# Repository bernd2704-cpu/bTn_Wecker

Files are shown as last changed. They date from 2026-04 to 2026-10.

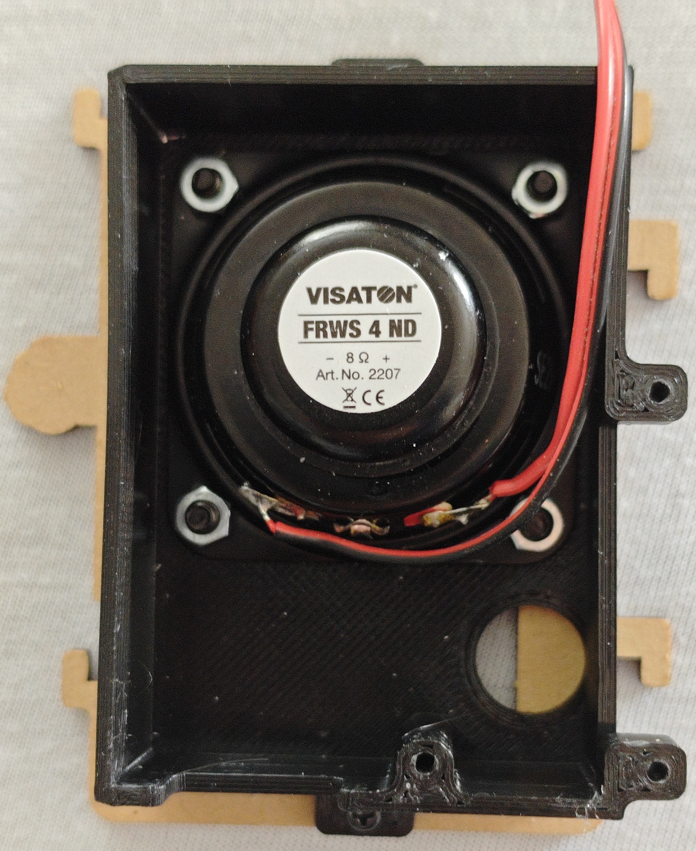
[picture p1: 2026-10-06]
Hardware/Fotos/Lautsprecher-Modul Gehäuse.jpg

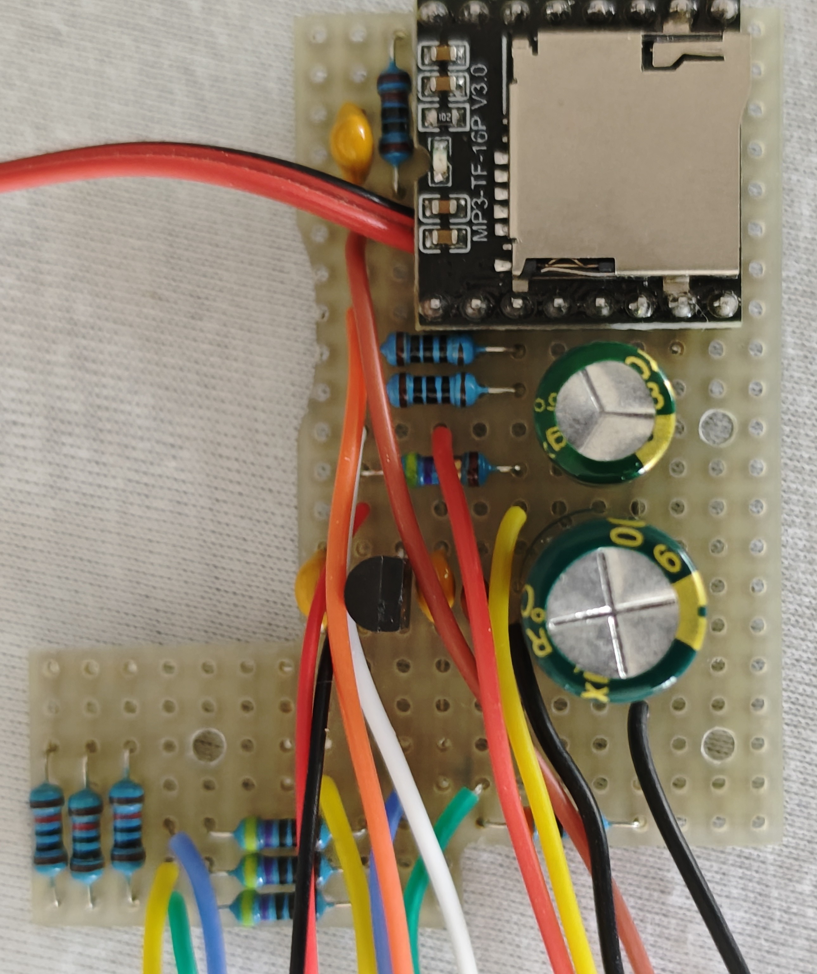
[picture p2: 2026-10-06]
Hardware/Fotos/Lautsprecher-Modul Bestückseite.jpg

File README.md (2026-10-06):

# bTn Wecker – Projektstruktur

## Übersicht

ESP32-basierter Wecker mit OLED-Anzeige, DFPlayer Mini (MP3),
kapazitiven Touch-Pads, FreeRTOS und WiFi/NTP.

Änderungshistorie siehe [CHANGELOG.md](CHANGELOG.md).

---

## Ordnerstruktur

```
bTn_Wecker_Projekt/
│
├── CHANGELOG.md           Änderungshistorie (alle Versionen)
│
├── Hardware/
│   ├── Schaltplan/        Schaltplan und PCB-Layout
│   ├── Stückliste/        Bauteilliste (BOM) – nicht versioniert, siehe unten
│   └── Fotos/             Fotos des Aufbaus
│
├── Software/
│   ├── Firmware_aktuell/  Aktuelle Firmware + Konfiguration
│   ├── Firmware_Versionshistorie/  Alle Vorgängerversionen
│   └── Bibliotheken/      Verwendete Arduino-Bibliotheken (Hinweise)
│
└── Dokumentation/
    ├── Bedienungsanleitung/  Kurzanleitung für den Endnutzer
    ├── Technisch/            Funktionsreferenz
    │   └── Review/           Audit-/Review-Notizen, Arbeitsanweisungen
    └── Diagramme/            State-Machine-Diagramme (Mermaid, .md = maßgeblich; DOC/ = veraltete PPTX/DOCX-Vorlage)
```

**Hinweis:** `Hardware/Stückliste/` enthält Hersteller-Datenblätter und Produktfotos
und ist per `.gitignore` von der Versionierung ausgeschlossen (Urheberrecht) –
lokal weiterhin vorhanden, im Repository nicht enthalten.

---

## Hardware

| Komponente | Beschreibung |
|---|---|
| ESP32 DevKit C V4 | Mikrocontroller, Dual-Core, WiFi |
| SSD1306 OLED | 128×64 px, I2C (0x3C, SDA=21, SCL=19) |
| DFPlayer Mini | MP3-Player, Serial2 (RX=16, TX=17) |
| Touch T0–T4 | GPIO4, GPIO2, GPIO15, GPIO13 |
| Taster S1–S3 | GPIO33, GPIO32, GPIO0 |
| Ausgänge E1–E3 | GPIO27 (Kuckuck) |
| | GPIO25 (Mühlrad) |
| | GPIO26 (Licht) |

---

## Software – Abhängigkeiten

| Bibliothek | Version | Quelle |
|---|---|---|
| ESP32 Arduino Core | 3.3.11 | Espressif |
| SSD1306Wire ESP32-ESP8266 | aktuell | Arduino Library |
| DFRobotDFPlayerMini | aktuell | Arduino Library |
| FreeRTOS | (im Core) | Espressif |

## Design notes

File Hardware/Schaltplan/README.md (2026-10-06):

# Schaltplan

| Datei | Inhalt |
|---|---|
| `Kuckuck-Treiber.md` | Ansteuerung Kuckuck (E1, GPIO27) |
| `LED-Treiber.md` | Ansteuerung LED-Streifen (E3, GPIO26) |
| `Motor-Treiber.md` | Ansteuerung DC-Motor (E2, GPIO25) |
| `Motor-LED-Treiber_Bauteilnotizen.md` | Bauteilauswahl/Dimensionierung zu Motor- und LED-Treiber |
| `DFPlayer-BUSY.md` | BUSY-Signal DFPlayer Mini → GPIO35, Pegelprüfung |
| `Pin_GPIO-Liste.md` | GPIO-Belegung ESP32 (belegt, frei, nicht nutzbar) |

Weitere Schaltplan-Dateien (z.B. KiCad, Eagle, PDF) hier ablegen.

Bauteillisten (BOM) zu den Treibern/Filtern: `Hardware/Stückliste/Stückliste.md`
(z.B. Abschnitt 3 „Motor-Treiber", Abschnitt 4 „DFPlayer-BUSY-Filter").

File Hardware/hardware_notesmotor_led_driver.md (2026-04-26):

# bTn Wecker – Hardware-Erweiterung: LED-Streifen & DC-Motor

## Versorgung
- Betriebsspannung Lastseite: 5V
- ESP32 GPIO-Pegel: 3,3V

---

## MOSFET: IRLML6344TRPBF (für beide Lasten)
- Logic-Level N-Channel, Vgs(th) = 0,4–1,0V → 3,3V GPIO tauglich
- Vds(max) = 20V, Id(max) = 5A
- Rds(on) bei Vgs=2,5V: ~30mΩ → Verlustleistung vernachlässigbar
- Bauform: SOT-23 (SMD)

### Beschaltung (gilt für beide Kanäle)
- Gate:  330Ω Reihenwiderstand zum GPIO
- Gate:  10kΩ Pull-Down nach GND (verhindert floating beim Boot/Reset)

---

## Kanal 1: LED-Streifen – GPIO27 (E3, Licht)
- Versorgung: 5V, Vf = 2,8V, If = 48mA
- Vorwiderstand: 47Ω / 0,25W in Serie (High-Side, zwischen 5V und LED+)
- Spannungsaufteilung: 2,2V am Widerstand, 2,8V an LED
- Freilaufdiode: nicht erforderlich (ohmsche Last)

---

## Kanal 2: DC-Motor – GPIO26 (E2, Wasserrad)
- Versorgung: 5V, Vnenn = 3V, Istall = 200mA
- Vorwiderstand: keiner (Strom ist lastabhängig → PWM statt Widerstand)
- Freilaufdiode: 1N4148, Kathode zu 5V, Anode zu Drain (schnelle Diode, <4ns)
- Entstörkondensator: 100nF Keramik direkt an den Motoranschlüssen

### PWM
```cpp
#define E2  26
ledcAttach(E2, 20000, 8);   // 20kHz, 8-Bit (über Hörschwelle → kein Surren)
ledcWrite(E2, 153);          // 60% Duty → ~3V Mittelwert
```

---

## Hinweise zur Integration
- GPIOs E2 (26) und E3 (27) sind bereits in SysConf_10v05.h definiert
- Stack-Größen und Task-Zuordnung gemäß bestehender SysConf-Konventionen
- Kein vTaskDelay() unter gehaltenem Mutex
- PWM-Initialisierung in setup() vor Task-Start

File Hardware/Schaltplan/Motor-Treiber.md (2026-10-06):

# Motortreiber

```
5V ── MCP1700T-3302E/TO ── 3,3V ──┬─────────┬────── Motor+ ──────┬────────────┐
      (LDO, In/Out je 100nF)      │         │         │          │    Kathode │
                                [100µF]   [100nF]   [Motor]   [10Ω+10nF]    [1N4448]
                                   │         │         │          │      Anode │
                                  GND       GND      Motor- ──────┴────────────┘
                                                       │
                                                       │
                                               Drain ──┘
GPIO25 ────────────────────── [470Ω] ────┬──── Gate             IRLML6344
                                         │     Source ─┐
                                      [10kΩ]           │
                                        │              │
                                       GND            GND
```

Motor liegt an der über MCP1700T-3302E/TO auf 3,3V geregelten Rail (seit Hardware 2v0,
ersetzt die bisherige Direktversorgung mit 5V ohne Regler). Der PWM-Duty-Bereich
0..255 moduliert damit maximal 3,3V statt vormals 5V – voller Regelumfang ohne
Begrenzung nutzbar, keine Überspannung am 3-V-Motor mehr möglich (auch nicht beim
Kickstart-Vollgasimpuls in `motorStart()`).
Freilaufdiode: 1N4448.

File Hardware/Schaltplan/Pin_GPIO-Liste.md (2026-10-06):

# bTn Wecker – GPIO-Belegung

Stand: Firmware 21v02 · Hardware 2v0 · ESP32 Dev Kit C V4

Quelle der Belegung: `SysConf_21v02.h` (Pin-Konstanten) und `CLAUDE.md`.
Bei jeder Pin-Änderung diese Liste mitpflegen.

## Pinbelegung

PIN = Pin-Nummer am ESP32 DevKitC V4 (Draufsicht, USB unten): J2 (linke Leiste) Pin 1–19 von oben nach unten,
J3 (rechte Leiste) Pin 20–38 von unten nach oben. `nc` = nicht beschaltet.

| PIN | GPIO | Konstante | Funktion | Betriebsart | Anmerkung |
| --- | ---- | --- | --- | --- | --- |
| 1 | – | – | 3V3 | Versorgung | |
| 2 | – | – | EN | Reset-Eingang | |
| 3 | 36 | – | nc | – | input-only (VP), keine Pull-ups |
| 4 | 39 | – | nc | – | input-only (VN), keine Pull-ups |
| 5 | 34 | – | nc | – | input-only, keine Pull-ups |
| 6 | 35 | DFPLAYER_BUSY | DFPlayer BUSY | Eingang (input-only) | seit 21v01 (vorher GPIO34), LOW = Wiedergabe |
| 7 | 32 | S2 | Taster S2 (Zugschalter Licht + Mühlrad)  | Eingang, Pull-up | seit 20v28 (vorher GPIO33) |
| 8 | 33 | S1 | Taster S1 (Alarm aus / Kuckuck einmalig) | Eingang, Pull-up | seit 20v28 (vorher GPIO32) |
| 9 | 25 | E2 | Mühlrad / Motor (MOSFET) | PWM 20 kHz, LEDC | seit 20v29 (vorher GPIO26) |
| 10  | 26 | E3 | LED-Licht (MOSFET) | Ausgang digital | seit 20v29 (vorher GPIO27) |
| 11  | 27 | E1 | Kuckuck (MOSFET) | Ausgang digital | seit 20v29 (vorher GPIO25) |
| 12  | 14 | – | nc | – | Touch T6, Ausgabe von PWM-Signal beim Boot |
| 13  | 12 | – | nc | – | Strapping-Pin (Flash-Spannung, MTDI): meiden, kann Boot verhindern |
| 14  | – | – | GND | Masse | |
| 15  | 13 | T4 | Touch T4 | Touch | |
| 16  | 9 | – | nc | – | Flash (SD2), nicht nutzbar |
| 17  | 10 | – | nc | – | Flash (SD3), nicht nutzbar |
| 18  | 11 | – | nc | – | Flash (CMD), nicht nutzbar |
| 19  | – | – | 5V | Versorgung | |
| 20  | 6 | – | nc | – | Flash (CLK), nicht nutzbar |
| 21  | 7 | – | nc | – | Flash (SD0), nicht nutzbar |
| 22  | 8 | – | nc | – | Flash (SD1), nicht nutzbar |
| 23  | 15 | T3 | Touch T3 | Touch | Strapping-Pin (Boot-Log) |
| 24  | 2 | T2 | Touch T2 | Touch | Strapping-Pin, beim Booten nicht HIGH treiben |
| 25  | 0 | S3 | Taster S3 (Info-Seite) | Eingang, Pull-up | Strapping-Pin: beim Reset LOW = Download-Modus |
| 26  | 4 | T0 | Touch T0 | Touch | |
| 27  | 16 | RXD2 | DFPlayer TX | UART2 RX | |
| 28  | 17 | TXD2 | DFPlayer RX | UART2 TX | |
| 29  | 5 | – | nc | – | Strapping-Pin (SDIO-Timing, Boot-Log), nur mit Vorbehalt |
| 30  | 18 | – | nc | – | unkritisch |
| 31  | 19 | OLED_SCL | OLED SCL | I2C | seit 21v02 (vorher GPIO22) |
| 32  | – | – | GND | Masse | |
| 33  | 21 | OLED_SDA | OLED SDA | I2C | |
| 34  | 3 | – | nc | – | RX0 (USB-Seriell / Flashen) |
| 35  | 1 | – | nc | – | TX0 (USB-Seriell / Debug) |
| 36  | 22 | – | nc | – | bis 21v01 OLED SCL |
| 37  | 23 | – | nc | – | unkritisch |
| 38  | – | – | GND | Masse | |

## Hinweise

- GPIO34, 35, 36 und 39 sind nur Eingänge und haben keine internen Pull-ups.
- Strapping-Pins (0, 2, 5, 12, 15) legen beim Reset den Boot-Modus fest. Externe
  Beschaltung darf den Pegel beim Einschalten nicht gegen den Default ziehen.
- I2C läuft über die GPIO-Matrix, deshalb darf SCL auf GPIO19 liegen.

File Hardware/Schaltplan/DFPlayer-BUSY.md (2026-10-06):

# DFPlayer BUSY-Signal

> **Status:** Aktiv ab Hardware 2v0 (verknüpft mit Firmware ab 20v00).
> Der vorherige eingefrorene Stand Hardware 1v0 / Firmware 13v00 hatte
> das BUSY-Signal nicht verdrahtet.

```
DFPlayer Mini                                    ESP32 DEV Kit C V4
BUSY (Pin 16) ──── [1kΩ] ────┬──────────────────── GPIO35
                              │
                           [100nF]
                              │
                             GND
```

## Pegel

DFPlayer Mini VCC = 5V. BUSY-Pin bleibt laut Datenblatt trotzdem auf
3,3V-TTL-Pegel (Modul-interne 3,3V-Logikdomain, unabhängig von VCC):

| Parameter | Wert | Bedingung  |
| --- | --- | --- |
| VOL | max. 0,33 V | VDD = 3,3V |
| VOH | min. 2,7 V | VDD = 3,3V |

Quelle: `Hardware/Stückliste/DFPlayer Mini/DFPlayer Mini Manual.pdf`,
Abschnitt „6. Note*“, sowie AZ-Delivery-Handbuch (bestätigt 3,3V-Logik
auch bei 5V-Versorgung, Serienwiderstand dort nur für RX empfohlen).

Direkter Anschluss an GPIO35 ohne Pegelwandler/Vorwiderstand zulässig:

- VOH min. 2,7V > ESP32 VIH (≈2,45V bei 3,3V-Logik)
- VOL max. 0,33V < ESP32 VIL (≈0,825V bei 3,3V-Logik)

## GPIO35

Input-only (kein internes Pull-up/-down, kein `INPUT_PULLUP` möglich).
Unkritisch, da BUSY aktiv getrieben wird (kein Open-Drain):
LOW = Wiedergabe läuft, HIGH = Pause/Idle.

Bis Firmware 20v32 lag BUSY an GPIO34 (ebenfalls input-only). Ab Firmware 21v01 liegt
BUSY an GPIO35, da dieser Pin im Header-Bereich des Anschlusses liegt und kein
zusätzliches Kabel nötig ist. Elektrisch gleichwertig (beide ADC1, input-only).

## RC-Filter (1kΩ + 100nF)

Firmware liest `dfPlayerBusy()` (GPIO35) an mehreren Stellen als einzelnen,
ungefilterten `digitalRead()` ohne Software-Debounce (anders als Touch-Pads
oder Taster). Ein Hardware-RC-Filter schließt diese Lücke:

- **R = 1 kΩ** (Reihe): konsistent mit Touch-Beschaltung und AZ-Delivery-
  Empfehlung für Serial-Leitungen; Spannungsabfall im stationären Zustand
  vernachlässigbar, da GPIO35-Eingangsleckstrom im nA-Bereich liegt.
- **C = 100 nF** (nach GND, GPIO-seitig): τ = R·C = 100 µs,
  Grenzfrequenz f_c ≈ 1,6 kHz – dämpft kurze EMI-Spitzen/Schaltflanken
  (u.a. vom 20kHz-Motor-PWM an E2, siehe `Motor-Treiber.md`) deutlich.

BUSY wechselt nur beim Start/Ende einer Wiedergabe (Sekundenbereich), nicht
taktend. Die Filter-Zeitkonstante ist damit >1000× schneller als das
schnellste Poll-Intervall der Firmware (200 ms im S1-Handling) – keine
spürbare Verzögerung für die Statusabfrage.

Ladestrom beim Umschalten: ΔV/R ≈ 3,3V / 1kΩ ≈ 3,3 mA – unkritisch für den
aktiv getriebenen DFPlayer-Ausgang (kein Open-Drain).

## Funktion

BUSY dient als Statusabfrage des DFPlayer (Wiedergabe läuft ja/nein),
unabhängig von der seriellen Kommunikation über Serial2 (RX=16, TX=17).
Ab Firmware 20v01/20v02 fließt der Status zusätzlich in Alarm-Polling,
Start-Verifikation (`verifyPlayStarted()`) und S1-Handling ein – siehe
`CHANGELOG.md`.

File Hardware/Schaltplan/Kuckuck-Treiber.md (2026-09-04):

# Kuckuck-Treiber

```
5V ────────┬─────────┬────────── Modul+ 
           │         │             │    
        [100µF]   [100nF]   [Kuckuck-Modul] 
           │         │             │    
          GND       GND          Modul- 
                                   │
                                   │
                           Drain ──┘
GPIO ──── [470Ω] ────┬──── Gate             IRLML6344
                     │     Source ─┐
                   [10kΩ]          │
                     │             │
                    GND           GND
```

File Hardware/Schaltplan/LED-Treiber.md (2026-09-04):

# LED-Treiber

```
5V ──────────── [47Ω / 0,25W]──── LED+
                                   │
                           LED-Streifen (2,8V / 48mA)
                                   │
                                  LED−
                                   │
                           Drain ──┘
GPIO ──── [470Ω] ────┬──── Gate             IRLML6344
                     │     Source ─┐
                   [10kΩ]          │
                     │             │
                    GND           GND

```

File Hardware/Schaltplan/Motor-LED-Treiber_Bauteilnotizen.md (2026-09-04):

# bTn Wecker – Hardware-Erweiterung: LED-Streifen & DC-Motor

Bauteilauswahl und Dimensionierung zu den Schaltplänen [Motor-Treiber.md](Motor-Treiber.md)
und [LED-Treiber.md](LED-Treiber.md).

## Versorgung
- Betriebsspannung Lastseite: 5V
- ESP32 GPIO-Pegel: 3,3V

---

## MOSFET: IRLML6344TRPBF (für beide Lasten)
- Logic-Level N-Channel, Vgs(th) = 0,4–1,0V → 3,3V GPIO tauglich
- Vds(max) = 20V, Id(max) = 5A
- Rds(on) bei Vgs=2,5V: ~30mΩ → Verlustleistung vernachlässigbar
- Bauform: SOT-23 (SMD)

### Beschaltung (gilt für beide Kanäle)
- Gate:  470Ω Reihenwiderstand zum GPIO
- Gate:  10kΩ Pull-Down nach GND (verhindert floating beim Boot/Reset)

---

## Kanal 1: LED-Streifen – GPIO26 (E3, Licht)
- Versorgung: 5V, Vf = 2,8V, If = 48mA
- Vorwiderstand: 47Ω / 0,25W in Serie (High-Side, zwischen 5V und LED+)
- Spannungsaufteilung: 2,2V am Widerstand, 2,8V an LED
- Freilaufdiode: nicht erforderlich (ohmsche Last)

---

## Kanal 2: DC-Motor – GPIO25 (E2, Wasserrad)
- Versorgung: 5V über LDO MCP1700T-3302E/TO auf 3,3V geregelt, Vnenn = 3V, Istall = 200mA
- Vorwiderstand: keiner (Strom ist lastabhängig → PWM statt Widerstand)
- Freilaufdiode: 1N4448, Kathode zu 3,3V-Rail, Anode zu Drain (schnelle Diode, <4ns)
- Entstörkondensator: 100nF Keramik direkt an den Motoranschlüssen

### PWM
```cpp
#define E2  25
ledcAttach(E2, 20000, 8);   // 20kHz, 8-Bit (über Hörschwelle → kein Surren)
ledcWrite(E2, 153);          // 60% Duty → ~2V Mittelwert (aus geregelten 3,3V)
```

### Gelöst: Kickstart-Überspannung (Stand 2026-08-21, Hardware-Änderung)

Bisherige Prüffrage (Stand 2026-08-20): `motorStart()` legt bei Sollwert unter
`MOTOR_PWM_KICK_THRESHOLD` für `MOTOR_PWM_KICK_MS` (150 ms) Duty 255
(`MOTOR_PWM_KICK_DUTY`) an. Solange der Motor direkt an 5V lag, bedeutete
Duty 255 durchgehend 5V statt der Nennspannung 3V (Faktor ~1,67×) – ungeklärt,
da kein Datenblatt für den verbauten Garosa-Getriebemotor 6mm 3V (ASIN
B085NG5ZCY) mit zulässiger Kurzzeit-/Spitzenspannung vorlag.

**Fix:** LDO MCP1700T-3302E/TO regelt die Rail vor dem MOSFET jetzt fest auf
3,3V. PWM schaltet diese geregelte Spannung statt der rohen 5V – Duty 255
bedeutet damit nur noch ~3,3V (Faktor ~1,1× Nennspannung), auch beim
Kickstart-Vollgasimpuls. Der volle PWM-Regelumfang 0..255 ist damit ohne
Begrenzung nutzbar, keine gesonderte Kickstart-Deckelung mehr nötig.

---

## Hinweise zur Integration
- GPIOs E2 (25) und E3 (26) sind in SysConf_*.h definiert (siehe `Software/Firmware_aktuell/`)
  (Belegung seit Firmware 20v29 / Schaltplan Hardware 2v0; vorher E2=26, E3=27)
- Stack-Größen und Task-Zuordnung gemäß bestehender SysConf-Konventionen
- Kein vTaskDelay() unter gehaltenem Mutex
- PWM-Initialisierung in setup() vor Task-Start

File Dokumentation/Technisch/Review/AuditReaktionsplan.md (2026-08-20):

# Audit-Reaktionsplan Firmware 13v00

Quelle: [2026-08-13-Audit-Firmware-13v00.md](2026-08-13-Audit-Firmware-13v00.md)
Zweck: die dortige „Empfohlene Reihenfolge" als abarbeitbare Checkliste mit Status.

## Status-Legende

`[ ]` offen · `[~]` in Arbeit · `[x]` erledigt · `[-]` zurückgestellt

## Zwischenstand 2026-08-18 (Gültigkeitsprüfung gegen 20v03)

Firmware ist ohne Bezug auf diesen Plan direkt von der Audit-Basis 13v00 auf 20v00
(Hardware 2v0, DFPlayer-BUSY-Signal GPIO34) gesprungen. Die 20v00–20v03-Änderungen
dienten der Hardware-Anbindung, haben aber als Nebeneffekt drei Befunde berührt:

- **C1 erledigt** – S1-Handler nutzt bei UART-Timeout jetzt `dfPlayerBusy()` statt
  blind `st = 0` zu setzen (`Wecker_20v03.ino:1752-1755`, seit 20v02). Laufender
  Alarm/Sound wird zuverlässig gestoppt statt fälschlich Kuckuck auszulösen.
- **A3 teilweise entschärft** – `runAlarmMachine()`/`ALARM_RUNNING` beendet den Alarm
  jetzt auch bei dauerhaftem `st == -1`, wenn `dfPlayerIdleDebounced()` das über den
  BUSY-Pin bestätigt (Z. 1474-1475, seit 20v01/20v03). Deckt den Audit-Hauptfall
  (Modul tot/TX-Leitung lose) ab. Der harte Zeit-Deckel `ALARM_MAX_RUN_MS` aus dem
  Fix-Vorschlag fehlt weiterhin – bleibt BUSY selbst dauerhaft LOW hängen, entwaffnet
  sich das Gerät wie beschrieben. Schritt 2 unten daher nur noch mit reduziertem Risiko,
  nicht als erledigt zu werten.
- **C3 nur am Rand berührt** – `verifyPlayStarted()` nutzt BUSY zusätzlich (Z. 1354),
  das hilft aber nur gegen „läuft eigentlich, UART lügt". Der Audit-Kernfall (Datei
  fehlt auf SD, Modul meldet `st == 0`, BUSY bestätigt korrekt „nicht busy" → trotzdem
  als Absturz behandelt, 2 Reboots, danach still) besteht unverändert. Schritt 6 bleibt offen.

Alle übrigen Befunde (A1, A2, A4–A6, B1, B2, C2, C4–C8, D1, D2, E1, E2, E4, E5) wurden
1:1 gegen `Wecker_20v03.ino`/`SysConf_20v03.h` verifiziert und sind unverändert gültig.

## Nicht antasten (Gesamtbild-Fazit des Audits)

Diese fünf Mechanismen funktionieren bereits korrekt und dürfen bei der Umsetzung nicht wegoptimiert werden:

- kein `vTaskDelay()` unter gehaltenem Mutex (Projektregel wird eingehalten)
- Zeitschnappschuss per `localtime_r()` je Task
- `rtosPanic()` bei halb gestartetem Systemzustand
- `ALARM_MAX_RESTARTS` (12v10) / `SERIAL2_DRAIN_MAX_BYTES` (12v11) als Deckel gegen Endlosschleifen
- TWDT-Init vor Task-Start (12v15/12v16)
- ACK-Modus (`player.begin(…, true, true)`) – Deaktivierung war bereits in 13v00 eine Regression

## Umsetzungsreihenfolge

- [x] **1. A5 + A1 gemeinsam** – Umgesetzt in **20v04** (`Wecker_20v04.ino`/`SysConf_20v04.h`).
  `timeValid()`-Gate vor jeder Alarm-/Kuckuck-Auswertung in `alarmTask` (A5); `alarmDue()` ersetzt
  die `sec == 0`-Flanke durch eine tagesbezogene, pegelbasierte Prüfung mit Nachholfenster
  `ALARM_CATCHUP_MIN = 60` (SysConf) – wie in der Review-Notiz gefordert auf 60 statt der
  ursprünglich vorgeschlagenen 15 gesetzt, deckt damit auch die März-DST-Lücke ab (A1). Die
  Fälligkeitsprüfung läuft weiterhin nur in `case ALARM_IDLE`, holt A2 aber automatisch nach, sobald
  `ALARM_RUNNING` endet, da die Tages-Sperre (nicht die Sekunde) das Kriterium ist (A4). Die
  Oktober-Doppelauslösung ist durch `lastCuckooDay`/`lastCuckooHour` statt `lastCuckooMin`
  ausgeschlossen (A6). `lastA1Min`/`lastA2Min` → `lastA1Day`/`lastA2Day`, ebenso in `inputTask`
  (S1-Handler) umgestellt – dort wurde die bisherige Sperren-Rücksetzung nach manuellem Stopp
  **entfernt** (offene Semantikfrage aus der Review-Notiz entschieden: Tages-Sperre bleibt nach
  manuellem Stopp bestehen, sonst würde die pegelbasierte Prüfung im nächsten 500-ms-Tick sofort
  wieder auslösen). `triggerAlarm()` setzt die Tages-Sperre über einen eigenen Zeitstempel erst nach
  erfolgreichem Start – macht A2 wie vorgesehen selbstheilend, ohne zusätzlichen Codepfad.
  Alte Version als `Software/Firmware_Versionshistorie/Wecker_20v03/` archiviert.
  **Noch nicht getestet:** Systemzeit-Sprung-Test (NTP-Attrappe), realer Alarm, DST-Übergänge.
- [x] **2. A3** – Umgesetzt in **20v05** (`Wecker_20v05.ino`/`SysConf_20v05.h`). Neue Konstante
  `ALARM_MAX_RUN_MS` (15 min, SysConf) und eigener Zeitstempel `alarmRunStart` (im Gegensatz zu
  `t_start6`, das als Poll-Timer bei jedem Poll zurückgesetzt wird) begrenzen `ALARM_RUNNING` hart.
  Deckt den Restfall aus der A3-Notiz ab: BUSY-Pin hängt selbst dauerhaft LOW,
  `dfPlayerIdleDebounced()` meldet nie „idle". Bei Auslösung durch die Obergrenze (nicht durch
  reguläres Alarmende) schreibt `runAlarmMachine()` einen `[FEHLER]`-Eintrag mit Laufzeit und
  letztem `playerStatus` ins Web-Log.
  **[x] C1 seit 20v02 erledigt** (`dfPlayerBusy()` statt blindem `st=0` im S1-Handler, Z. 1752-1755).
  Damit sind sowohl C1 als auch A3 vollständig abgedeckt.
  **Noch nicht getestet:** realer Alarm mit simuliertem BUSY-Hänger (Pin dauerhaft LOW erzwingen),
  Web-Log-Eintrag im Fehlerfall.
- [x] **3. B2** – Umgesetzt in **20v06** (`Wecker_20v06.ino`/`SysConf_20v06.h`). `triggerAlarm()`
  setzt den RTC-Merker jetzt direkt nach dem `playerMutex`-Take, vor `playFolder()`/
  `verifyPlayStarted()`, statt erst im bestätigten Fehlerpfad. `runAlarmMachine()` löscht ihn an
  zwei Stellen: sobald der erste Poll `playerStatus > 0` bestätigt (frühestmöglich), zusätzlich
  beim Alarmende (`mp3Finished`/`runTimeExceeded`) als Sicherheitsnetz für einen sehr kurzen Sound,
  der schon vor dem ersten Poll beendet war – ohne diese zweite Stelle bliebe der Merker sonst über
  das Alarmende hinaus gesetzt. Der watchdogTask-Freeze-Fallback (12v12) bleibt unverändert
  bestehen, ist jetzt aber redundant (Sicherheitsnetz für den Fall eines TWDT-Panics vor der
  30-s-Schwelle). Nach Schritt 1 (A1) umgesetzt wie gefordert – der Tages-Guard verhindert den in
  der Review-Notiz beschriebenen verspäteten Zweitalarm.
  **Noch nicht getestet:** gezielter Reset zwischen `playFolder()` und erstem Poll (z.B. `EN`-Taster
  während `ALARM_POLL_MS`-Fenster), Kontrolle dass `setup()` den Alarm danach korrekt nachholt.
- [x] **4. C5 + D1** – Umgesetzt in **20v07** (`Wecker_20v07.ino`/`SysConf_20v07.h`). Clamp von
  `sound1_assigned`/`sound2_assigned` läuft nur noch bei `mp3Count > 0`, sonst `[FEHLER]`-Log statt
  stillem Überschreiben mit 1 (C5). `data.begin()`-Rückgabewert an allen drei Stellen geprüft:
  `setup()` (NVR-Laden), `nvrTask()`, `bumpResetCount()` (D1). `nvrTask()` ruft bei Fehlschlag
  `markSafeChange()` statt den Commit stillschweigend zu verwerfen – nächster Versuch nach
  `NVR_COMMIT_DELAY_MS`. `readNVR()` läuft jetzt unabhängig vom `state`-Flag (die `getX()`-
  Fallbacks liefern beim ersten Boot ohnehin die Compile-Defaults). `webLogMutex`-Initialisierung
  vor das NVR-Laden gezogen, damit ein `data.begin()`-Fehlschlag dort sofort geloggt werden kann.
  **Noch nicht getestet:** `data.begin()`-Fehlschlag lässt sich ohne beschädigten NVS/Flash-Fehler
  kaum real provozieren – Codepfad nur durch Lesen verifiziert, nicht auf Hardware ausgelöst.
- [x] **5. B1 sekundär** – Umgesetzt in **20v08** (`Wecker_20v08.ino`/`SysConf_20v08.h`), abweichend
  vom Audit-Vorschlag. Wie von der Review-Notiz verlangt wurde der reale Worst-Case vorher
  nachgerechnet statt der Schätzwert übernommen: `verifyPlayStarted()` kann bei einem dauerhaft
  nicht antwortenden DFPlayer bis zu ~5,5–6 s blockieren (3× `VERIFY_PLAY_RETRIES`, je
  `VERIFY_PLAY_DELAY_MS` + Mutex-Take bis 200 ms + `readStateDrained()`-Gnadenfrist bei UART-
  Rauschen) – deckt sich mit der im Audit selbst hergeleiteten Summe ("Nicht bestätigt"-Abschnitt).
  Bei den vorgeschlagenen 6000/1000 wäre die Marge dazu praktisch null gewesen: ein nur
  ungewöhnlich langsamer, aber regulärer Alarmversuch hätte den Watchdog fälschlich als Freeze
  werten können – genau das „Fehlalarme erzeugen", vor dem die Notiz warnt. Stattdessen
  `WDG_TIMEOUT_MS`=10000/`WDG_CHECK_MS`=1000 gesetzt: Erkennung spätestens nach ~11 s, ca. 5 s
  Marge über dem berechneten Worst-Case, weiterhin ca. 4 s Marge unter den 15 s des TWDT (Software-
  Watchdog gewinnt jetzt wieder zuerst). Rechnung als Kommentar direkt bei den Konstanten in
  SysConf dokumentiert.
  **Noch nicht getestet:** Feldverhalten mit den neuen Schwellwerten (wie ursprünglich vom Audit
  vorgesehen) – insbesondere ob 10 s/1 s im Alltag Fehlalarme erzeugt oder echte Freezes zuverlässig
  erkennt, lässt sich nur auf der realen Hardware über längere Zeit beobachten.
- [x] **6. C3** – Umgesetzt in **20v09** (`Wecker_20v09.ino`/`SysConf_20v09.h`). `verifyPlayStarted()`
  liefert jetzt `PLAY_OK`/`PLAY_NO_SOUND`/`PLAY_CRASHED` statt `bool` – nur wenn nie eine Antwort
  ankam (`PLAY_CRASHED`), löst `triggerAlarm()` noch `ESP.restart()` aus. Kam mindestens einmal
  `st==0` an (`PLAY_NO_SOUND`), läuft der Alarm in denselben Erfolgspfad wie `PLAY_OK` (Motor/Licht
  an), statt zwei sinnlose Reboots auszulösen und danach still zu bleiben.
  **Zusammen mit A3 verifiziert** wie gefordert: neues Flag `alarmSilentFallback` hält
  `ALARM_RUNNING` bei `PLAY_NO_SOUND` am Laufen, obwohl `playerStatus` dauerhaft `0` meldet – ohne
  dieses Gate hätte `mp3Finished` den Alarm schon beim ersten Poll (5 s) sofort wieder beendet.
  Einziger Ausstieg dann `ALARM_MAX_RUN_MS` (A3) oder S1.
  **Zusätzlich beim Umsetzen entdeckt und mitbehoben:** der S1-Handler entschied bisher
  ausschließlich anhand des (möglicherweise stillen) Playerstatus, ob gestoppt oder Kuckuck
  ausgelöst wird – ein `alarmSilentFallback`-Alarm (playerStatus==0, Motor/Licht laufen aber
  tatsächlich) wäre von S1 NICHT gestoppt worden, sondern hätte versehentlich den Kuckuck
  ausgelöst. Jetzt `if (alarmState == ALARM_RUNNING || st > 0)` – genau die im ursprünglichen
  C1-Fix-Vorschlag des Audits genannte, aber in 20v02 nicht übernommene Bedingung.
  `readStateDrained()` wertet `DFPlayerError`-Frames vor dem Verwerfen aus und loggt den
  Fehlercode – macht „Datei fehlt" von „Modul abgestürzt" im Log erstmals unterscheidbar.
  „Optional auf Datei 1 zurückfallen" aus dem Audit-Fix-Vorschlag bewusst NICHT umgesetzt – hätte
  eine weitere blockierende playFolder()/verify-Runde eingeführt, genau zu der Zeit, in der Schritt 5
  die Watchdog-Marge knapp kalkuliert hat.
  **Noch nicht getestet:** realer Alarm mit absichtlich fehlender Sounddatei (auf Datei-Nummer
  zeigen, die nicht auf der SD-Karte existiert) – prüfen, dass Motor/Licht bis `ALARM_MAX_RUN_MS`
  laufen und S1 den Alarm zuverlässig stoppt.
- [x] **7. C4** – Umgesetzt in **20v10** (`Wecker_20v10.ino`/`SysConf_20v10.h`).
  `player.readFileCountsInFolder(1)` (0x4E) statt `player.readFileCounts()` (0x48) `- 1` – liefert
  die Dateizahl direkt für Ordner 01, kein Rechnen/Raten mehr über die Gesamtzahl aller Ordner.
  Bei Timeout bleibt `mp3Count` auf 0 statt auf den geratenen Fallback 99 – C5 (20v07) sperrt die
  Sound-Auswahl dann korrekt. UI-Auswahl war bereits vorher implizit gesperrt, solange
  `mp3Count == 0` (9v13-Fallback in den Touch-Handlern), keine Änderung dort nötig.
  **Noch nicht getestet:** neuer Bibliotheksaufruf (0x4E) auf realer Hardware – wie vom Reaktionsplan
  vorgesehen einzeln testen (mp3Count-Anzeige nach Boot mit bekannter SD-Karten-Dateizahl in
  Ordner 01 vergleichen).
- [x] **8. C2** – Umgesetzt in **20v11** (`Wecker_20v11.ino`/`SysConf_20v11.h`), zuletzt und
  ausdrücklich isoliert wie gefordert. Vor der Änderung Rollback-Punkt als Git-Tag `vor-C2-20v10`
  auf dem Stand nach Schritt 7 gesetzt (statt der ursprünglich vorgesehenen „Schritte 1–3" – zum
  Zeitpunkt der Umsetzung waren bereits alle Schritte 1–7 erledigt, der Tag markiert den
  tatsächlich unmittelbar vorherigen stabilen Stand). Gemeinsame fortschrittsbasierte Drain-
  Schleife `drainSerial2Progress()` ersetzt sowohl den Rückgabewert-Abbruch in `drainSerial2Pre()`
  als auch das Fehlen eines Vorab-Drains in `readStateDrained()` (jetzt VOR der eigenen
  `player.readState()`-Abfrage aufgerufen). Endlosschleife laut Review-Notiz ausgeschlossen: der
  äußere Schleifenkopf verlangt bereits `Serial2.available() >= DFPLAYER_RECEIVED_LENGTH`,
  `SERIAL2_DRAIN_MAX_BYTES` bleibt zusätzlich als harte Grenze.
  **Noch nicht getestet – das im Audit vorgesehene Testprotokoll steht komplett aus:** Kaltstart,
  Startsound, Sound-Vorschau beider Alarme, Lautstärkeänderung, echter Alarm, S1-Stopp, Alarm mit
  gezogener SD-Karte – jeweils mit offenem Web-Log, Blick auf „Serial2 Restbytes". Dieser Bereich
  hat bereits dreimal (12v09–12v14) Regressionen erzeugt – vor dem Einsatz als Wecker unbedingt
  auf echter Hardware durchspielen; bei Auffälligkeiten steht `git checkout vor-C2-20v10` als
  Rückfallebene bereit.
- [x] **9. E5** – Gemessen (2026-08-18, Bernd): Motor liegt direkt an 5V, kein Spannungsregler.
  Firmware/SysConf-Kommentare (`MOTOR_PWM_DUTY`=153 ≙ 60 % von 5V ≈ 3V) sowie
  `Motor-LED-Treiber_Bauteilnotizen.md` waren bereits korrekt und unverändert richtig – die
  Falschdarstellung lag ausschließlich in `Hardware/Schaltplan/Motor-Treiber.md` (AMS1117-3.3-LDO
  im Schaltplan) und `Hardware/Stückliste/Stückliste.md` (AMS1117-Zeile). Beide korrigiert: LDO aus
  dem Schaltplan entfernt (Motor jetzt direkt an 5V gezeichnet), AMS1117-Zeile aus der Stückliste
  gestrichen. Diodentyp-Widerspruch ebenfalls geklärt: real verbaut ist `1N4148` (wie SysConf und
  Bauteilnotizen schon sagten) – Schaltplan, Stückliste und `CLAUDE.md` (bisher `1N4448`)
  entsprechend korrigiert.
- [x] **10. Kleinere Punkte** – Umgesetzt in **20v12** (`Wecker_20v12.ino`/`SysConf_20v12.h`), bis
  auf zwei bewusst zurückgestellte Punkte:
  - [x] E1: `touchTask` erzwingt einen Reset auf `TS_IDLE` inkl. Baseline-Neuerfassung, wenn ein
    Pad länger als `TOUCH_MAX_HOLD_MS` (30 s) klemmt (`[WARNUNG]`-Log). `triggerAlarm()` sendet vor
    jedem Alarm `player.volume()` mit Untergrenze `ALARM_MIN_VOL` (10), unabhängig vom zuletzt
    gesendeten Wert – `vol` selbst bleibt unverändert.
  - [-] E2: **Zurückgestellt auf Nutzerwunsch** – S3 bleibt bewusst auf GPIO0, weil der vorhandene
    interne Boot-Taster des ESP32 DevKit C V4 dafür genutzt wird (kein zusätzliches Bauteil nötig).
  - [x] C6: Neues Flag `alarmCancelRequested`, gesetzt über `requestAlarmCancelIfActive()` in S1,
    Sound-Vorschau-Stopp und Funktionswahl-Menü, bevor deren `player.stop()` einen laufenden
    Alarmversuch treffen könnte. `verifyPlayStarted()` liefert dann `PLAY_CANCELLED` statt
    `PLAY_CRASHED` – `triggerAlarm()` bricht sauber ab (Tages-Sperre trotzdem via
    `lockAlarmDayGuard()` gesetzt) statt neu zu starten oder `alarmSilentFallback` zu aktivieren.
  - [x] C7: `onClock()` (T3/T4) und `checkboxSound()` ändern `vol`/`sound*_assigned`, Anzeige und
    `markSafeChange()` jetzt erst nach erfolgreichem `playerMutex`-Take; Fehlschlag als `[FEHLER]`
    geloggt statt stillschweigend ignoriert.
  - [x] D2: `html.reserve()` von 8192 auf 12288 angehoben (Audit-Minimalvorschlag statt
    vollständigem Umbau auf `sendContent()`-Streaming); `/log`-Handler reserviert jetzt ebenfalls
    (`out.reserve(6144)`, vorher gar nicht).
  - [-] E4: **Zurückgestellt auf Nutzerwunsch** – auf die Bestätigungsabfrage für T3
    (WLAN-Zugangsdaten löschen) wird bewusst verzichtet.
  **Noch nicht getestet:** klemmendes Touch-Pad simulieren (Finger dauerhaft auflegen, 30 s warten,
  Web-Log auf `[WARNUNG]` prüfen); Alarm bei vol=0 auslösen und Lautstärke am Lautsprecher prüfen;
  S1/Vorschau-Stopp exakt im Verifikationsfenster (schwer gezielt reproduzierbar, am ehesten durch
  wiederholte Alarme mit sofortigem S1-Druck); `/`- und `/log`-Seite nach längerer Laufzeit mit
  vollem Ringpuffer aufrufen.
- [x] **11. Zweizeiler aus „Ungeprüft geblieben"** – Umgesetzt in **20v13**
  (`Wecker_20v13.ino`/`SysConf_20v13.h`), letzter Punkt der Umsetzungsreihenfolge.
  - [x] Rückgabewerte von `esp_task_wdt_add(NULL)` (in `inputTask`/`displayTask`/`alarmTask`) sowie
    `esp_task_wdt_init()`/`esp_task_wdt_reconfigure()` in `setup()` werden jetzt ausgewertet;
    Fehlschlag wird als `[FEHLER]` geloggt statt „[TWDT] Hardware Watchdog aktiv" blind zu behaupten.
  - [x] `webLog("[NTP] Synchronisation OK")` und `snapTimeStr(snapNtpTime, …)` laufen jetzt nur noch
    bei tatsächlichem NTP-Erfolg (`ntpTimedOut`-Flag), nicht mehr unbedingt nach der Warteschleife.
  **Noch nicht getestet:** beide Fehlerpfade sind auf reeller Hardware kaum gezielt provozierbar
  (TWDT-Anmeldefehler, NTP-Timeout erfordert getrennten Router/DNS-Ausfall bei sonst funktionierendem
  WLAN) – nur durch Lesen verifiziert.

Damit ist die Umsetzungsreihenfolge des Audit-Reaktionsplans (Schritte 1–11) vollständig
abgearbeitet. Offen bleiben nur noch die nie gegengeprüften Punkte unter „Offene Prüfpunkte" unten.

## Vor dem produktiven Einsatz: Hardware-Test erforderlich

Ein Großteil der Änderungen aus den Schritten 1–11 (Firmware 13v00 → 20v13) ist bisher **nur
gelesen, nie auf echter Hardware getestet** – siehe die „Noch nicht getestet"-Hinweise bei jedem
einzelnen Schritt oben. Besonders die sicherheitskritischen Pfade aus Schritt 1 (A1/A5,
Alarmfälligkeit), Schritt 3 (B2, Crash-Recovery), Schritt 6 (C3, stummer Alarm) und Schritt 8 (C2,
zuletzt und ausdrücklich isoliert wegen dreifacher Regressionshistorie 12v09–12v14) verändern das
Alarmverhalten selbst.

**Vor dem Einsatz als Wecker mindestens folgendes durchspielen:**

1. Kompletter Testdurchlauf aus Schritt 8: Kaltstart, Startsound, Sound-Vorschau beider Alarme,
   Lautstärkeänderung, echter Alarm, S1-Stopp, Alarm mit gezogener SD-Karte – jeweils mit offenem
   Web-Log, Blick auf „Serial2 Restbytes".
2. Alarm mit absichtlich fehlender Sounddatei auslösen (Schritt 6) – sicherheitskritischster Pfad:
   prüfen, dass Motor/Licht angehen und S1 den Alarm zuverlässig stoppt.
3. Systemzeit-Sprung-Test (Schritt 1, z.B. NTP-Server-Attrappe) sowie ein regulärer, echter Alarm.

Bei Auffälligkeiten steht der Git-Tag `vor-C2-20v10` als Rollback-Punkt unmittelbar vor dem
riskantesten Einzelschritt (C2) bereit.

## Bewusst nicht umgesetzt

- **DFPlayer-Library-Patch** (`sendStack()`/`available()`): Audit hat die vermutete Ursache
  eines 15-s-TWDT-Hängers widerlegt (rechnerisch max. ~5,5–6 s). 12v14-Rücknahme des Patches war
  richtig, kein erneuter Eingriff in `DFRobotDFPlayerMini.cpp`.
- **E3** (Kuckuck-Treiber ohne Freilaufdiode): Energie im Abschaltfall liegt laut Rechnung
  Größenordnungen unter der MOSFET-EAS-Grenze bei ~20 Schaltvorgängen/Tag. Diode als gute Praxis
  optional, nicht dringend.

## Offene Prüfpunkte (im Audit selbst ungeprüft)

Aus Kapazitätsgründen nicht gegengeprüft, bei Gelegenheit einordnen:

- `STACK_WATCHDOG = 1344` im Fehlerzweig (webLogf + vsnprintf + 3× SSD1306) – Stack-Reserve fraglich
- Race auf `motorRunning`/E2 zwischen Kickstart und `/motor`-HTTP-Handler
- ungeschützte Snapshot-Strings im HTTP-Handler
- `nvs_flash_erase()` beim Werksreset ohne Anhalten des `nvrTask`
- `WEB.h`/WiFi-Konfigurator: keine Eingabevalidierung der POST-Parameter geprüft
- UI-State-Machine (`uiDispatch`, `menu()`) nur dort gelesen, wo sie Player-/NVR-Zustand berührt
- Touch-Kalibrierung nicht auf Fehlauslösung durch Netzbrummen geprüft
- Heap-Fragmentierung über Wochen Laufzeit (WebServer/lwIP) nicht gemessen
- Motor-Kickstart (`MOTOR_PWM_KICK_DUTY = 255`, `motorStart()`, Wecker_20v19.ino:1503-1508) legt für
  `MOTOR_PWM_KICK_MS` (150 ms) die volle 5V-Schienenspannung an den 3V-Getriebemotor an (Duty 100 %
  bei 20 kHz = durchgehend 5V, keine PWM-Mittelung). Kein Datenblatt für den verbauten Motor
  (Garosa-Getriebemotor 6mm 3V, Stückliste) mit einer zulässigen Kurzzeit-/Spitzenspannung geprüft –
  nur `Vnenn=3V, Istall=200mA` dokumentiert (`Motor-LED-Treiber_Bauteilnotizen.md`). Verstößt gegen
  die Projektregel „alle Grenzwerte explizit gegen Datenblatt prüfen". Siehe offene Prüffrage +
  möglicher Fix in `Motor-LED-Treiber_Bauteilnotizen.md`.

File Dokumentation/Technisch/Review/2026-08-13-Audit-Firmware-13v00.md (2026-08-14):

# Audit Firmware 13v00 – Zuverlässigkeit

## Gesamtbild

Die Firmware ist handwerklich deutlich besser als der Durchschnitt vergleichbarer Arduino-Projekte: die Projektregel „kein `vTaskDelay()` unter Mutex" wird in allen geprüften Pfaden tatsächlich eingehalten (`verifyPlayStarted()` Z. 1320, S1-Retry Z. 1715, ALARM_RUNNING-Poll Z. 1426/1428), der Zeitschnappschuss per `localtime_r()` je Task (Z. 1955-1961) eliminiert eine reale Race gegen `displayTask`, `rtosPanic()` verhindert einen halb gestarteten Systemzustand, `ALARM_MAX_RESTARTS` (12v10) und `SERIAL2_DRAIN_MAX_BYTES` (12v11) sind genau die Deckel, die Endlos-Neustartschleifen bzw. Endlos-Drains verhindern, und die TWDT-Initialisierung vor dem Task-Start (12v15/12v16) ist korrekt und richtig begründet. **Diese fünf Mechanismen bitte nicht wegoptimieren** – ebenso wenig den ACK-Modus (`player.begin(…, true, true)`, Z. 2485), dessen Deaktivierung in 13v00 bereits eine Regression war.

Das Restrisiko liegt nicht in der Nebenläufigkeit, sondern in drei strukturellen Punkten: **(A)** die Alarm-Fälligkeit ist eine reine Flanke auf `sec == 0` im Zustand `ALARM_IDLE` – jedes verpasste Ereignis (Zeitsprung, Reboot, blockierter Tick, laufender Vor-Alarm) löscht den Alarm des Tages ersatzlos und ohne einen einzigen Log-Eintrag; **(B)** die gesamte Absturz-Wiederherstellung hängt an `rtcRetryMagic`, das ausschließlich im DFPlayer-Fehlerpfad gesetzt wird – der 12v12-Ersatzalarm ist wegen `WDT_HARDWARE_MS (15 s) < WDG_TIMEOUT_MS (30 s)` faktisch toter Code; **(C)** der DFPlayer-Status ist die einzige Entscheidungsgrundlage für Stopp, Erfolg und Zustandswechsel, wobei `st == 0` (Modul antwortet, ist gestoppt) und `st == -1` (Modul tot) an mehreren Stellen bewusst verschieden, an anderen fälschlich gleich behandelt werden.

Kein einziger dieser Pfade schreibt beim Scheitern eine `[FEHLER]`-Zeile ins Web-Log. Der schlimmste Ausgang – Wecker bleibt stumm – ist damit nicht nur möglich, sondern auch nachträglich nicht diagnostizierbar.

---

## Befunde

### Ursachengruppe A – Alarmfälligkeit ist eine Flanke ohne Nachholung

Die Befunde A1–A6 haben genau eine Wurzel: `runAlarmMachine()` prüft `a1_*`/`a2_*` nur im `case ALARM_IDLE` und nur bei exakt `sec == 0`, die Wiederholsperre ist eine reine Minutenzahl ohne Datum. Ein einziger Umbau (pegel- statt flankenbasierte, tagesbezogene Fälligkeitsprüfung außerhalb des `switch`, plus Zeit-Gültigkeitsgate und Maximallaufzeit) behebt A1, A2, A4, A5 und A6 gemeinsam. Einzeln zu flicken lohnt hier nicht.

---

### [Kritisch] A1 – Alarm nur bei exakt `sec == 0`, kein Nachholmechanismus

- **Ort:** `Software/Firmware_aktuell/Wecker_13v00.ino:1409` und `:1414` (`runAlarmMachine`)
- **Was passiert:** Bedingung ist `a1_on && sec == 0 && min == a1_min && hour == a1_hour && min != lastA1Min`. Wird diese eine Sekunde nicht beobachtet, existiert kein Codepfad, der eine bereits verstrichene Alarmminute nachprüft. `lastA1Min`/`lastA2Min` (Z. 1439-1440) sperren nur Wiederholungen, sie holen nichts nach.
- **Wann es passiert:** (a) **Harter NTP-Zeitsprung** – die Hardware hat keine gepufferte RTC. Nach Stromausfall bootet das Gerät mit Epoch 0 (lokal 01:00). `configTime(0, 0, MY_NTP_SERVER)` (Z. 2371) lässt den Sync-Modus auf dem ESP-IDF-Default (`SNTP_SYNC_MODE_IMMED`, harter `settimeofday`-Sprung). Kommt der Router/DSL erst um 06:02 hoch, springt die Uhr in einem Schritt von 1970 auf 06:02 – die Sekunde 06:00:00 existiert nie, Alarm 1 fällt aus. Dieser Fall ist nach jedem nächtlichen Stromausfall der Normalfall, nicht der Ausnahmefall. (b) **Reboot im Alarmfenster** – Brownout/TWDT-Panic/`watchdogTask`-Restart um 05:59:45; `setup()` braucht minimal ~14 s (3000 ms Z. 2325 + 2000 ms Z. 2329 + `player.begin()`-Reset + 4000 ms Startsound Z. 2510), mit WiFi-/NTP-/MP3-Timeouts bis ~80 s. (c) **Märzumstellung** – 01:59:59 → 03:00:00, ein Alarm auf 02:30 existiert an diesem Tag nicht.
- **Warum es zählt:** Genau der Worst Case des Geräts: stiller, unprotokollierter Alarmausfall nach einem Alltagsereignis. Der Kommentar Z. 1403-1407 unterstellt, ein Folge-Tick liege noch in derselben Sekunde 0 – bei 500-ms-Takt (Z. 1965) und 200 ms Mutex-Timeout stimmt das nur in etwa 60 % der Phasenlagen.
- **Fix:** Fälligkeit tagesbezogen und als Pegel prüfen, mit begrenztem Nachholfenster:

```cpp
static uint16_t lastA1Day = 0xFFFF;                                                      // tm_yday des zuletzt behandelten Auslösetags
static uint16_t lastA2Day = 0xFFFF;

static bool alarmDue(bool on, uint8_t h, uint8_t m,
                     uint8_t hour, uint8_t min, uint16_t yday, uint16_t lastDay) {
  if (!on || yday == lastDay) { return false; }
  int16_t diff = (int16_t)(hour * 60 + min) - (int16_t)(h * 60 + m);
  return (diff >= 0 && diff <= ALARM_CATCHUP_MIN);                                       // Nachholfenster fängt Zeitsprünge und Reboots ab
}
```
  `ALARM_CATCHUP_MIN` (z.B. 15) neu in SysConf. `lastA1Day`/`lastA2Day` in `triggerAlarm()` statt `lastA1Min` setzen; die Minutensperren entfallen dadurch ersatzlos, ebenso ihr Reset in Z. 1439-1440. Analog `runCuckooMachine()` (Z. 1456) – dort genügt eine Sperre auf `hour` statt `min`.
- **Sicherheit des Befunds:** Bestätigt, beide Prüfer unabhängig, alle Zeilenangaben verifiziert. Offene Annahme: SNTP-Default-Sync-Modus (ESP-IDF-Kernverhalten, kein Bibliotheksinternum).
- **Notiz (Review 2026-08-14):** `ALARM_CATCHUP_MIN = 15` ist zu knapp für den in diesem Befund selbst genannten Auslöser (c) Märzumstellung: beim Sprung 01:59:59 → 03:00:00 fehlt eine Alarmminute um bis zu 60 Minuten (Alarm 02:00 → Diff 60, Alarm 02:44 → Diff 16), beide über dem Beispielwert. Der Wert muss entweder auf ≥60 angehoben oder die DST-Vorwärtslücke separat behandelt werden – sonst holt der eigene Fix genau den Fall nicht nach, den er laut Begründung mit abdecken soll. Zusätzlich: `lastA1Min`/`lastA2Min` werden nicht nur hier verwendet, sondern auch im S1-Handler (`inputTask`, Z. 1730-1732) und `lastCuckooMin` in Z. 1744 zurückgesetzt/gesetzt – der Umbau auf `lastA*Day` muss diese Stelle einschließen (Semantikfrage: soll ein manuell gestoppter Alarm für den Rest des Tages gesperrt bleiben?), sonst bleibt dort ein inkonsistenter Mischzustand aus Minuten- und Tages-Logik stehen. Diese Stelle überschneidet sich mit C1 und sollte nicht getrennt umgesetzt werden.

---

### [Kritisch] A2 – `triggerAlarm()`: fehlgeschlagener `playerMutex`-Take lässt den Alarm still ausfallen

- **Ort:** `Software/Firmware_aktuell/Wecker_13v00.ino:1347` (`triggerAlarm`)
- **Was passiert:** `if (xSemaphoreTake(playerMutex, pdMS_TO_TICKS(200)) == pdTRUE) { … }` hat keinen `else`-Zweig; die Funktion endet Z. 1395 stillschweigend. Kein Ton, kein Web-Log, kein `rtcRetryMagic`, kein `alarmTriggerInFlight`, kein Zustandswechsel. Da `alarmTriggerInFlight` false bleibt, greift auch der `watchdogTask`-Ersatzalarm (Z. 2070) nicht.
- **Wann es passiert:** Ein konkurrierender `playerMutex`-Halter hält die Sperre in der Alarmsekunde über 200 ms: S1-Handler (Z. 1703/1716/1723), Sound-Vorschau (Z. 562/570/583/591), Lautstärke (Z. 959/974), Menüseite 5 (Z. 672). Weil ein Fehlversuch selbst 200 ms kostet und der Folge-Tick 700 ms später liegt, gibt es in rund 40 % der Phasenlagen nur einen einzigen Versuch – ein einzelner Timeout genügt.
- **Warum es zählt:** Alarm fällt für den Tag aus, ohne eine einzige Log-Zeile. Der zweite Prüfer stuft das auf „mittel" herab, weil ein Halter >200 ms einen trägen DFPlayer voraussetzt und die Kollision Bedienung in der Alarmsekunde erfordert. Beides stimmt – die Folgenlosigkeit im Log macht den Fall trotzdem inakzeptabel.
- **Fix:** Fehlschlag protokollieren und den Alarmwunsch vom Player-Zugriff entkoppeln. Mit dem A1-Fix genügt: bei Take-Fehlschlag `webLogf("[FEHLER] …")` und **kein** Setzen von `lastA*Day` – das Nachholfenster sorgt dann automatisch für den Wiederholversuch im nächsten Tick. `alarmTriggerInFlight` zusätzlich **vor** dem Take setzen, damit der Freeze-Fallback greift.
- **Sicherheit des Befunds:** Bestätigt (Codestruktur eindeutig). Umstritten ist nur die Häufigkeit; die für lange Haltezeiten maßgebliche Blockierdauer von `player.readState()` ist ohne Bibliotheksquellen nicht hart belegbar.
- **Notiz (Review 2026-08-14):** Der Fix verlangt, `alarmTriggerInFlight` vor dem Take zu setzen, damit der Watchdog-Freeze-Fallback greift (Z. 2070-2078) – dieser Fallback ist laut B1 aber bis zum B1-Fix toter Code (TWDT feuert immer zuerst). D.h. dieser Teil von A2 ist real erst wirksam, nachdem B1 (oder mindestens dessen primäre Maßnahme B2) umgesetzt ist. Das Web-Log bei Take-Fehlschlag und der Verzicht auf `lastA*Day`-Setzen wirken dagegen unabhängig davon sofort.

---

### [Kritisch] A3 – `ALARM_RUNNING` endet bei dauerhaftem `st == -1` nie: Gerät bleibt für immer entwaffnet

- **Ort:** `Software/Firmware_aktuell/Wecker_13v00.ino:1436` (`runAlarmMachine`)
- **Was passiert:** Einziger Ausstieg ist `playerStatus == 0`. `t_start6` wird bei jedem Poll neu gesetzt (Z. 1435) und ist damit reiner Poll-Timer, keine Laufzeitgrenze. Liefert `readStateDrained()` dauerhaft -1, bleibt der Zustand für immer stehen. Da `a1_*`/`a2_*` ausschließlich im `case ALARM_IDLE` geprüft werden, wird ab diesem Moment **kein einziger weiterer Alarm mehr ausgelöst**.
- **Wann es passiert:** Alarm startet, `verifyPlayStarted()` bestätigt `st > 0` → `ALARM_RUNNING`. Danach fällt die DFPlayer-Antwort aus (TX-Leitung lose, Modul-Brownout beim Motoranlauf, SD-Karte gezogen). Motor (E2) und Licht (E3) laufen unbegrenzt weiter. S1 rettet nicht: die Retry-Schleife Z. 1710-1721 erzwingt nach 200 ms `st = 0`, landet damit im `else`-Zweig (Kuckuck, Z. 1733-1745) und fasst weder `alarmState` noch E2/E3 an. Der 30-min-Deckel Z. 1930 hängt an `S2_SW` und greift nicht. Der `watchdogTask` greift nicht, weil `alarmTask` normal weiterläuft (Kommentar Z. 2044 sagt das ausdrücklich).
- **Warum es zählt:** Der Wecker ist danach dauerhaft tot, ohne Fehlermeldung, und nur ein Stromausfall/Reset stellt ihn her – ausgerechnet der Neustart, der wegen `player.begin(…, doReset=true)` das hängende Modul geheilt hätte, findet nicht statt. Schaltet der Nutzer die sichtbare Last per S2 ab, verschwindet auch noch das Symptom. Die 12v05-Historie (SysConf Z. 180-182) benennt genau dieses Risiko; behoben wurde damals nur der Startcheck.
- **Fix:** Harte Obergrenze in `ALARM_RUNNING`, mit eigenem Zeitstempel (nicht `t_start6`, der wird zurückgesetzt):

```cpp
if (playerStatus == 0 || millis() - alarmRunStart >= ALARM_MAX_RUN_MS) {
  if (playerStatus != 0) {
    webLogf("[FEHLER] Alarm ohne DFPlayer-Rueckmeldung nach %lu ms beendet",
            (unsigned long)(millis() - alarmRunStart));
  }
  motorStop();
  …
}
```
  `alarmRunStart = millis()` in `triggerAlarm()` neben Z. 1391 setzen, `ALARM_MAX_RUN_MS` (10–15 min) in SysConf. Zusätzlich S1 unabhängig vom Playerstatus wirken lassen, solange `alarmState == ALARM_RUNNING` (siehe C1).
- **Sicherheit des Befunds:** Bestätigt, beide Prüfer, alle Zeilen verifiziert.

---

### [Hoch] A4 – Alarm 2 wird während laufendem Alarm 1 nie geprüft

- **Ort:** `Software/Firmware_aktuell/Wecker_13v00.ino:1420` (`runAlarmMachine`, `case ALARM_RUNNING`)
- **Was passiert:** Die Fälligkeitsprüfung liegt komplett im `case ALARM_IDLE`. Steht die Maschine zur Fälligkeitszeit von A2 in `ALARM_RUNNING`, wird A2 in diesem Tick nicht geprüft – und die `sec == 0`-Flanke kommt nicht wieder.
- **Wann es passiert:** A1 = 06:00, A2 = 06:05 als Sicherheitsnetz, A1-Titel länger als 5 Minuten (der Nutzer hat ihn verschlafen). Endet A1 um 06:07, werden die Sperren zurückgesetzt – 06:05:00 ist längst vorbei, A2 fällt ersatzlos aus. In Kombination mit A3 fallen alle Folgealarme aus.
- **Warum es zählt:** Genau der Fall, für den A2 konfiguriert wurde, versagt. (Ein Prüfer stuft auf „mittel", weil das Gerät zur Fälligkeitssekunde nicht stumm ist und die Konstellation überlappende Alarmzeiten voraussetzt – korrekt, ändert aber nichts daran, dass das Sicherheitsnetz reißt.)
- **Fix:** Mit dem A1-Fix erledigt: `alarmDue()` in jedem Tick auswerten, unabhängig vom Zustand. Bei Treffer während `ALARM_RUNNING` den fälligen Alarm merken und beim Übergang nach `ALARM_IDLE` nachziehen (das Nachholfenster begrenzt das automatisch).
- **Sicherheit des Befunds:** Bestätigt. Die im Ursprungsbefund genannte Begründung über `ALARM_POLL_MS` ist falsch (das Ende wird alle 5 s geprüft, nicht erst nach Minuten) – am Mechanismus ändert das nichts.

---

### [Hoch] A5 – Alarm und Kuckuck laufen ungeprüft auf der ungestellten 1970-Uhr

- **Ort:** `Software/Firmware_aktuell/Wecker_13v00.ino:1962` (`alarmTask`)
- **Was passiert:** Der Zeitschnappschuss geht ohne jede Gültigkeitsprüfung an beide State Machines. Ohne NTP steht die Systemzeit auf Epoch 0, mit `MY_TZ` also 01:00:00 ab Bootzeitpunkt. Das Projekt kennt beide Prüfungen (`tm_year < 71` Z. 2423, `t > 1700000000UL` Z. 300), benutzt sie im Alarmpfad aber nicht.
- **Wann es passiert:** Stromausfall, WLAN kommt nicht zurück (falsches PSK, defekter Router). WiFi-Timeout nach 30 s, der NTP-Block (nur unter `if (wifiConnected)`, Z. 2403) wird übersprungen. Nach 5 h Uptime erreicht die Fake-Uhr 06:00:00 und löst Alarm 1 samt Motor und Licht mitten am Tag aus; ab dann schlägt bei aktiviertem Kuckuck stündlich der Magnet 7,5 s.
- **Warum es zählt:** Fehlalarm zu beliebiger Tageszeit. Wichtiger noch: **ohne dieses Gate ist der A1-Fix gefährlich** – eine pegelbasierte Prüfung würde auf der 1970-Uhr sofort nach Boot feuern. Das Gate ist Voraussetzung, nicht Zusatz.
- **Fix:**

```cpp
static inline bool timeValid() { return time(nullptr) > 1700000000UL; }
```
  In `alarmTask` vor Z. 1962: `if (!timeValid()) { wdg_alarmTask = millis(); vTaskDelay(…); continue; }`. Optional die Uhr im Display als `--:--:--` zeigen, solange ungültig.
- **Sicherheit des Befunds:** Bestätigt. Ein Prüfer stuft auf „mittel", weil das Display „01.01.1970" zeigt und `cuckoo_on` per Default aus ist – beides zutreffend.

---

### [Mittel] A6 – Oktober-Zeitumstellung: Alarm zwischen 02:00 und 02:59 löst zweimal aus

- **Ort:** `Software/Firmware_aktuell/Wecker_13v00.ino:1439` (`runAlarmMachine`)
- **Was passiert:** `lastA1Min`/`lastA2Min` sind reine Minutenzahlen ohne Datumsbezug und werden beim Titelende auf 0xFF zurückgesetzt.
- **Wann es passiert:** Letzter Sonntag im Oktober, `MY_TZ = "CET-1CEST,M3.5.0/02,M10.5.0/03"`: die Ortszeit durchläuft 02:00–02:59 zweimal. Ein Alarm auf 02:30 startet beim zweiten Durchlauf erneut. Analog der Kuckuck bei 02:00 (`lastCuckooMin`, Z. 1467/1478).
- **Warum es zählt:** Zusätzlicher Nachtalarm, einmal jährlich, nur bei Alarmzeiten in dieser Stunde. Störend, nicht kritisch.
- **Fix:** Mit dem A1-Fix erledigt (`lastA*Day` statt `lastA*Min`).
- **Sicherheit des Befunds:** Bestätigt, beide Prüfer.

---

### Ursachengruppe B – Crash-Recovery hängt an einem Merker, der zu selten und zu früh gelöscht wird

`rtcRetryMagic` ist der einzige Zustand, der einen Reset übersteht. Er wird nur im DFPlayer-Fehlerpfad gesetzt (Z. 1378-1382) und im Watchdog-Freeze-Zweig (Z. 2075), der praktisch nie erreicht wird. Jeder andere Reset – Power-On, Brownout, TWDT-Panic, `watchdogTask`-Restart wegen input-/displayTask-Freeze – verliert einen laufenden oder gerade startenden Alarm ersatzlos.

---

### [Hoch] B1 – Hardware-TWDT (15 s) feuert immer vor dem App-Watchdog (30 s): Ersatzalarm-Fallback ist toter Code

- **Ort:** `Software/Firmware_aktuell/Wecker_13v00.ino:2070` (`watchdogTask`), Konstanten `SysConf_13v00.h:423-425`
- **Was passiert:** In allen drei überwachten Tasks liegen `esp_task_wdt_reset()` und das `wdg_*`-Alive-Signal in derselben Schleifeniteration (Z. 1652/1654+1661, 1849/1850, 1950/1964). Jeder Hänger stoppt zwangsläufig beide Zähler. Der TWDT löst nach 15 s per Panic aus; `watchdogTask` bräuchte 30 s plus bis zu 5 s Prüfraster. Der gesamte Freeze-Zweig ab Z. 2059 inklusive der 12v12-Ersatzalarm-Vormerkung (Z. 2070-2078) ist damit unerreichbar.
- **Wann es passiert:** Jeder Task-Freeze ≥ 15 s. Dass der Software-Watchdog historisch überhaupt je feuerte (12v11), lag nur daran, dass die TWDT-Anmeldung bis 12v15 mit „task not found" ins Leere lief – seit dem 12v16-Fix gewinnt immer der TWDT. Der 12v12-Vorfall (SysConf Z. 89-109, „Reboot ohne Ersatzalarm trotz 12v11/12v12-Fixes", mit TWDT-Backtrace) ist genau dieser Ablauf, auf der Hardware beobachtet.
- **Warum es zählt:** Die einzige Absicherung gegen „Freeze während Alarmversuch" ist funktionslos. Reboot ohne Ton, Alarm fällt komplett aus.
- **Fix:** Zwei Änderungen, unabhängig voneinander wirksam:
  1. **Primär (B2-Fix, siehe unten):** RTC-Merker beim Betreten des riskanten Abschnitts schreiben – dann ist es egal, welcher Watchdog feuert.
  2. **Sekundär:** `WDG_TIMEOUT_MS` auf 6000 und `WDG_CHECK_MS` auf 1000 senken. Detektion dann bei 6–7 s, Restart bei ~9 s, sicher vor den 15 s des TWDT. Die Alive-Intervalle tragen das (`inputTask` ≤50 ms, `displayTask` ~300 ms, `alarmTask` ~500 ms, im ungünstigsten `verifyPlayStarted()`-Durchlauf ~2,5 s).
- **Sicherheit des Befunds:** Bestätigt, beide Prüfer, durch die eigene Änderungshistorie empirisch belegt.
- **Notiz (Review 2026-08-14):** Vor der sekundären Maßnahme (`WDG_TIMEOUT_MS`=6000/`WDG_CHECK_MS`=1000) den realen Worst-Case nachrechnen statt den Schätzwert übernehmen: `verifyPlayStarted()` kann allein bis zu `VERIFY_PLAY_RETRIES × VERIFY_PLAY_DELAY_MS` plus Mutex-Wartezeiten summieren, dazu kommt `readStateDrained()`s Gnadenfrist (`SERIAL2_FEEDBACK_GRACE_MS`). Die im Befund genannten ~2,5 s sind plausibel, aber die Marge zum neuen 6-7-s-Detektionsfenster ist knapp – erst nach Schritt 3 (B2) testen, wie im Befund selbst vorgesehen (Reihenfolge, Schritt 5).

---

### [Hoch] B2 – `alarmTriggerInFlight` wird vor dem Einschalten von Motor und Licht gelöscht

- **Ort:** `Software/Firmware_aktuell/Wecker_13v00.ino:1386` (`triggerAlarm`)
- **Was passiert:** Nach bestätigtem `playFolder()` wird `alarmTriggerInFlight = false` gesetzt (Z. 1386), **danach** erst `motorStart()` (Z. 1389, ggf. 150 ms Vollgas-Kickstart), E3 HIGH (Z. 1390) und `alarmState = ALARM_RUNNING` (Z. 1392). Für einen Reset ab Z. 1386 existiert kein Recovery-Pfad: `rtcRetryMagic` ist 0, der Freeze-Fallback prüft `alarmTriggerInFlight`.
- **Wann es passiert:** Jeder Reset zwischen Z. 1386 und dem regulären Alarmende. Konkret erreichbar über: `watchdogTask` erkennt einen input-/displayTask-Freeze und ruft `ESP.restart()` (Z. 2091) – ohne jeden Merker; TWDT-Panic während der `ALARM_RUNNING`-Pollschleife (dieselben `player.available()`-Aufrufe, die laut 12v13 schon einmal 15 s blockierten); Brownout. Nach dem Neustart löst `setup()` keinen Ersatzalarm aus, und `player.begin(…, doReset=true)` plus Startsound (Z. 2509) beenden die laufende Datei ohnehin.
- **Warum es zählt:** Die Firmware zerstört im eigenen Recovery-Pfad einen laufenden Alarm, ohne ihn vorzumerken – genau das, was 12v12 verhindern sollte.
- **Fix:** Merker früh schreiben, spät löschen:

```cpp
// in triggerAlarm(), vor drainSerial2Pre():
rtcRetryAlarm = alarmNum; rtcRetryFileNo = fileNo; rtcRetryMin = min;
rtcRetryCount = failCount; rtcRetryMagic = RTC_RETRY_MAGIC;
```
  Löschen erst im `ALARM_RUNNING`-Zweig nach dem ersten Poll mit `playerStatus > 0` (Z. 1434) sowie im finalen Abbruch (Z. 1374). Wichtig: die Nachhol-Logik aus A1 begrenzt dann automatisch, dass ein spät im Alarm liegender Reboot nicht Stunden später erneut auslöst – **dieser Fix sollte nicht ohne A1 gemacht werden.**
- **Sicherheit des Befunds:** Bestätigt (ein Prüfdurchlauf, alle Zeilen verifiziert). Die im Ursprungsbefund genannte Ursache „Brownout durch Motor-Kickstart" halte ich für unbelegt: ~250 mA Zusatzlast an einem Anker-323-Netzteil, Kickstart zudem nur bei `motor_duty < 89`. Der Befund trägt auch ohne diese Annahme, weil `watchdogTask` und TWDT selbst die Reset-Quelle sind.
- **Notiz (Review 2026-08-14):** Wird der RTC-Merker bei jedem Alarmversuch vorab geschrieben (auch bei später erfolgreichem Start), muss der Löschzeitpunkt sauber vor dem nächsten Freeze-Fenster liegen. Zwischen `alarmState = ALARM_RUNNING` (Z. 1392) und dem ersten Poll in `runAlarmMachine` liegt `ALARM_POLL_MS` (mehrere Sekunden) – ein Reset in diesem Fenster löst den Alarm nach Neustart erneut aus, obwohl er bereits lief. Unkritisch, aber nur, weil A1s Tages-Guard den doppelten Trigger abfängt: **B2 ist ohne A1 nicht nur „nicht ideal", sondern an dieser konkreten Stelle nachweisbar falsch** (wiederholter Alarm trotz bereits laufendem Motor/Licht).

---

### Ursachengruppe C – Der DFPlayer-Status ist die einzige Wahrheit, und er wird unvollständig gelesen

`readStateDrained()` filtert auf `DFPlayerFeedBack` und verwirft **jeden** anderen Frame kommentarlos (Z. 363); `drainSerial2Pre()` prüft den Typ gar nicht. Ein Error-Frame des Moduls kann die Firmware daher nie erreichen. Gleichzeitig wird `st` an drei Stellen unterschiedlich interpretiert: in `ALARM_RUNNING` bedeutet -1 „Alarm läuft weiter" (konservativ, richtig), im S1-Handler wird -1 aktiv zu 0 umgedeutet (unsicher), und in `verifyPlayStarted()`/`triggerAlarm()` gilt 0 wie -1 als Absturz (falsch).

---

### [Hoch] C1 – S1 entscheidet nur nach Playerstatus: laufender Alarm wird nicht gestoppt, stattdessen Kuckuck

- **Ort:** `Software/Firmware_aktuell/Wecker_13v00.ino:1712` (`inputTask`, `EVT_S1`)
- **Was passiert:** Bekommt der Handler innerhalb von 200 ms kein `st > 0`, setzt er `st = 0` („als idle behandeln → kein stop(), Kuckuck auslösen") und nimmt den `else`-Zweig: E1 HIGH für 7,5 s. Kein `player.stop()`, kein `motorStop()`, kein E3 LOW, `alarmState` bleibt `ALARM_RUNNING`. Der zuverlässig lesbare `alarmState` (Z. 105, `volatile`, cross-core) wird nie herangezogen.
- **Wann es passiert:** Der DFPlayer antwortet während eines laufenden Alarms nicht (`st == -1`) – laut Firmware-Kommentar Z. 338-353 ein am 10.08.2026 real beobachtetes Verhalten. Nach ~1,2 s Wartezeit bekommt der Nutzer statt Ruhe 7,5 s Kuckuck, der Alarm bläst weiter, und jeder Druck nach `BTN_LOCKOUT_MS` wiederholt das. Zweiter, alltäglicherer Fall: die MP3 ist gerade zu Ende, `alarmTask` räumt aber erst beim nächsten 5-s-Poll auf – wer in diesem Fenster S1 drückt, um Motor und Licht abzuschalten, löst den Kuckuck aus.
- **Warum es zählt:** Die Stopp-Taste eines Weckers wirkt nicht. In Kombination mit A3 ist S1 der einzige Notausstieg, der ebenfalls versagt.
- **Fix:** Entscheidungsgrundlage umkehren:

```cpp
if (alarmState == ALARM_RUNNING || st > 0) {
  // stop() darf scheitern – Motor, Licht und Zustand werden trotzdem zurückgesetzt
  if (xSemaphoreTake(playerMutex, pdMS_TO_TICKS(200)) == pdTRUE) { … }
  motorStop(); digitalWrite(E3, LOW); alarmState = ALARM_IDLE; …
} else { /* Kuckuck */ }
```
  Der Kuckuck-Zweig nur bei `ALARM_IDLE` **und** sicher gelesenem `st == 0`; `st == -1` nicht mehr in 0 umdeuten.
- **Sicherheit des Befunds:** Bestätigt, beide Prüfer. Die im Ursprungsbefund behauptete Mutex-Aushungerung ist so nicht konstruierbar (`alarmTask` gibt den Mutex zwischen seinen beiden Abfragen frei) – der Schaden entsteht direkt über `st == -1`.
- **Notiz (Review 2026-08-14):** Der Fix-Vorschnitt ("Entscheidungsgrundlage umkehren") deckt nicht alle Fälle: bleibt `alarmState == ALARM_IDLE` und der Player antwortet nicht (`st == -1` nach 200-ms-Timeout), fällt weder die Stop- noch die sicher-`st==0`-Kuckuck-Bedingung – aktuell fängt genau das der `st=0`-Fallback (Z. 1712) auf, wenn auch mit falscher Interpretation. Der Umbau braucht also einen dritten, expliziten Zweig „Status unbekannt bei `ALARM_IDLE`" (z.B. nichts auslösen, nur loggen) statt einer reinen Bedingungsumkehr, sonst verschwindet die Kuckuck-Auslösung bei totem DFPlayer ersatzlos.

---

### [Hoch] C2 – `drainSerial2Pre()` bricht beim ersten ACK-Frame ab, ein Altframe kann „playing" vortäuschen

- **Ort:** `Software/Firmware_aktuell/Wecker_13v00.ino:389` (`drainSerial2Pre`)
- **Was passiert:** Die Schleifenbedingung prüft `Serial2.available()` (Rohbytes), der Abbruch hängt aber am Rückgabewert von `player.available()` (Parserzustand). Der Kommentar begründet den `break` mit „unvollständiger Frame" – derselbe `false`-Wert entsteht aber auch, wenn ein **vollständiger** 0x41-ACK-Frame konsumiert wurde: `parseStack()` behandelt 0x41 intern, ohne `_isAvailable` zu setzen. Das steht in der Firmware selbst (Z. 342-344) und ist in der Historie gemessen (SysConf Z. 143-154: „konstant 20 Byte / 2 Frames Rückstand"). Bei Pufferinhalt `[ACK][Feedback]` wird nur der ACK konsumiert, `drainedPre` bleibt sogar 0 – das Byte-Limit ist nie der begrenzende Faktor.
- **Wann es passiert:** Nach einer Sound-Vorschau plus spätem 0x42-Feedback steht `[ACK]["playing"]` im Puffer. Beim nächsten Alarm konsumiert der Vorab-Drain nur den ACK. Bleibt `playFolder()` wirkungslos (SD gezogen, Datei fehlt, Modul im Fehlerzustand), parst `readStateDrained()` den stehengebliebenen „playing"-Frame → `st > 0` → `verifyPlayStarted()` liefert `true`.
- **Warum es zählt:** Motor an, Licht an, `alarmState = ALARM_RUNNING`, `lastA*Min` gesetzt – **aber kein Ton**, kein Fehlerlog, kein Retry, kein Ersatzalarm. Die komplette dreistufige Absicherung (verify → RTC-Retry → `ALARM_MAX_RESTARTS`) ist genau in dem Fall ausgehebelt, für den sie gebaut wurde.
- **Fix:** Fortschritt am Rohpuffer festmachen statt am Rückgabewert:

```cpp
static void drainSerial2Pre(const char* label) {
  checkSerial2Leftover(label);
  uint16_t drainedPre = 0;
  while (Serial2.available() >= DFPLAYER_RECEIVED_LENGTH && drainedPre < SERIAL2_DRAIN_MAX_BYTES) {
    int before = Serial2.available();
    player.available();
    player.read();
    if (Serial2.available() >= before) { break; }                                        // kein Fortschritt: unvollstaendiger Frame, stehen lassen
    drainedPre += DFPLAYER_RECEIVED_LENGTH;
  }
}
```
  Zusätzlich in `readStateDrained()` **vor** `player.readState()` drainen, damit nie ein Altframe als Antwort auf die gerade gesendete Abfrage gilt.
- **Sicherheit des Befunds:** Bestätigt, beide Prüfer, aber **library_assumption**: `parseStack()` setzt bei 0x41 kein `_isAvailable`. Die Annahme ist durch zwei Stellen im Repo gestützt (Firmware-Kommentar Z. 342-344, SysConf-Messung Z. 143-154), lokal aber nicht am Bibliotheksquelltext verifizierbar. Der Vollschaden setzt zusätzlich einen alten Feedback-Frame mit Wert > 0 hinter dem ACK voraus. **Diese Änderung berührt genau den Bereich, der in 12v13/12v14 eine Regression erzeugt hat – nach Umbau mindestens einen kompletten Alarm-, Vorschau- und S1-Zyklus mit offenem Web-Log durchfahren.**
- **Notiz (Review 2026-08-14):** Der Fortschritts-basierte Ansatz ist risikoärmer als er klingt: Der äußere Schleifenkopf verlangt bereits `Serial2.available() >= DFPLAYER_RECEIVED_LENGTH`, ein unvollständiger Frame kann die Schleife also gar nicht erst betreten – eine Endlosschleife über die Fortschrittsmessung ist damit ausgeschlossen, zusätzlich bleibt `SERIAL2_DRAIN_MAX_BYTES` als harte Grenze bestehen. Die "zuletzt, isoliert" Einordnung bleibt trotzdem richtig – nicht wegen der Fix-Qualität, sondern wegen der unverifizierbaren Bibliotheksannahme und der Regressionshistorie an genau dieser Stelle.

---

### [Hoch] C3 – `st == 0` (Modul antwortet, gestoppt) wird wie „abgestürzt" behandelt: 2 Reboots, danach stumm ohne echte Ursache im Log

- **Ort:** `Software/Firmware_aktuell/Wecker_13v00.ino:1326` (`verifyPlayStarted`), `:360` (`readStateDrained`)
- **Was passiert:** `verifyPlayStarted()` wertet nur `st > 0` als Erfolg; `st == 0` (Modul lebt, hat aber nichts gestartet – typisch für „Datei nicht gefunden") und `st == -1` (keine Antwort) führen zur identischen Diagnose „DFPlayer vermutlich abgestürzt" (Z. 1329) und zu `ESP.restart()` (Z. 1384). Parallel dazu verwirft `readStateDrained()` jeden Nicht-Feedback-Frame (Z. 363) – ein `DFPlayerError`-Frame mit dem echten Fehlercode wird kommentarlos weggeworfen. Repo-weit kommen `DFPlayerError`/`CardRemoved`/`PlayFinished` nirgends vor.
- **Wann es passiert:** `sound1_assigned` zeigt auf eine Datei, die in Ordner 01 nicht existiert (siehe C4/C5) oder nicht lesbar ist. Ablauf: 3× „kein Start-Status" → `failCount` 0→1 → Reboot → `setup()`-Retry (Z. 2532, geht am Clamp Z. 2515 vorbei, weil `rtcRetryFileNo` verwendet wird) → derselbe Fehlschlag → 1→2 → Reboot → 2→3 ≥ `ALARM_MAX_RESTARTS` → `return` in Z. 1376. **Motor (Z. 1389) und Licht (Z. 1390) stehen hinter diesem `return` und werden nie erreicht.**
- **Warum es zählt:** Zwei vollständige Neustarts à 15–80 s im Alarmfenster, danach absolut nichts – kein Ton, kein Motor, kein Licht. Ein Neustart behebt einen Datei-/Kartenfehler prinzipiell nicht; er ist die falsche Reaktion auf ein Modul, das nachweislich antwortet.
- **Fix:** `st == 0` und `st == -1` trennen. Nur `-1` (keine Antwort) rechtfertigt den Neustart; bei wiederholtem `st == 0` einen `[FEHLER]`-Eintrag schreiben, **den Alarm trotzdem als laufend behandeln** (Motor + Licht an, damit der Nutzer wenigstens geweckt wird) und optional auf Datei 1 zurückfallen. Zusätzlich in `readStateDrained()` den Frame-Typ auswerten, bevor er verworfen wird, und `DFPlayerError` mit Code ins Web-Log schreiben.
- **Sicherheit des Befunds:** Bestätigt, aber vom Prüfer von „kritisch" auf „mittel" heruntergestuft. Der Teil „Error-Frame wird verworfen" trägt eine Bibliotheksannahme (0x40 → `DFPlayerError`). Der hier tragende Kern – `st == 0` wird wie `st == -1` behandelt, `motorStart()` steht hinter dem `return` – ist annahmefrei aus dem Code belegt.
- **Notiz (Review 2026-08-14):** Wird bei wiederholtem `st == 0` "der Alarm trotzdem als laufend behandelt" (Motor/Licht an, kein Ton), muss A3s Maximallaufzeit-Ausstieg auch für diesen stummen Fall greifen – sonst läuft ein Wecker ohne Ton bis zum A3-Timeout unbegrenzt weiter, statt zeitnah in einen erkennbaren Fehlerzustand zu wechseln. C3 sollte deshalb zusammen mit A3 verifiziert werden, nicht isoliert, auch wenn beide getrennt committet werden.

---

### [Mittel] C4 – `mp3Count` wird geraten (Fallback 99, `c - 1`)

- **Ort:** `Software/Firmware_aktuell/Wecker_13v00.ino:2496` und `:2501` (`setup`)
- **Was passiert:** Bei `readFileCounts`-Timeout wird `mp3Count = 99` gesetzt, obwohl keine Dateizahl bekannt ist. Im Erfolgsfall unterstellt `mp3Count = c - 1`, dass **genau eine** Datei außerhalb von Ordner 01 liegt (der Startsound in Ordner 02). `readFileCounts()` (0x48) liefert die Gesamtzahl über alle Ordner; die ordnerbezogene Variante `readFileCountsInFolder()` (0x4E) wird nirgends verwendet.
- **Wann es passiert:** SD-Karte mit 12 Alarmdateien in Ordner 01 und 3 Dateien in Ordner 02 → `mp3Count = 14`, Nummer 13 und 14 sind wählbar und existieren nicht. Ebenso jede vom Betriebssystem angelegte Zusatzdatei beim Kopieren auf FAT32, oder der 99-Fallback nach langsamer SD-Indizierung.
- **Warum es zählt:** Direkter Zubringer für C3 – eine wählbare, nicht existierende Datei führt zur Reboot-Kaskade und zum endgültig stummen Alarm.
- **Fix:** `readFileCountsInFolder(1)` verwenden. Bei Timeout **nicht raten**: `mp3Count` bei 0 lassen, bestehende Zuordnungen unangetastet lassen (siehe C5) und die UI-Auswahl erst freigeben, wenn eine echte Dateizahl vorliegt.
- **Sicherheit des Befunds:** Bestätigt, beide Prüfer. **library_assumption**: Semantik 0x48 vs. 0x4E (gut dokumentiert, aber lokal nicht verifizierbar).
- **Notiz (Review 2026-08-14):** Keine substanziellen Einwände.

---

### [Hoch] C5 – `mp3Count == 0` nach fehlgeschlagenem `player.begin()` überschreibt die Sound-Zuordnung dauerhaft

- **Ort:** `Software/Firmware_aktuell/Wecker_13v00.ino:2515-2516` (`setup`)
- **Was passiert:** Im `else`-Zweig (Z. 2512) bleibt `mp3Count` bei 0. Die Clamp-Zeilen laufen trotzdem unbedingt: `if (sound1_assigned > mp3Count) sound1_assigned = 1;`. Da `readNVR()` (Z. 772/773) `sound*_assigned >= 1` garantiert, ist die Bedingung immer wahr – beide Zuordnungen werden auf 1 gesetzt.
- **Wann es passiert:** Der DFPlayer antwortet beim Wiederanlauf nicht rechtzeitig auf `begin()` (SD-Indizierung, Modul-Brownout). Verstellt der Nutzer danach **irgendetwas** (Lautstärke, Alarmzeit), löst `markSafeChange()` → `nvrTask` → `writeNVR()` (Z. 735/736) aus und persistiert `sound1_assigned = 1`. Nach dem nächsten Neustart ist der Originalwert auch aus NVS verschwunden. Einen `begin()`-Retry gibt es nicht (in 10v01 entfernt).
- **Warum es zählt:** Unwiederbringlicher, stiller Verlust einer Nutzereinstellung. Verschärfend: bei `mp3Count == 0` klemmt die Sound-Auswahl in der UI (Z. 1060/1098) auf 1 fest – der Nutzer kann seine Melodie in diesem Boot nicht einmal wieder einstellen, und der Versuch löst selbst den Commit aus.
- **Fix:** Clamp nur bei bekannter Dateizahl, plus sichtbarer Fehlerzustand:

```cpp
if (mp3Count > 0) {
  if (sound1_assigned > mp3Count) sound1_assigned = 1;
  if (sound2_assigned > mp3Count) sound2_assigned = 1;
} else {
  webLog("[FEHLER] DFPlayer-Dateizahl unbekannt – Sound-Zuordnung unveraendert");
}
```
- **Sicherheit des Befunds:** Bestätigt, beide Prüfer, deterministisch nachvollziehbar. Der Wecker wird dadurch nicht stumm (Datei 1 existiert immer), er weckt mit der falschen Melodie.
- **Notiz (Review 2026-08-14):** Keine substanziellen Einwände.

---

### [Mittel] C6 – `player.stop()` aus `inputTask` während `verifyPlayStarted()` erzwingt einen Reboot

- **Ort:** `Software/Firmware_aktuell/Wecker_13v00.ino:1725` (`inputTask`) gegen `:1367` (`triggerAlarm`)
- **Was passiert:** `triggerAlarm()` gibt `playerMutex` nach `playFolder()` frei (Z. 1366) und ruft `verifyPlayStarted()` ohne Mutex auf. `inputTask` (Core 1) kann den Mutex in diesem Fenster jederzeit bekommen und stoppt den Player, ohne `alarmState` oder `alarmTriggerInFlight` zu prüfen. Die Verifikation sieht danach 3× `st == 0` → `rtcRetryMagic` gesetzt → `ESP.restart()`. Nach dem Neustart löst `setup()` (Z. 2532) exakt denselben Alarm erneut aus.
- **Wann es passiert:** Der Nutzer drückt S1 zwischen dem Moment, in dem der DFPlayer „playing" meldet (typ. 100–400 ms nach `playFolder`), und dem ersten Poll bei t = 500 ms. Dasselbe passiert unbeabsichtigt über `menu(5)` (Z. 674) oder das Abwählen einer Sound-Vorschau (Z. 572/593).
- **Warum es zählt:** Der bewusst gestoppte Alarm klingelt nach einem unnötigen Reboot erneut. Nicht eskalierend: der Retry in `setup()` läuft vor der Task-Erstellung (Z. 2592), ein zweiter S1-Druck kann dort nichts auslösen – es bleibt bei einem Reboot-Zyklus.
- **Fix:** Abbruch-Flag (`alarmCancelRequested`), das `inputTask` vor `player.stop()` setzt, wenn `alarmTriggerInFlight` oder `ALARM_RUNNING` gilt. `verifyPlayStarted()` wertet es als reguläres Ende (kein `rtcRetryMagic`, kein Restart), `triggerAlarm()` prüft es vor Z. 1386.
- **Sicherheit des Befunds:** Bestätigt; Zeitfenster laut zweitem Prüfer eher 100–400 ms als 1500 ms.
- **Notiz (Review 2026-08-14):** Keine substanziellen Einwände.

---

### [Mittel] C7 – Fehlgeschlagener 50-ms-Take wird ignoriert: Anzeige/NVS und DFPlayer laufen auseinander

- **Ort:** `Software/Firmware_aktuell/Wecker_13v00.ino:959` und `:974` (`onClock`), gleiches Muster in `checkboxSound` (Z. 562/570/583/591) und `menu(5)` (Z. 672)
- **Was passiert:** `vol` wird bereits **vor** dem Take verändert (Z. 957/972); nur `drainSerial2Pre()` + `player.volume()` stehen im `if`. Anzeige-Update und `markSafeChange()` laufen unbedingt danach, ohne `else`, ohne Log, ohne Retry.
- **Wann es passiert:** Der Alarm läuft, der Nutzer drückt T4; `alarmTask` hält den Mutex gerade im 5-s-Poll bzw. in einer der drei `verifyPlayStarted()`-Abfragen. Die Anzeige zeigt 03, der Player spielt weiter auf 09 – und 03 landet in NVS. Bei der Vorschau wird die Checkbox geleert, `player.stop()` fällt aus, der Sound läuft weiter.
- **Warum es zählt:** Kein Alarmausfall, aber die Lautstärkeregelung wirkt genau dann nicht, wenn man sie braucht.
- **Fix:** Zustandsänderung, Anzeige und `markSafeChange()` erst nach erfolgreichem Take ausführen; mindestens den Fehlschlag per `webLogf()` protokollieren.
- **Sicherheit des Befunds:** Bestätigt, beide Prüfer. Das Kollisionsfenster ist kleiner als im Ursprungsbefund behauptet (Mutex-Hold eher 100–150 ms als 2 s).
- **Notiz (Review 2026-08-14):** Keine substanziellen Einwände.

---

### [Mittel, umstritten] C8 – `playerMutex` wird über blockierende Bibliotheksaufrufe gehalten

- **Ort:** `Software/Firmware_aktuell/Wecker_13v00.ino:366` (`readStateDrained`), Aufrufer Z. 1323/1425/1431/1705/1718; UI-Pfade Z. 562/959/672 unter zusätzlich gehaltenem `displayMutex` (Z. 1783)
- **Was passiert:** In `readStateDrained()` wird `graceStart` bei **jedem** empfangenen Frame neu gesetzt (Z. 366); begrenzt ist nur die Frameanzahl (20). Theoretischer Worst Case ~2 s Mutex-Haltezeit. Zusätzlich nehmen die UI-Pfade `playerMutex` unter gehaltenem `displayMutex` und rufen darunter blockierende `player.*`-Aufrufe.
- **Warum ich es abschwäche:** Ein **Deadlock ist ausgeschlossen** – es gibt keine Lock-Inversion, `displayMutex` wird nirgends unter `playerMutex` genommen, und `triggerAlarm()` nimmt `displayMutex` überhaupt nicht. Die 2-s-Rechnung setzt einen Frame-Strom mit knapp unter 100 ms Abstand über 2 s voraus; kommt gar nichts, endet die Schleife nach einer Gnadenfrist (100 ms), kommt es dichter, ist das Byte-Limit in Millisekunden erreicht. Real bleibt: die Haltezeit ist nach oben nicht sauber begrenzt, und das speist A2 und C7.
- **Fix (billig, risikoarm):** Absolutes Zeitbudget statt nachladbarer Gnadenfrist – Startzeitpunkt einmal vor der Schleife merken und zusätzlich gegen ein Gesamtlimit (z.B. 250 ms) prüfen. Die Umgruppierung der UI-Pfade (Kommando-Queue statt Direktaufruf unter zwei Locks) ist sauberer, aber angesichts der Regressionshistorie nicht vordringlich.
- **Sicherheit des Befunds:** Umstritten – ein Prüfer real/mittel, einer widerlegt („kein Deadlock, Zeitrechnung überzogen"). Ich folge weitgehend der Widerlegung; das Zeitbudget ist trotzdem sinnvoll.
- **Notiz (Review 2026-08-14):** Keine substanziellen Einwände.

---

### Ursachengruppe D – Rückgabewerte werden nirgends geprüft

### [Mittel] D1 – NVS-Rückgabewerte werden nirgends ausgewertet: Alarmzeit geht still verloren

- **Ort:** `Software/Firmware_aktuell/Wecker_13v00.ino:2011` (`nvrTask`), `:728-744` (`writeNVR`), `:2333` (`setup`), `:783` (`bumpResetCount`)
- **Was passiert:** Weder `data.begin()` noch die 15 `putBool`/`putInt` werden ausgewertet. Schlägt das Öffnen des Namespace fehl (beschädigter NVS, `ESP_ERR_NO_MEM`), laufen alle Writes ins Leere. `safeChange` wurde zu diesem Zeitpunkt bereits gelöscht (Z. 1656/1748/1771/1828), ein Nachholen findet nie statt.
- **Wann es passiert:** Nutzer stellt A1 von 06:00 auf 07:30. `nvrTask` erwacht, `begin()` scheitert. Display zeigt weiterhin 07:30 – bis zum nächsten Stromausfall; danach liest `readNVR()` 06:00 zurück. Gleiche Blindheit in `setup()` Z. 2333: schlägt `begin()` dort fehl, liefert `getBool("state", false)` den Default, `readNVR()` wird nie aufgerufen und das Gerät arbeitet ab jedem Boot still mit den Compile-Defaults.
- **Warum es zählt:** Der Wecker klingelt zur falschen Zeit, ohne dass irgendetwas darauf hindeutet.
- **Fix:** Rückgabewert von `data.begin()` an allen drei Stellen prüfen; in `nvrTask` bei `false` `safeChange` wieder setzen (Retry im nächsten Zyklus) und `[FEHLER]` ins Web-Log. `readNVR()` unabhängig vom `state`-Flag ausführen – die Defaults kommen ohnehin aus den `getX()`-Fallbacks.
- **Sicherheit des Befunds:** Bestätigt, beide Prüfer. **library_assumption**: `Preferences::begin()` liefert `bool`, `putX` wird bei nicht gestartetem Handle zum No-Op (Standardverhalten arduino-esp32).
- **Notiz (Review 2026-08-14):** Keine substanziellen Einwände.

---

### [Niedrig] D2 – Web-Log-Seite: `reserve(8192)` deckt den Worst Case nicht, `/log` reserviert gar nicht

- **Ort:** `Software/Firmware_aktuell/Wecker_13v00.ino:2123` und `:2259` (`webLogTask`)
- **Was passiert:** Fixes Markup ~2,5 kB + 40 Ringpufferzeilen à bis 127 Zeichen + 26 Byte Span-Overhead + Snapshots ergeben rund 8,7–9,8 kB – über der reservierten Kapazität. Ab dann realloziert jedes `html += entry` den kompletten Block. Der `/log`-Handler reserviert überhaupt nicht. Kein Rückgabewert (`reserve`, `+=`, `send`) wird geprüft.
- **Wann es passiert:** Während einer DFPlayer-Störung füllt sich der Puffer mit langen Zeilen (die Meldung aus Z. 332 ergibt real 119 Zeichen).
- **Warum es zählt:** Kein Crash (ein fehlgeschlagenes Realloc verwirft die Zuweisung folgenlos), aber die Diagnoseseite wird abgeschnitten ausgeliefert – genau dann, wenn man sie braucht.
- **Fix:** Seite streamen: `setContentLength(CONTENT_LENGTH_UNKNOWN)`, `send(200, …, "")` und die Blöcke einzeln per `sendContent()`. Minimal: `reserve()` auf 12288 anheben und `out` im `/log`-Handler ebenfalls reservieren.
- **Sicherheit des Befunds:** Bestätigt; Auswirkung nur auf das Wartungswerkzeug, daher niedrig.
- **Notiz (Review 2026-08-14):** Keine substanziellen Einwände.

---

### Ursachengruppe E – Bedien- und Hardwarepfade

### [Mittel] E1 – Klemmendes Touch-Pad: keine Rekalibrierung, Lautstärke fällt auf 0, Alarm bleibt stumm

- **Ort:** `Software/Firmware_aktuell/Wecker_13v00.ino:1531` und `:1570-1594` (`touchTask`)
- **Was passiert:** `TS_PRESSED`/`TS_REPEAT` haben keine Maximaldauer; einziger Ausstieg ist `!padPressed[activeIdx]`. Die Baseline-Rekalibrierung ist hart an `TS_IDLE` gekoppelt und findet dann nie wieder statt. `touchTask` hat als einziger Task **kein** `wdg_*`-Alive-Signal, wird also von nichts überwacht.
- **Wann es passiert:** Feuchtigkeit/Kondensation am 30 cm langen Twisted Pair oder ein Kabeldefekt hält ein Pad dauerhaft unter der Schwelle. Ab da alle 250 ms ein Event. Steht die UI auf `UI_CLOCK` und klemmt T4, zählt `onClock` die Lautstärke in ~3 s auf 0 herunter und sendet `player.volume(0)`. **`triggerAlarm()` setzt die Lautstärke nicht neu** – `player.volume()` existiert nur an drei Stellen (Z. 961, 976, 2505). Der nächste Alarm läuft real stumm. Nebeneffekt: `lastTouchMs` wird ständig erneuert, Auto-Return und Display-Timeout laufen nie ab.
- **Warum es zählt:** Ein Hardwarefehler wird durch die Firmware zum stummen Wecker verstärkt. Immerhin sichtbar (Display bleibt an, Lautstärke steht auf 00).
- **Fix:** Maximale Zusammenhangsdauer für `TS_PRESSED`/`TS_REPEAT` (z.B. 30 s → Zwangsrücksetzung auf `TS_IDLE` inkl. Baseline-Neuerfassung und `[WARNUNG]` ins Web-Log). Unabhängig davon in `triggerAlarm()` vor `playFolder()` ein `player.volume(vol)` senden, mit einer Untergrenze für den Alarmfall.
- **Sicherheit des Befunds:** Bestätigt. Die im Ursprungsbefund zusätzlich behauptete dauerhafte NVR-Commit-Blockade tritt so nicht ein: `markSafeChange()` wird am Anschlag (`vol == 0`) nicht mehr aufgerufen, der Commit läuft 2 s später.
- **Notiz (Review 2026-08-14):** Keine substanziellen Einwände.

---

### [Mittel] E2 – S3 liegt direkt auf dem Boot-Strapping-Pin GPIO0

- **Ort:** `Software/Firmware_aktuell/SysConf_13v00.h:452`, Nutzung `Wecker_13v00.ino:2444` / `:2468`
- **Was passiert:** `const uint8_t S3 = 0;` mit `INPUT_PULLUP` und `FALLING`-ISR, ohne Serienwiderstand, RC oder Diode. Verschärfend: T2 hängt auf GPIO2 (zweiter Strapping-Pin) mit 4,7 nF nach GND, ist beim Reset also sicher LOW – die Bedingung für UART-Download-Boot (GPIO0 = 0 **und** GPIO2 = 0) ist bei gedrücktem S3 vollständig erfüllt.
- **Wann es passiert:** Nur bei Resets, die den Strapping-Latch neu laden: Power-On (Netzteil einstecken nach Stromausfall), EN-Taster, Brownout. **Nicht** bei `ESP.restart()` – das ist auf dem ESP32 ein reiner CPU-Reset (`SW_CPU_RESET`), sonst würde der gesamte `rtcRetryMagic`-Mechanismus nicht funktionieren. Damit entfällt die häufigste im Ursprungsbefund behauptete Auslöserkette.
- **Warum es zählt:** Bleibt das Gerät im ROM-Downloadmodus, gibt es kein `setup()`, keine Tasks, kein Display und **keinen weiteren Startversuch** – schlimmer als ein Reboot-Loop. Realistisch wird das bei einem mechanisch verklemmten oder verschmutzten Taster im Holzgehäuse: dann ist jeder Netzausfall ein Dauerausfall.
- **Fix:** S3 auf einen GPIO ohne Strapping-Funktion legen (z.B. GPIO19/23 mit internem Pull-up) und Pin-Zuordnung in SysConf/CLAUDE.md/Schaltplan nachziehen. Falls die Verdrahtung bleiben muss: Diode oder RC, so dass ein Tastendruck GPIO0 in den ersten Millisekunden nach Reset nicht unter den LOW-Pegel zieht.
- **Sicherheit des Befunds:** Bestätigt, Schweregrad von „hoch" auf „mittel" korrigiert (Software-Reset-Pfad widerlegt). Das DevKitC hat ohnehin einen BOOT-Taster auf GPIO0 – S3 erhöht nur die Exposition.
- **Notiz (Review 2026-08-14):** Keine substanziellen Einwände.

---

### [Hoch] E5 – Motor hängt laut Schaltplan an 3,3 V, Firmware und Hardware-Notiz rechnen mit 5 V

- **Ort:** `Hardware/Schaltplan/Motor-Treiber.md:3`, `Hardware/Stückliste/Stückliste.md` (Abschnitt 3), gegen `SysConf_13v00.h:460-470` und `Hardware/hardware_notesmotor_led_driver.md:30-41`
- **Was passiert:** Der Schaltplan speist Motor+ über einen `AMS1117 3v3` aus der 5-V-Schiene, die Stückliste führt ihn ausdrücklich als „LDO 5 V → 3,3 V" im Motor-Treiber. Firmware-Kommentar und Hardware-Notiz gehen dagegen von 5 V am Motor aus und leiten daraus `MOTOR_PWM_DUTY 153` ab („60 % Duty ≙ ~3 V Mittelwert").
- **Wann es passiert:** Immer. Bei 3,3 V Rail ergeben 153/255 einen Mittelwert von **~1,98 V** statt der beabsichtigten 3 V — der 3-V-Getriebemotor läuft dauerhaft bei rund zwei Dritteln der Nennspannung. Für 3 V wären ~232/255 (91 %) nötig. Ebenso verschiebt sich `MOTOR_PWM_KICK_THRESHOLD 89`: 35 % sind an 3,3 V nur noch 1,15 V, der Kickstart setzt also zu spät ein.
- **Warum es zählt:** Erklärt ein zähes oder gar nicht anlaufendes Mühlrad, ohne dass die Firmware etwas Falsches täte. Gefährlicher ist der Dokumentationswiderspruch selbst: wer den Slider künftig kalibriert oder den Duty-Default anpasst, rechnet je nach gelesener Quelle mit einer anderen Rail. Nebenbei nennt `SysConf_13v00.h:456` die Freilaufdiode `1N4148`, Schaltplan und Stückliste `1N4448`.
- **Fix:** Zuerst mit dem Multimeter klären, welche Rail real anliegt (Motor+ gegen GND bei Duty 100 %). Dann **eine** Quelle korrigieren statt beider: bei 3,3 V `MOTOR_PWM_DUTY` auf ~232 und `MOTOR_PWM_KICK_THRESHOLD` entsprechend anheben, die 5-V-Kommentare in SysConf und `hardware_notesmotor_led_driver.md` auf 3,3 V ziehen. AMS1117-Verlustleistung bleibt unkritisch ((5−3,3) × 0,2 A ≈ 0,34 W).
- **Sicherheit des Befunds:** Bestätigt aus Schaltplan und Stückliste; welche der beiden Quellen den gebauten Aufbau beschreibt, ist ohne Messung am Gerät nicht entscheidbar — der Widerspruch selbst ist es.
- **Notiz (Review 2026-08-14):** Keine substanziellen Einwände.

---

### [Niedrig, umstritten] E3 – Kuckuck-Treiber (E1) ohne Freilaufdiode, Modul an 5 V statt 4,5 V

- **Ort:** `Hardware/Schaltplan/Kuckuck-Treiber.md:4`, Ansteuerung `Wecker_13v00.ino:1468`/`:1477`
- **Was passiert:** Der Kuckuck-Kanal schaltet eine vermutlich induktive Last (Platinenbeschriftung „4V5 115mA") ohne Freilaufpfad, anders als der Motorkanal (1N4448 + 10 Ω/10 nF Snubber). Zusätzlich liegt die volle 5-V-Schiene am Modul.
- **Warum ich es abschwäche:** Der MOSFET klemmt die Abschaltspitze per Lawinendurchbruch; die Energie liegt bei 39 Ω Lastwiderstand selbst mit großzügig angesetzter Induktivität im Bereich von Mikro- bis wenigen Millijoule, also Größenordnungen unter der EAS-Grenze eines SOT-23-Leistungs-MOSFET. Der Vergleich mit E2 trägt nicht: dort sind es 20.000 Abschaltvorgänge pro Sekunde (PWM), hier rund 20 pro Tag. Die Stückliste bildet den Kuckuck-Kanal ohnehin nicht ab (auch MOSFET und Widerstände fehlen dort).
- **Fix:** 1N4448 antiparallel zur Last ergänzen (gute Praxis, EMV neben der DFPlayer-Elektronik). Die 4,5-V-Frage ist bei 0,2 % Einschaltdauer thermisch irrelevant.
- **Sicherheit des Befunds:** Umstritten – ein Prüfer mittel, einer niedrig mit Energierechnung. Ich folge der Rechnung. Offene Annahme in beiden Richtungen: kein Datenblatt des Kuckuck-Moduls vorhanden.
- **Notiz (Review 2026-08-14):** Keine substanziellen Einwände.

---

### [Niedrig, umstritten] E4 – `runWifiConfigServer()` blockiert endlos vor der Task-Erstellung

- **Ort:** `Software/Firmware_aktuell/Wecker_13v00.ino:922` (`runWifiConfigServer`), Aufruf `:2359`
- **Was passiert:** `while (true) { server.handleClient(); delay(5); }` ohne Timeout, aufgerufen vor jeder Task-Erstellung (Z. 2592). Ohne WLAN-Zugangsdaten existieren weder `alarmTask` noch `displayTask` – das Gerät ist AP und kein Wecker.
- **Warum ich den ursprünglichen Fix ablehne:** Weiterbooten würde **nicht** helfen. Ohne Credentials ruft `WiFi.begin("", "")` dauerhaft ins Leere, es gibt nie eine NTP-Synchronisation, und mit den Default-Alarmen (06:00, `a1_on = true`) würde ein weiterlaufendes Gerät auf der 1970-Uhr zu einer beliebigen realen Uhrzeit klingeln – siehe A5. Der aktuelle Zustand ist zudem nicht still: das OLED zeigt dauerhaft „WiFi Einrichtung / WLAN: bTn-Wecker / Browser öffnen: 192.168.4.1".
- **Was real bleibt:** T3 auf der Info-Seite löscht die WLAN-Zugangsdaten ohne Rückfrage, direkt neben T4 (Werksreset). Ein Fehlgriff macht das Gerät bis zur Neukonfiguration zum AP.
- **Fix:** Bestätigungsabfrage für T3 (zweiter Druck innerhalb weniger Sekunden), nicht Timeout auf die Konfigurationsschleife.
- **Sicherheit des Befunds:** Umstritten; ich bewerte den Endlos-Loop als vertretbar, die fehlende Bestätigung als das eigentliche Thema.
- **Notiz (Review 2026-08-14):** Keine substanziellen Einwände.

---

## Nicht bestätigt

**Unbegrenzte Wartepfade in `sendStack()`/`available()` sind nicht die Ursache eines 15-s-TWDT-Hängers.** Es wurde geprüft, ob die innere `while (_serial->available())`-Schleife der Bibliothek den nachgelagerten Zeitcheck bei anhaltendem Rauschen „aushungern" kann. Sie kann es nicht: bei 9600 Baud fließen maximal ~960 Byte/s nach, die Schleife konsumiert ein Byte in Mikrosekunden – der Puffer ist nach wenigen Mikrosekunden leer und der Check `_isSending && millis() - _timeOutTimer >= _timeOutDuration` wird rund 960-mal pro Sekunde erreicht, nicht „nie". Zusätzlich beendet `handleError(WrongStack)` die ACK-Warteschleife, sobald ein 0x7E ohne gültige Folgebytes auftritt, und reines 0x00-Rauschen enthält nie ein 0x7E. Auch die Summe aller begrenzten Wartezeiten eines toten DFPlayers in einem `alarmTask`-Durchlauf liegt bei rund 5,5–6 s gegen 15 s TWDT-Budget.

**Das ist für dich direkt verwertbar:** die 12v14-Rücknahme des Bibliotheks-Patches war richtig, und der 12v13-Backtrace zeigte nur, *wo* der Task im Moment des Timeouts stand, nicht *dass* diese Schleife 15 s blockierte. Die dokumentierte Ursache (roher `Serial2.read()`-Discard, der die Bibliothek desynchronisierte) bleibt die tragfähige Erklärung. Ein erneuter Patch an `DFRobotDFPlayerMini.cpp` ist nicht nötig.

---

## Ungeprüft geblieben

- **Alle acht niedriger eingestuften Befunde wurden aus Kapazitätsgründen nicht gegengeprüft.** Zwei davon halte ich für lohnend genug, um sie hier zu nennen, ohne dass ich sie verifiziert habe:
  - `esp_task_wdt_init()`/`reconfigure()` und die drei `esp_task_wdt_add(NULL)` werten ihren Rückgabewert nicht aus, während Z. 2587 unbedingt „[TWDT] Hardware Watchdog aktiv" ins Log schreibt. Genau der 12v15-Fehler wäre damit symptomfrei.
  - Nach einem NTP-Timeout laufen `webLog("[NTP] Synchronisation OK")` (Z. 2437) und `snapTimeStr(snapNtpTime, …)` (Z. 2438) unbedingt weiter. Das Log behauptet eine erfolgreiche Synchronisation, und weil `snapNtpTime` dann nicht mehr leer ist, greift der 12v04-Nachtrag in `displayTask` (Z. 1867) beim späteren echten Sync nie. Wer nach einem ausgefallenen Alarm ins Log sieht, schließt einen Uhrzeitfehler damit fälschlich aus – **das ist im Zusammenspiel mit A1 und A5 diagnostisch teuer und ein Zweizeiler.**
  - Ebenfalls ungeprüft: `STACK_WATCHDOG = 1344` für einen Fehlerzweig mit `webLogf` (`char buf[128]` + `vsnprintf`) und drei SSD1306-Aufrufen; Race auf `motorRunning`/E2 zwischen `motorStart()`-Kickstart und `/motor`-HTTP-Handler; ungeschützte Snapshot-Strings im HTTP-Handler; `nvs_flash_erase()` beim Werksreset ohne Anhalten des `nvrTask`.
  - Der im Workflow noch als ungeprüft gelistete Punkt „AMS1117-3,3 V im Motorpfad gegen die 5-V-Annahme" wurde nachträglich gegen Schaltplan und Stückliste verifiziert und ist oben als **E5** aufgenommen.
- **Bibliotheksinterna sind grundsätzlich nicht verifizierbar.** `DFRobotDFPlayerMini` und `SSD1306Wire` liegen weder im Repo noch installiert vor. Betroffen sind C2 (`parseStack()` und der 0x41-ACK), C3 (Abbildung 0x40 → `DFPlayerError`), C4 (Semantik 0x48 vs. 0x4E), D1 (`Preferences`-Fehlerverhalten) und die Zeitrechnung in C8. Alle diese Punkte sind entsprechend markiert.
- **Keine Hardware-Verifikation.** Mutex-Haltezeiten, DFPlayer-Antwortlatenzen, Brownout-Verhalten beim Motoranlauf, tatsächliche Stack-High-Water-Marks im Fehlerzweig und die Spannung an Motor+ sind ausschließlich aus dem Code und der Dokumentation abgeleitet.
- **Nicht abgedeckt:** `WEB.h` und der WiFi-Konfigurator wurden nur oberflächlich betrachtet (kein Audit auf Eingabevalidierung der POST-Parameter); die UI-State-Machine (`uiDispatch`, `menu()`, alle `on*`-Handler) wurde nur dort gelesen, wo sie Player- oder NVR-Zustand berührt; die Touch-Kalibrierung wurde nicht auf Fehlauslösungen durch Netzbrummen geprüft; Speicherverhalten über Wochen Laufzeit (Heap-Fragmentierung durch `WebServer`/lwIP) wurde nicht gemessen, nur der `String`-Aufbau im Log-Handler bewertet.

---

## Empfohlene Reihenfolge

1. **A5 + A1 gemeinsam: `timeValid()`-Gate und tagesbezogene Fälligkeitsprüfung.** Höchste Wirkung, kein Kontakt zur DFPlayer-Logik. Das Gate muss zuerst da sein, sonst löst die pegelbasierte Prüfung auf der 1970-Uhr sofort nach Boot aus. Erledigt in einem Zug A1, A4, A5, A6 und macht A2 selbstheilend. Testbar ohne Hardware, indem man die Systemzeit per NTP-Server-Attrappe springen lässt.
2. **A3: Maximallaufzeit für `ALARM_RUNNING`.** Fünf Zeilen, keine Bibliotheksberührung, beseitigt den einzigen Zustand, aus dem das Gerät sich nie wieder erholt. Zusammen mit C1 (S1 wirkt bei `ALARM_RUNNING` unabhängig vom Playerstatus) – auch das ist reine Anwendungslogik.
3. **B2: RTC-Merker vor dem riskanten Abschnitt setzen, nach dem ersten erfolgreichen Poll löschen.** Macht die gesamte Absturz-Wiederherstellung unabhängig davon, welcher Watchdog feuert, und entschärft B1 ohne Timing-Änderung. Nicht vor Schritt 1 durchführen – ohne das Nachholfenster kann ein spät im Alarm liegender Reboot sonst zu einem verspäteten Zweitalarm führen.
4. **C5 + D1: Clamp nur bei `mp3Count > 0`, NVS-Rückgabewerte prüfen und bei Fehlschlag `safeChange` wieder setzen.** Zwei kleine, isolierte Änderungen gegen stillen Konfigurationsverlust. Kein Regressionsrisiko.
5. **B1 sekundär: `WDG_TIMEOUT_MS` = 6000, `WDG_CHECK_MS` = 1000.** Reine SysConf-Änderung, gibt dem Software-Watchdog seine Funktion zurück. Erst nach Schritt 3, damit man am Feldverhalten sieht, ob der neue Schwellwert Fehlalarme erzeugt.
6. **C3: `st == 0` von `st == -1` trennen.** Verhindert zwei sinnlose Neustarts im Alarmfenster und den anschließenden Totalausfall ohne Motor und Licht. Berührt die DFPlayer-Logik, aber nur die Auswertung – kein UART-Verhalten. Getrennt committen.
7. **C4: `readFileCountsInFolder(1)` statt `readFileCounts() - 1`, kein 99-Fallback.** Beseitigt die Ursache für C3. Neuer Bibliotheksaufruf, daher nach C3 und einzeln testen.
8. **C2: `drainSerial2Pre()` auf Fortschrittsprüfung umstellen, `readStateDrained()` vorher drainen.** **Zuletzt und ausdrücklich isoliert.** Dies ist genau der Bereich, der in 12v09–12v14 dreimal hintereinander Regressionen erzeugt hat (Puffer-Desync, Bibliotheks-Patch, ACK-Modus). Vorher unbedingt die Zeilen aus Schritt 1–3 als stabilen Stand festhalten, damit ein Rückbau möglich bleibt. Testprotokoll: Kaltstart, Startsound, Sound-Vorschau beider Alarme, Lautstärkeänderung, echter Alarm, S1-Stopp, Alarm mit gezogener SD-Karte, jeweils mit offenem Web-Log und Blick auf „Serial2 Restbytes".
9. **E5: Rail am Motor messen und danach genau eine Quelle korrigieren.** Kostet fünf Minuten mit dem Multimeter, räumt einen Widerspruch zwischen Schaltplan, Stückliste, Firmware-Kommentar und Hardware-Notiz aus und erklärt möglicherweise ein zähes Mühlrad. Unabhängig von allem anderen, jederzeit machbar.
10. **E1 (Touch-Haltedauer + `player.volume()` in `triggerAlarm()`), E2 (S3 von GPIO0 weg), C6, C7, D2, E4.** Wirkung geringer oder Hardwareeingriff nötig; E2 nur bei der nächsten ohnehin anstehenden Platinenänderung.
11. **Die zwei ungeprüften Zweizeiler aus „Ungeprüft geblieben"** (TWDT-Rückgabewerte, NTP-Erfolgsmeldung nach Timeout) mitnehmen, sobald ohnehin an `setup()` gearbeitet wird – beide kosten nichts und verbessern die Diagnostizierbarkeit aller obigen Fälle.

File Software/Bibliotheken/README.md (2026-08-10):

# Bibliotheken

Hinweis: Bibliotheken über den Arduino Library Manager installieren.
Siehe README.md im Root für Versionsangaben.

## DFRobotDFPlayerMini: kein Patch (Stand 12v14)

**Firmware 12v13 hatte hier fälschlich einen Patch dokumentiert** – nach dem
Hardware-Watchdog-Reset (TWDT) vom 10.08.2026 mitten in `triggerAlarm()` →
`playFolder()` → `sendStack()` wurde `available()`s innere
`while (_serial->available())`-Schleife als Ursache vermutet und dort eine
100-ms-Obergrenze ergänzt.

Der Patch wurde in 12v14 **zurückgenommen**: die Hardware wurde mit 12v08
als voll funktionsfähig verifiziert, dort existierte weder der Patch noch
war die Bibliothek verändert. Der tatsächliche Fehler steckte in der
Firmware, nicht in der Bibliothek – siehe `triggerAlarm()` in
`Wecker_12v14.ino`: ein roher `Serial2.read()`-Discard vor `playFolder()`
(seit 12v11) griff an der Bibliothek vorbei in deren Frame-Puffer und
desynchronisierte dabei `_receivedIndex`/`_isSending`. Das erzeugte das
anhaltende Byte-Durcheinander auf der UART, das dann in `available()` zum
15-Sekunden-Hänger führte. Fix: Drain in `triggerAlarm()` läuft jetzt über
`player.available()`/`player.read()` statt über rohe Bytes (analog zu
`readStateDrained()`).

**DFRobotDFPlayerMini.cpp bleibt daher unverändert im Originalzustand.**
Kein Patch nach (Neu-)Installation nötig.

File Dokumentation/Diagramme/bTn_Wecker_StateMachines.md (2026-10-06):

# bTn Wecker – State Machines

*Firmware 21v02 · Mermaid-Diagramme*

> ⚠ **Maßgeblich ist diese Datei.** Die ursprüngliche Vorlage
> `DOC/bTn_Wecker_StateMachines.pptx` (Stand 2026-04-20) ist seit vielen
> Firmware-Ständen nicht mehr nachgeführt und nur noch historisch – Änderungen
> hier NICHT in die pptx zurückspiegeln.

> **Pin-Hinweis:** Taster S1=GPIO33, S2=GPIO32 (seit 20v28 getauscht), S3=GPIO0.
> Ausgänge E1=GPIO27 (Kuckuck), E2=GPIO25 (Mühlrad-Motor), E3=GPIO26 (Licht) – seit
> 20v29 umbelegt. Beide Tauschaktionen betreffen nur die Pin-Konstanten in
> `SysConf_*.h`, keine der hier gezeigten State-Machines.

---

## 1. Alarm-State-Machine

*alarmTask (Core 0, Pri 2) · Takt 500 ms*

```mermaid
stateDiagram-v2
    [*] --> ALARM_IDLE
    ALARM_IDLE --> triggerAlarm : alarmDue() == true<br/>Tages-Sperre (yday≠lastA1Day) · Nachholfenster (ALARM_CATCHUP_MIN)<br/>DST-Sonderfall bei Weckzeit-Stunde 02 (a2 analog)
    triggerAlarm --> ALARM_RUNNING : verifyPlayStarted() == PLAY_OK / PLAY_NO_SOUND<br/>(Play-Befehl bestätigt bzw. Modul lebt ohne Ton)
    triggerAlarm --> ALARM_IDLE : verifyPlayStarted() == PLAY_CANCELLED<br/>(S1/Vorschau/Menü waehrend Verifikation) → Tages-Sperre setzen, kein Neustart
    triggerAlarm --> Neustart : verifyPlayStarted() == PLAY_CRASHED<br/>failCount < ALARM_MAX_RESTARTS (3)<br/>→ rtcRetryMagic gesetzt, ESP.restart()
    triggerAlarm --> ALARM_IDLE : verifyPlayStarted() == PLAY_CRASHED<br/>failCount ≥ ALARM_MAX_RESTARTS<br/>→ [FEHLER]-Eintrag, endgültiger Abbruch
    Neustart --> triggerAlarm : setup() liest rtcRetryMagic<br/>(RTC_NOINIT_ATTR übersteht ESP.restart())<br/>→ Alarm erneut auslösen
    ALARM_RUNNING --> ALARM_IDLE : mp3Finished (playerStatus==0 ODER<br/>playerStatus==-1 + dfPlayerIdleDebounced())<br/>ODER runTimeExceeded (ALARM_MAX_RUN_MS, 15 min)
    ALARM_RUNNING --> ALARM_IDLE : S1 – manueller Abbruch
    ALARM_RUNNING --> ALARM_RUNNING : alle ALARM_POLL_MS (5 s)<br/>readStateDrained() · BUSY-Pin (GPIO35) als Zusatzkriterium
```

**Bedingungen**

- **IDLE → triggerAlarm:** `alarmDue(a1_on, a1_hour, a1_min, hour, min, yday, lastA1Day, isdstNow)` (20v21) – pegel-/tagesbasiert statt Minuten-Flanke: `yday != lastA1Day` (Tages-Sperre, ersetzt die frühere Minuten-Sperre `lastA1Min`) UND Differenz Ist-/Soll-Zeit innerhalb `ALARM_CATCHUP_MIN` (60 min, Nachholfenster für Zeitsprünge/Reboots/Zeitumstellung); Alarm 2 analog.
- **Tages-Sperre aufheben (20v22/20v27):** `lastA1Day`/`lastA2Day` = `0xFFFF` wird NICHT mehr bei jedem `h+`/`min+`-Tastendruck in `onAlarm1()`/`onAlarm2()` gesetzt, sondern erst in `uiTransition()` beim Verlassen von `UI_ALARM1`/`UI_ALARM2` – und auch dann nur, wenn `alarm1TimeEdited`/`alarm2TimeEdited` gesetzt ist (Weckzeit wurde per T3/T4 tatsächlich verändert). Verhindert (a) vorzeitiges Auslösen auf Zwischenständen beim Durchscrollen einer neuen Weckzeit und (b) erneutes Auslösen, wenn die Alarm-Seite nur angeschaut wird.
- **DST-Sonderfall (20v21, nur Weckzeiten mit Stunde 02):** `updateDstDayFlags()` erkennt beide Umstellungstage TZ-generisch über `mktime()`/`tm_isdst` (Vergleich Stunde 1 vs. Stunde 4). Frühjahr (`dstSpringForwardToday`): effektive Stunde wird in `alarmDue()` um 1h vorgezogen (`effH = h-1`), da die Wanduhrzeit 02:00–02:59 an diesem Tag nicht existiert. Herbst (`dstFallBackToday`): der erste (CEST-)Durchlauf der doppelten Stunde 02 wird per `isdstNow==1` ignoriert, erst der zweite (CET-)Durchlauf löst aus. Zweck: der reale zeitliche Abstand Weckzeit→Termin bleibt unabhängig von der Zeitumstellung erhalten.
- **Alarm 1 Vorrang:** Alarm 2 wird nur per `else if` geprüft → Alarm 1 hat Vorrang bei gleicher Zeit.
- **triggerAlarm() → ALARM_RUNNING:** `drainSerial2Pre()` räumt den Serial2-Puffer über die Bibliothek ab (12v14/12v19), setzt Lautstärke mit Untergrenze `ALARM_MIN_VOL` (10, 20v12 – schützt gegen ein durch klemmendes Touch-Pad auf 0 heruntergezähltes `vol`, ohne die gespeicherte Einstellung zu verändern), dann `playFolder()` + `verifyPlayStarted()` (bis zu `VERIFY_PLAY_RETRIES`=3 Versuche à `VERIFY_PLAY_DELAY_MS`=500 ms). `PLAY_OK` und `PLAY_NO_SOUND` (Modul lebt, Datei startet nicht hörbar – `alarmSilentFallback`) laufen beide in denselben Erfolgspfad: Motor/Licht ein, `wakeDisplay()` (10v03), `alarmState = ALARM_RUNNING`, Tages-Sperre wird über `lockAlarmDayGuard()` erst NACH bestätigtem Start gesetzt.
- **triggerAlarm() → ALARM_IDLE (PLAY_CANCELLED, 20v12/20v15):** Nutzer hat während der ~1,5 s-Verifikation bewusst gestoppt (S1 immer; Sound-Vorschau/Funktionswahl-Menü nur wenn der Alarm bereits hörbar `ALARM_RUNNING` war, siehe `requestAlarmCancelIfActive(includeStartup)`). Kein Neustart, Tages-Sperre wird trotzdem gesetzt (sonst löste `alarmDue()` im nächsten Tick sofort erneut aus).
- **triggerAlarm() → Neustart (12v05/12v07/12v10, weiterhin RTC_NOINIT_ATTR-basiert):** Bestätigt der DFPlayer den Play-Befehl über keinen der Versuche (`PLAY_CRASHED`), gilt er als abgestürzt. Alarmnummer/Datei/Minute/Fehlversuche werden in `RTC_NOINIT_ATTR`-Variablen (`rtcRetryMagic`/`-Alarm`/`-FileNo`/`-Min`/`-Count`) hinterlegt (übersteht `ESP.restart()`, NICHT aber Reset-Taster/Neuflashen – das ist ein echter Power-On), danach Neustart. Ab `ALARM_MAX_RESTARTS` (3, seit 12v10) Fehlversuchen kein weiterer Neustart mehr, Alarm bricht für diesen Tag endgültig ab (roter `[FEHLER]`-Eintrag im Web-Log).
- **watchdogTask-Fallback (12v12):** Friert `alarmTask` mitten in `triggerAlarm()` ein (`alarmTriggerInFlight`-Marker), setzt `watchdogTask` selbst `rtcRetryMagic` vor seinem eigenen Neustart – sonst bliebe der Alarm nach diesem Freeze-Neustart ersatzlos aus. Seit 20v06 redundant (siehe unten), aber als Sicherheitsnetz belassen.
- **RUNNING → IDLE (mp3Finished, 20v00/20v03):** `playerStatus==0` (MP3 beendet) ODER `playerStatus==-1` UND `dfPlayerIdleDebounced()` bestätigt idle über den BUSY-Pin (GPIO34, Hardware ab 2v0, 3 Abtastungen à 5 ms). Löst den bisherigen reinen UART-Timeout-Fallback ab. Bei `alarmSilentFallback` (PLAY_NO_SOUND) bleibt dieser Ausstieg gesperrt – einziger Ausstieg dann `runTimeExceeded`.
- **RUNNING → IDLE (runTimeExceeded, 20v05/A3):** harte Obergrenze `ALARM_MAX_RUN_MS` (15 min) als Rückfallebene, falls der BUSY-Pin dauerhaft LOW hängt (Modulfehlfunktion/Leitungsfehler) und `dfPlayerIdleDebounced()` nie „idle" meldet.
- **playerMutex:** schützt `playFolder()` und `readState()`/`readStateDrained()`. `vTaskDelay(1 ms)` liegt AUSSERHALB des Mutex (Projektregel).
- **playerStatus:** `== 0` (seit 9v4, war vorher `< 1`) – verhindert Fehlabbruch bei `readState()`-Timeout (UART-Konflikt mit `webLogTask`).
- **readStateDrained() (12v09/13v00):** liest alle vollständigen Frames aus dem Puffer und wertet nur den zuletzt empfangenen Feedback-Wert; wartet nach einem `-1` zusätzlich bis zu `SERIAL2_FEEDBACK_GRACE_MS` (100 ms) aktiv auf einen echten Feedback-Frame, statt sofort aufzugeben (behebt „kein Start-Status nach playFolder").
- **RTC-Merker-Löschung (20v06/B2-Fix):** `rtcRetryMagic` wird bereits beim Setzen von `triggerAlarm()` geschrieben (nicht erst im Fehlerpfad) und beim ersten `playerStatus>0`-Poll bzw. beim Verlassen von `ALARM_RUNNING` wieder gelöscht – ein Freeze/Reset zwischen `playFolder()` und der ersten bestätigten Wiedergabe verliert den Alarm dadurch nicht mehr ersatzlos.

---
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

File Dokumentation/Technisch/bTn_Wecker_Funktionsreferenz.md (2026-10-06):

# bTn Wecker – Funktions- und Task-Referenz

*Firmware 21v02 · ESP32 / FreeRTOS*

## 1. FreeRTOS Tasks

9 Tasks auf Core 0 und Core 1. Priorität 2 > Priorität 1.

**Pin-Belegung (Hardware 2v0 / Firmware 21v02):** Taster S1=GPIO33, S2=GPIO32, S3=GPIO0
(S1/S2 seit 20v28 getauscht). Ausgänge E1=GPIO27 (Kuckuck), E2=GPIO25 (Mühlrad-Motor,
LEDC-PWM), E3=GPIO26 (Licht) – seit 20v29 umbelegt (vorher E1=25, E2=26, E3=27).
DFPlayer-BUSY=GPIO35, OLED-I²C SDA=GPIO21 / SCL=GPIO19 (SCL seit 21v02, vorher GPIO22). Die Firmware spricht alle Ein-/Ausgänge ausschließlich über die
symbolischen Konstanten `S1`–`S3` / `E1`–`E3` an; bei den GPIO-Tauschaktionen 20v28/20v29
wurden nur diese Konstantenwerte in `SysConf_*.h` geändert, keine Logik.
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

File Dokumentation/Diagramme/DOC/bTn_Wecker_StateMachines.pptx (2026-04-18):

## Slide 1

Alarm-State-Machine · alarmTask (Core 0, Pri 2) · Takt: 500 ms

Alarmzeit erreicht (a2 analog a1):
sec==0
min==a1_min
hour==a1_hour
min≠lastA1Min

alle ALARM_POLL_MS: readState()

ALARM_IDLE

kein Alarm aktiv

ALARM_RUNNING

MP3 spielt
Ausgänge aktiv

playerStatus == 0 (MP3 beendet)
alle ALARM_POLL_MS (5 s)

S1

S1: manueller Abbruch
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

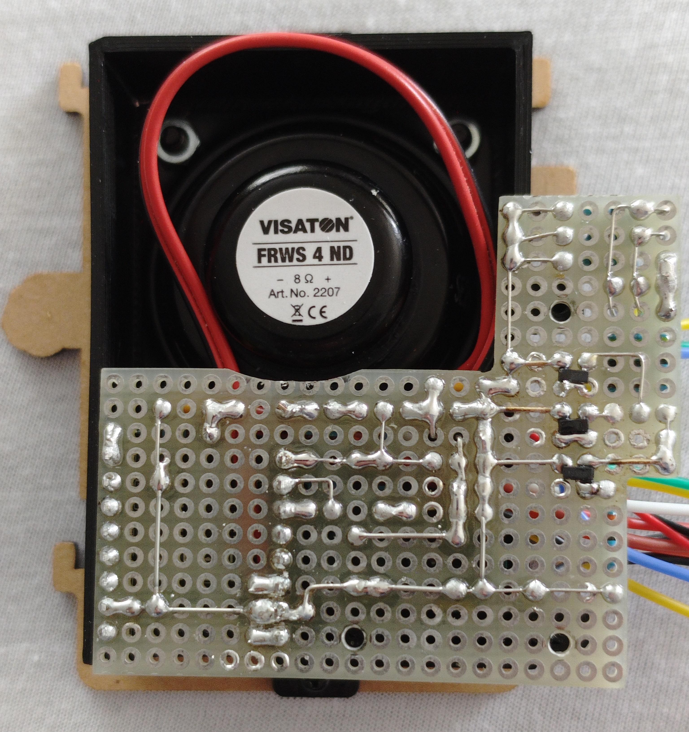
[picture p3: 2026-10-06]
Hardware/Fotos/Lautsprecher-Modul Lötseite.jpg

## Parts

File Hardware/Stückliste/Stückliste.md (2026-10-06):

# Stückliste – bTn Wecker Projekt

## 1. Mechanik

| Bauteil | Hersteller | Artikel | Lieferant | Preis |
| --- | --- | --- | --- | ---: |
| Cuckoo Clock | ROKR | LC901C | Amazon | 59,45 € |
| Getriebemotor 6mm 3V | Garosa | B085NG5ZCY 4-fach | Amazon | 9,89 € |

## 2. Elektronik

| Bauteil | Hersteller | Artikel | Lieferant | Preis |
| --- | --- | --- | --- | ---: |
| Netzteil | Anker | 323 Charger (33W) | Amazon | 11,99 € |
| ESP32 DEV Kit C V4 | AZ-Delivery | ESP32WROOM32 | AZ-Delivery | 10,99 € |
| OLED 0,96" | APKLVSR | SSD1306OLED | Amazon | 3,54 € |
| DFPlayer Mini | DFRobot | DFR0299 | AZ-Delivery | 2,10 € |
| Micro SD-Card 32GB | Lexar | LMSESXX032G-B2AEU | Amazon | 14,00 € |
| Lautsprecher | Visatone | FRWS 4 ND Breitband 8 Ohm | Voelkner | 16,89 € |

## 3. Motor-Treiber

Bauteile des Motor-Treibers (Schaltplan `Hardware/Schaltplan/Motor-Treiber.md`,
Ansteuerung GPIO25/E2 per PWM). Der DC-Motor selbst steht unter „1. Mechanik"
(Getriebemotor 6mm 3V) und liegt an der über MCP1700T-3302E/TO auf 3,3V
geregelten Rail (Hardware 2v0, ersetzt die bisherige Direktversorgung mit 5V
ohne Regler). Einkaufsdaten noch offen – Hersteller/Artikel/Lieferant/Preis
als „–".

| Bauteil | Hersteller | Artikel | Lieferant | Preis |
| --- | --- | --- | --- | ---: |
| LDO Spannungsregler 3,3V | Microchip | MCP1700T-3302E/TO | – | – |
| MOSFET IRLML6344 (N-Channel Logic-Level, SOT-23) | – | – | – | – |
| Widerstand 470 Ω (Gate-Reihe) | – | – | – | – |
| Widerstand 10 kΩ (Gate-Pull-Down) | – | – | – | – |
| Widerstand 10 Ω (Snubber, mit 10 nF) | – | – | – | – |
| Elko 100 µF (Rail-Stützkondensator) | – | – | – | – |
| Keramik-Kondensator 100 nF (Entstörung) | – | – | – | – |
| Keramik-Kondensator 10 nF (Snubber, mit 10 Ω) | – | – | – | – |
| Diode 1N4448 (Freilaufdiode, schnell) | – | – | – | – |

## 4. LED-Treiber

Bauteile des LED-Treibers (Schaltplan `Hardware/Schaltplan/LED-Treiber.md`,
Ansteuerung GPIO26/E3, Licht). Einkaufsdaten noch offen –
Hersteller/Artikel/Lieferant/Preis als „–".

| Bauteil | Hersteller | Artikel | Lieferant | Preis |
| --- | --- | --- | --- | ---: |
| MOSFET IRLML6344 (N-Channel Logic-Level, SOT-23) | – | – | – | – |
| Widerstand 470 Ω (Gate-Reihe) | – | – | – | – |
| Widerstand 10 kΩ (Gate-Pull-Down) | – | – | – | – |
| Widerstand 47 Ω / 0,25W (LED-Vorwiderstand) | – | – | – | – |
| LED-Streifen (2,8V / 48mA) | – | – | – | – |

## 5. Kuckuck-Treiber

Bauteile des Kuckuck-Treibers (Schaltplan `Hardware/Schaltplan/Kuckuck-Treiber.md`,
Ansteuerung GPIO27/E1). Das Kuckuck-Modul selbst steht unter „1. Mechanik"
(Cuckoo Clock). Einkaufsdaten noch offen – Hersteller/Artikel/Lieferant/Preis
als „–".

| Bauteil | Hersteller | Artikel | Lieferant | Preis |
| --- | --- | --- | --- | ---: |
| MOSFET IRLML6344 (N-Channel Logic-Level, SOT-23) | – | – | – | – |
| Widerstand 470 Ω (Gate-Reihe) | – | – | – | – |
| Widerstand 10 kΩ (Gate-Pull-Down) | – | – | – | – |
| Elko 100 µF (Modul-Stützkondensator) | – | – | – | – |
| Keramik-Kondensator 100 nF (Entstörung) | – | – | – | – |

## 6. Analoguhrwerk-Spannungsregler

Spannungsversorgung für das 1,5V-Analoguhrwerk (Schaltplan U4, KiCad
`Hardware/Schaltplan/KiCad_Wecker_2v0/`). Das Uhrwerk selbst ist Teil des
ROKR-Kits und steht bereits unter „1. Mechanik" (Cuckoo Clock).

| Bauteil | Hersteller | Artikel | Lieferant | Preis |
| --- | --- | --- | --- | ---: |
| LDO Spannungsregler 1,5V | Microchip | MCP1702-1502TO | reichelt | 0,99 € |
| Keramik-Kondensator 4,7 µF (Ausgang, X7R) | – | – | – | – |

## 7. DFPlayer-BUSY-Filter

RC-Filter für das DFPlayer-BUSY-Signal (Schaltplan
`Hardware/Schaltplan/DFPlayer-BUSY.md`, GPIO35, ab Hardware 2v0). Einkaufsdaten
noch offen – Hersteller/Artikel/Lieferant/Preis als „–".

| Bauteil | Hersteller | Artikel | Lieferant | Preis |
| --- | --- | --- | --- | ----: |
| Widerstand 1 kΩ (BUSY-Reihenwiderstand)  | – | – | – | – |
| Kondensator 100 nF (BUSY-Tiefpass) | – | – | – | – |

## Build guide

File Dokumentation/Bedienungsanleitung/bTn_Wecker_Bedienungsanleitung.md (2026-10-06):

# bTn Wecker – Bedienungsanleitung

*Firmware 21v02 · ESP32 / FreeRTOS · Hardware 2v0*

## 1. Übersicht

Der bTn Wecker ist ein ESP32-basierter Wecker mit OLED-Anzeige, MP3-Wiedergabe (DFPlayer Mini), kapazitiven Touch-Feldern, drei Drucktastern und WiFi/NTP-Zeitsynchronisation. Alle Einstellungen werden dauerhaft im internen Flash gespeichert.

| Taste / Element | Funktion |
| --- | --- |
| Display | SSD1306 OLED 128×64 Pixel, I²C |
| MP3-Player | DFPlayer Mini, SD-Karte, Ordner 01 = Alarm-Sounds. Ab Hardware 2v0 zusätzlich mit BUSY-Signal (GPIO35) überwacht |
| Touch-Felder | T0, T2, T3, T4 – kapazitiv, Hold + Repeat |
| Drucktaster | S1, S2, S3 |
| Ausgänge | E1 = Kuckuck, E2 = Mühlrad/Motor, E3 = Licht |
| WiFi / NTP | WLAN-Verbindung für automatische Zeitsynchronisation |
| Web-Log | Diagnose-Seite im Browser: http://IP:8080, inkl. Mühlrad-Motor-Regler |

## 2. Bedienelemente

| Taste / Element | Funktion |
| --- | --- |
| T0  (Touch) | Menüseite vorwärts: 0 → 1 → 2 → 3 → 4 → 5 → 6 → 0  (zyklisch) |
| T2  (Touch) | Checkbox Ein/Aus auf der aktuellen Seite<br>auf Seite 3/4: Vorschau-Sound |
| T3  (Touch) | Wert erhöhen: Stunde +, Von-Zeit +, Lautstärke +<br>Hold: Dauerwiederholung |
| T4  (Touch) | Wert erhöhen: Minute +, Bis-Zeit +<br>Hold: Dauerwiederholung  ·  Seite 0: Lautstärke – |
| S1  (Taster) | Laufenden Alarm oder Sound stoppen<br>wenn kein Alarm: Kuckuck einmalig auslösen |
| S2  (Taster) | Zugschalter: Licht (E3) und Mühlrad (E2) gleichzeitig Ein/Aus toggeln. Schaltet nach 30 Minuten ohne erneuten Tastendruck automatisch wieder ab |
| S3  (Taster) | Info-Seite ein-/ausblenden (von jeder Seite aus erreichbar)<br>Bei ausgeschaltetem Display weckt S3 das Display und öffnet die Info-Seite (11v04) |

**Hold-Funktion:**  Touch-Felder T3 und T4 unterstützen Dauerberührung. Nach 750 ms wechselt das Feld in den Repeat-Modus und sendet alle 250 ms einen weiteren Impuls – nützlich für schnelles Einstellen von Stunden und Minuten. Klemmt ein Touch-Feld dauerhaft (z.B. durch Feuchtigkeit), erzwingt die Firmware nach einigen Sekunden einen Reset des betroffenen Felds, damit z.B. die Lautstärke nicht unbemerkt bis auf 0 heruntergezählt wird.

## 3. Menüstruktur

T0 wechselt die Seiten 0–6 zyklisch. S3 öffnet jederzeit die Info-Seite (Seite 7). Nach 20 Sekunden ohne Eingabe kehrt das Gerät automatisch zu Seite 0 zurück – auch von der Info-Seite. Nach 5 Minuten ohne Touch-Eingabe schaltet das OLED-Display ab; eine Berührung eines Touch-Felds (T0–T4) weckt das Display und verwirft das Event, während S3 das Display weckt und direkt die Info-Seite öffnet (11v04).

| Seite | Name | Inhalt |
| ----- | --- | --- |
| 0 | Uhrzeit | Zeitanzeige (groß), Datum, beide Alarmzeiten mit Checkbox, aktuelle Lautstärke. T3 = Vol+, T4 = Vol–. |
| 1 | Alarm 1 einstellen | T2 = Alarm 1 Ein/Aus  ·  T3 = Stunde +  ·  T4 = Minute +  (beide mit Überlauf) |
| 2 | Alarm 2 einstellen | T2 = Alarm 2 Ein/Aus  ·  T3 = Stunde +  ·  T4 = Minute + |
| 3 | Sound 1 wählen | T2 = Vorschau Ein/Aus (spielt Sound sofort)<br>T3 = Datei +  ·  T4 = Datei – |
| 4 | Sound 2 wählen | T2 = Vorschau Ein/Aus  ·  T3 = Datei +  ·  T4 = Datei – |
| 5 | Funktionen | T2 = Kuckuck Ein/Aus<br>T3 = Licht Ein/Aus<br>T4 = Mühlrad Ein/Aus |
| 6 | Kuckuck-Zeit | T3 = Von-Stunde +  ·  T4 = Bis-Stunde +<br>(0–23, Mitternacht-Überlauf möglich) |
| 7 | Info  (S3) | Web-Log-Adresse (IP:8080), MP3-Dateianzahl, Reset-Zähler, Warnhinweise „Taste + WiFi Reset" (T3) und „Taste – Full Reset" (T4). Details siehe Abschnitt 7. |

## 4. Alarmfunktion

Der Wecker löst zur eingestellten Zeit aus, wenn der Alarm aktiviert ist (Checkbox auf Seite 1 oder 2). Die MP3-Datei wird aus Ordner 01 der SD-Karte abgespielt.

| Taste / Element | Funktion |
| --- | --- |
| Vorrang | Alarm 1 hat Vorrang, wenn beide Alarme auf die gleiche Zeit eingestellt sind |
| Stoppen | S1 drücken – stoppt den Sound und alle Ausgänge (E2, E3) |
| Licht bei Alarm | E3 (Licht) wird beim Alarm-Start eingeschaltet, wenn Checkbox auf Seite 5 aktiv |
| Mühlrad bei Alarm | E2 (Mühlrad) wird beim Alarm-Start eingeschaltet, wenn Checkbox auf Seite 5 aktiv |
| Mindestlautstärke | Ist die eingestellte Lautstärke sehr niedrig, spielt der Alarm trotzdem mit einer festen Mindestlautstärke – die gespeicherte Einstellung selbst bleibt dabei unverändert |
| Wiederholung | Derselbe Alarm kann am selben Kalendertag nicht erneut auslösen (Tages-Sperre). Nur wenn die Weckzeit auf der Einstellseite tatsächlich mit T3/T4 verändert wurde, wird die Sperre beim Verlassen der Seite für diesen Tag aufgehoben – ein bloßer Seitenbesuch ohne Änderung lässt die Sperre bestehen |
| Nachholfenster | Verpasst der Wecker den genauen Auslösezeitpunkt (z.B. durch einen kurzen Stromausfall), löst der Alarm innerhalb der folgenden Stunde nachträglich noch aus, statt ersatzlos zu entfallen |
| Display-Wake | OLED wird beim Alarm-Start automatisch eingeschaltet, falls es zuvor nach 5 Minuten Ruhezeit abgeschaltet wurde |

### Weckzeit bei Zeitumstellung (02:00–02:59 Uhr)

Der Wecker weckt in erster Linie, damit ein nachfolgender Termin pünktlich erreicht wird. Deshalb bleibt bei einer Weckzeit **zwischen 02:00 und 02:59 Uhr** der zeitliche Abstand zwischen Wecken und Termin auch an den beiden Tagen der Zeitumstellung erhalten – der Wecker verhält sich an diesen Tagen bewusst anders als eine gewöhnliche Uhr:

- **Umstellung auf Sommerzeit** (letzter Sonntag im März, die Uhr springt von 01:59:59 direkt auf 03:00:00 – die Zeit 02:00–02:59 Uhr gibt es an diesem Tag gar nicht): Eine Weckzeit in diesem Bereich löst bereits **eine Stunde früher**, also schon zwischen 01:00 und 01:59 Uhr, aus. Ohne diese Vorverlegung würde der Wecker sonst erst um 03:00 Uhr klingeln – bis zu 59 Minuten zu spät.
- **Umstellung auf Winterzeit** (letzter Sonntag im Oktober, die Zeit 02:00–02:59 Uhr kommt an diesem Tag **zweimal** vor): Eine Weckzeit in diesem Bereich löst erst beim **zweiten** Durchlauf dieser Stunde aus, nicht schon beim ersten. Ohne diese Verzögerung würde der Wecker sonst bis zu 60 Minuten zu früh klingeln.

Betroffen sind ausschließlich Weckzeiten mit Stunde 02 – alle anderen Weckzeiten sind von der Zeitumstellung nicht berührt.

## 5. Kuckucksfunktion

Der Kuckuck (E1) löst automatisch zur vollen Stunde aus, wenn die Funktion aktiviert und die aktuelle Stunde im eingestellten Zeitfenster liegt.

| Taste / Element | Funktion |
| --- | --- |
| Aktivieren | Checkbox auf Seite 5 (T2) |
| Zeitfenster | Seite 6: Von-Stunde (T3) und Bis-Stunde (T4). Mitternacht-Überlauf möglich (z.B. 22–06 Uhr) |
| Manuell | S1 drücken, wenn kein Alarm läuft → Kuckuck einmalig auslösen (unabhängig von Zeitfenster und Checkbox) |
| Dauer | 7,5 Sekunden |
| Unterdrückt | Wenn Alarm 1 oder Alarm 2 auf dieselbe volle Stunde eingestellt ist |
| Zeitumstellung  | An beiden Zeitumstellungstagen ist die betroffene Stunde 02:00 Uhr durch eine Tag+Stunden-Sperre geschützt – der Kuckuck löst dort auch bei der doppelten Herbststunde nur einmal aus |

## 6. Sound-Vorschau (Seite 3 / 4)

Auf den Seiten 3 und 4 kann der Alarm-Sound vor dem Speichern angehört werden.

| Taste / Element | Funktion |
| --- | --- |
| T2 | Vorschau toggeln: Sound wird sofort abgespielt oder gestoppt |
| T3 | Nächste Dateinummer – der neue Sound wird sofort als Vorschau abgespielt, wenn Vorschau aktiv |
| T4 | Vorherige Dateinummer – analog T3 |
| Speichern | Die gewählte Nummer wird als Alarm-Sound gespeichert, sobald Seite 3/4 verlassen wird |

## 7. Info-Seite (S3)

Die Info-Seite zeigt Systemdaten und bietet Zugang zu Konfigurations- und Reset-Funktionen. Seit 11v02 werden die gefährlichen Aktionen explizit als Zeilen auf der Info-Seite benannt – die früher dort zusätzlich angezeigten WiFi-/NTP-Zeitstempel sind in den Web-Log umgezogen (siehe Abschnitt 8). Ab 11v05 wurden die WLAN-Reset-Taste von T0 auf T3 verlegt und die Zeilen auf die einheitliche „+ / –"-Bedienung umgestellt (Taste + = T3, Taste – = T4).

| Zeile | Inhalt |
| --- | --- |
| 1 – Kopfzeile | Firmware-Kennung (z.B. `bTn_Wecker_21v02`) |
| 2 – IP:8080 | Adresse des Web-Log-Servers – im Browser öffnen für Diagnoseinformationen |
| 3 – MP3 *nnn* RESET *nnnn* | Anzahl gefundener MP3-Dateien  ·  Neustart-Zähler (4-stellig) |
| 4 – Taste +  WiFi Reset | Hinweis: T3 drücken löscht die WLAN-Zugangsdaten und startet den Konfigurator |
| 5 – Taste –  Full Reset | Hinweis: T4 drücken löscht alle Einstellungen (NVS-Erase) und startet neu |

**Sicherheit:**  Ist das Display ausgeschaltet, wecken die Touch-Felder T0–T4 nur das Display – das auslösende Event wird verworfen. So kann ein blind getippter Touch auf der Info-Seite nicht versehentlich T3 (WLAN-Reset, seit 11v05; vorher T0) oder T4 (Werksreset) auslösen. S3 weckt das Display und öffnet die Info-Seite direkt (11v04); die Auto-Rückkehr nach 20 s Inaktivität stellt sicher, dass das Display nur von Seite 0 aus abschaltet, der S3-Aufruf also reproduzierbar zur Info-Seite führt.

## 8. Web-Log (http://IP:8080)

Nach der WiFi-Verbindung ist ein Diagnose-Server erreichbar. Die IP-Adresse wird auf der Info-Seite (S3) angezeigt sowie einmalig auf Serial ausgegeben.

| Endpunkt | Inhalt |
| --- | --- |
| GET / | HTML-Seite mit farbiger Darstellung: grün = OK, rot = Fehler/Freeze, gelb = Warnung. Auto-Refresh alle 20 Sekunden. |
| GET /log | Plain-Text-Ausgabe aller Log-Einträge – für curl, wget oder Browser-Download |
| GET /motor | Setzt die Mühlrad-Pulsweite (siehe Regler unten) direkt über einen Parameter, z.B. für eigene Skripte |

**Sektionen (in Anzeigereihenfolge):**

| Sektion | Inhalt |
| --- | --- |
| Allg. Log | Ring-Puffer mit den übrigen Systemereignissen (Start, WiFi/NTP-Events, Watchdog, Alarme). Titel lautet „Allgemeines Log – letzter Reset: *&lt;NTP-Zeitstempel&gt;*" (Zeitpunkt des ersten NTP-Syncs nach dem Reset). Die Reset-Ursache (`[RESET] Ursache: …`) erscheint dort ab 21v02 stets als letzte Zeile, unabhängig vom chronologischen Zeitpunkt. |
| Verbindung – letzter WiFi Reconnect / NTP Sync | Zeigt die Zeitstempel der letzten WiFi-Verbindung und der letzten NTP-Synchronisation (11v02: umbenannt von „Status – Letzter Start" und unter den Ring-Puffer verschoben) |
| Touch-Baseline | Letzter Messwert und Schwellwert aller vier Touch-Pads |
| Stack High-Water Marks | Speicherauslastung aller 9 Tasks + freier Heap |
| DFPlayer | Eigener Ring-Puffer-Ausschnitt mit allen DFPlayer-Meldungen (Start-Check, Absturz-Neustart, Serial2-Restbytes). Titel lautet „DFPlayer – letzter erfolgreicher Alarm: *&lt;Zeitstempel&gt;*" (12v08) |
| Mühlrad-Motor – Pulsweite (Drehzahl) | Schieberegler 0–100 %, stellt die Motor-Drehzahl live um und speichert den Wert dauerhaft. Unterhalb von 35 % gibt der Motor beim Start automatisch einen kurzen Vollgas-Anlaufimpuls (Kickstart), da der Motor sonst nicht anläuft (12v03) |

**Tipp:**  Der Web-Log ist nur verfügbar, wenn der Wecker mit dem WLAN verbunden ist. Die Adresse lautet z.B. `http://192.168.1.42:8080`.

**Hinweis „Lautstaerke+/- fehlgeschlagen (Mutex belegt)":**  Während ein Alarm läuft, fragt der Wecker den DFPlayer-Status alle 5 Sekunden kurz ab und belegt dafür kurzzeitig den internen Player-Zugriff. Trifft ein Tastendruck auf T3/T4 (Lautstärke +/–) genau in dieses Fenster, wird dieser eine Druck verworfen und im Log als Fehler vermerkt – Anzeige und Lautstärke bleiben für diesen Druck bewusst unverändert, damit nie ein falscher Wert angezeigt oder gespeichert wird. Bei mehrfachem/gehaltenem Tippen (Touch-Repeat) wirken die übrigen Drücke im selben Moment normal, sodass die Lautstärke trotz einzelner Fehlermeldung sichtbar ansteigt. Kein Fehlverhalten – kein Handlungsbedarf.

## 9. WiFi-Konfiguration

**Erstkonfiguration:**  Beim ersten Start (oder nach Werksreset) öffnet der Wecker automatisch einen WLAN-Accesspoint mit der SSID `bTn-Wecker`. Mit Smartphone oder PC verbinden, Browser öffnen und `192.168.4.1` aufrufen. SSID und Passwort eingeben und speichern – der Wecker startet neu und verbindet sich.

**Neue WLAN-Konfiguration:**  Info-Seite (S3) öffnen → T3 (Taste +) drücken. WLAN-Zugangsdaten werden gelöscht und der Konfigurator startet. *(Bis 11v04 lag diese Funktion auf T0; seit 11v05 einheitlich T3, analog zur „Taste –"-Belegung des Werksresets auf T4.)*

| Feld | Regel |
| --- | --- |
| SSID | 1–32 Zeichen, Groß-/Kleinschreibung beachten |
| Passwort | Leer lassen für offene Netzwerke. Sonst 8–63 Zeichen. |
| Fehler | Bei falschen Zugangsdaten erscheint eine Fehlermeldung auf der Konfigurationsseite |

## 10. Werksreset

Info-Seite (S3) öffnen → T4 drücken. Alle gespeicherten Einstellungen (Alarmzeiten, Sounds, Lautstärke, Funktionen, Kuckuck-Zeitfenster, Mühlrad-Pulsweite) und WiFi-Zugangsdaten werden unwiderruflich gelöscht. Der Wecker startet neu und öffnet den WiFi-Konfigurator.

**Hinweis:**  Der Reset-Zähler wird ebenfalls zurückgesetzt. Ab 11v03 wird der Konfigurator-Boot nach einem Werksreset nicht mehr mitgezählt – nach erfolgreicher WLAN-Einrichtung zeigt der Zähler `0001` (früher `0002`).

---

*bTn Wecker  ·  Bedienungsanleitung  ·  Firmware 21v02*

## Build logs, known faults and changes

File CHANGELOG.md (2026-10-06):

**bTn Wecker**

Änderungshistorie

Basis 4v1  →  13v00 (Hardware 1v0, eingefroren)  →  20v03 (Hardware 2v0, DFPlayer-BUSY an GPIO34, ab 21v01 GPIO35)

## Kategorien

| Bugfix | Stabilität | Funktion | Refactoring | Qualität |
|---|---|---|---|---|

## Versionen 4v1 – 5v4  (Arduino-Basis)

| Version | Kategorie | Änderung |
|---|---|---|
| 4v2 | Bugfix | Touch T3/T4 Lautstärke vertauscht – korrigiert |
| 4v2 | Bugfix | Maximale Lautstärke auf 20 begrenzt (max_vol) |
| 4v2 | Bugfix | NVS-Lautstärke-Clamp beim Laden auf max_vol |
| 4v3 | Stabilität | Touch-Schwellwert: Fallback auf 80% der Baseline wenn Baseline < TOUCH_DROP |
| 4v4 | Bugfix | Alarm 2 auf else-if: Alarm 1 hat Vorrang bei gleicher Weckzeit |
| 4v5 | Bugfix | readFileCounts() Unterlauf-Fix: c==0 verhindert uint8_t-Überlauf auf 255 |
| 5v0 | Stabilität | readState()-Schleife: Timeout 200 ms verhindert Hänger bei DFPlayer-Ausfall |
| 5v1 | Qualität | Alle sprintf() durch snprintf() ersetzt |
| 5v2 | Funktion | Reset-Zähler im NVS; Werksreset via T4 auf Info-Seite |
| 5v2 | Funktion | Neue Funktion zeigeZ10R() für rechtsbündige OLED-Ausgabe |
| 5v3 | Qualität | Layout-Anpassungen Info-Seite |
| 5v4 | Funktion | Kuckuck unterdrückt wenn Alarm auf gleiche volle Stunde eingestellt |

## Versionen 6v0 – 7v2

| Version | Kategorie | Änderung |
|---|---|---|
| 6v0 | Funktion | Neue Menüseite 6: Kuckuck-Aktivzeit (Von/Bis-Stunde), NVS-gespeichert |
| 6v2 | Bugfix | Kuckuck-Zeitfenster: Mitternacht-Überlauf korrekt behandelt |
| 6v3 | Bugfix | lastCuckooMin nie zurückgesetzt – Kuckuck löste nur einmal aus |
| 6v4 | Stabilität | WiFi-Konfig- und Werksreset-Meldung unter displayMutex |
| 6v5 | Stabilität | wifiTask: lokaler tm-Snapshot via localtime_r() – kein Torn-Read |
| 6v6 | Qualität | zeigeZ-Parameter von String auf const char* – kein Heap-Overhead |
| 6v8 | Qualität | display.display() aus zeigeZ-Funktionen entfernt – zentraler Flush |
| 7v0 | Qualität | max_vol als constexpr MAX_VOL; varState lokal in setup() |
| 7v2 | Stabilität | alarmTask/runAlarmMachine/runCuckooMachine: eigener localtime_r()-Snapshot – Race Condition mit displayTask beseitigt |

## Versionen 7v3 – 7v9

| Version | Kategorie | Änderung |
|---|---|---|
| 7v3 | Stabilität | datum_WiFi / zeit_WiFi Double-Buffer – wifiTask schreibt in tmp-Puffer |
| 7v4 | Stabilität | readNVR(): alle Werte nach Laden geclampt |
| 7v5 | Qualität | goto wifi_skip durch bool wifiConnected ersetzt |
| 7v6 | Qualität | delay1–delay7 durch sprechende Konstantennamen ersetzt |
| 7v7 | Qualität | sound1/sound2 → sound1_selected/sound2_selected; sound1_play/sound2_play → sound1_assigned/sound2_assigned |
| 7v8 | Bugfix | setup(): display.display() an allen Stellen ergänzt – OLED blieb beim Start dunkel |
| 7v9 | Stabilität | Zwei-Stufen-Debouncing: ISR BTN_DEBOUNCE_MS=30ms, inputTask BTN_LOCKOUT_MS=1000ms |

## Versionen 8v0 – 8v2

| Version | Kategorie | Änderung |
|---|---|---|
| 8v0 | Bugfix | vTaskDelay(1ms) unter gehaltenem playerMutex → Freeze bei Alarm+Kuckuck 10:00 – Mutex vor Delay freigeben |
| 8v1 | Stabilität | alarmTask Core 1 → Core 0: physische Trennung von inputTask eliminiert CPU-Scheduling-Konflikte |
| 8v2 | Stabilität | Anwendungs-Watchdog (watchdogTask): überwacht inputTask/displayTask/alarmTask via Alive-Timestamps (30s/5s) |
| 8v2 | Bugfix | wdg_displayTask fehlte in displayTask – Timestamp vor Mutex-Versuch gesetzt |

## Versionen 9v0 – 9v2

| Version | Kategorie | Änderung |
|---|---|---|
| 9v0 | Stabilität | Hardware-TWDT (esp_task_wdt): inputTask, displayTask, alarmTask angemeldet; Timeout 15 s, trigger_panic=true |
| 9v0 | Qualität | Stack-Größen als STACK_*-Konstanten ausgelagert |
| 9v1 | Qualität | SystemConfig.h → SysConf_9v1.h umbenannt, Versionshistorie im Datei-Header eingeführt |
| 9v0 | Qualität | Stack-Größen angepasst: touchTask 3072, alarmTask 2048, inputTask 3072, displayTask 3072 |
| 9v1/9v2 | Funktion | Web-Logger: webLog()/webLogf() mit Thread-sicherem Ring-Puffer (Mutex-geschützt) |
| 9v1/9v2 | Funktion | webLogTask (Core 0, Pri 1): HTTP-Server Port 8080, GET / (HTML+Auto-Refresh), GET /log (plain text) |
| 9v1/9v2 | Funktion | Alle Serial.*-Ausgaben nach WiFi-Connect → webLog/webLogf (stackMon, watchdog, touch, wifi, setup) |
| 9v1/9v2 | Funktion | Letzte Serial-Ausgabe: IP-Adresse + Log-URL nach WiFi-Connect |
| 9v1/9v2 | Funktion | UI_INFO (Seite 7): Zeile 54 zeigt jetzt IP:Port des Web-Log-Servers statt SSID |
| 9v2 | Bugfix | webLogMutex fehlte in setup() → assert NULL pxQueue bei erstem Client-Zugriff – Mutex jetzt korrekt initialisiert |
| 9v2 | Bugfix | Lambda-Handler ohne Null-Prüfung auf webLogMutex – if(webLogMutex && ...) ergänzt |
| 9v2 | Qualität | WEBLOG_LINES 80 → 40 (Heap-Ersparnis ~5 KB) |
| 9v2 | Qualität | Auto-Refresh HTML 20 s → 10 s |
| 9v3 | Funktion | Web-Log-Seite: Touch-Baseline und Stack-HWM als dedizierte Snapshot-Sektionen – nur jeweils letzter Wert + Timestamp, kein Spam im Ring-Puffer |
| 9v4 | Bugfix | playerStatus == 0 statt < 1 in runAlarmMachine(): readState() gibt bei UART-Timeout -1 zurück – mit < 1 wurde fälschlich Alarm-Abbruch ausgelöst während webLogTask auf Serial2 zugreift |
| 9v4 | Qualität | SysConf bleibt bei 9v3-Stand – keine Konstanten-Änderungen in 9v4 |
| 9v4 | Bugfix | KRITISCH: vTaskDelay(1ms) unter playerMutex im S1-Handler (inputTask) – Mutex sofort freigeben, dann vTaskDelay(), dann neu nehmen (analog Fix 8v0 in alarmTask) |
| 9v4 | Bugfix | webLogMutex-Initialisierung vor ersten webLogf()-Aufrufen in setup() verschoben – setup()-Meldungen gingen bisher verloren |
| 9v4 | Qualität | webLogReady-Flag entfernt (toter Code – Deklaration und Zuweisung) |
| 9v4 | Qualität | WEB.h Footer-Versionsstring 4v0 → 9v4 korrigiert |
| 9v4 | Qualität | Web-Log-Seitentitel 9v3 → 9v4, TWDT-Kommentar 9v3 → 9v4 korrigiert |
| 9v5 | Bugfix | esp_task_wdt_init() → esp_task_wdt_reconfigure(): TWDT ist beim Arduino-Start bereits initialisiert – Doppel-Init vermieden, alle drei Parameter (timeout_ms, idle_core_mask=0, trigger_panic=true) werden korrekt übernommen |
| 9v5 | Qualität | Alle internen 9v4-Referenzen in .ino und SysConf ersetzt; WEB.h Footer-Version aktualisiert |
| 9v6 | Funktion | FW_VERSION-Makro eingeführt – Versionsnummer zentral in SysConf_9v6.h definiert, nicht mehr verteilt im Code |
| 9v6 | Funktion | Auto-Rückkehr zu UI_CLOCK jetzt auch von UI_INFO (Seite 7) – bisher war UI_INFO ausgenommen |
| 9v6 | Bugfix | Web-Log Versionsstring korrigiert; mp3Count-Clamp auf gültigen Bereich ergänzt |
| 9v6 | Qualität | PGMInfo und WEB.h Footer auf bTn_Alarm_9v6 aktualisiert; Kommentare korrigiert |
| 9v7 | Bugfix | EVT_S3 aktualisiert lastTouchMs – ohne Fix wurde nach S3 (Info-Toggle) die Auto-Rückkehr-Zeit nicht zurückgesetzt, Seite kehrte zu früh zurück |
| 9v8 | Qualität | bTn_Alarm_ → bTn_Wecker_ in PGMInfo, Kommentaren und WEB.h-Footer – konsistente Projektbezeichnung |
| 9v8 | Funktion | Web-Log: Reihenfolge der Sektionen – Allg. Log zuerst, dann Touch-Baseline, zuletzt Stack-HWM |
| 9v8 | Funktion | Web-Log: Allg. Log-Titel zeigt NTP-Sync-Zeitstempel nach Reset |
| 9v8 | Qualität | Web-Log: Schriftgröße 13 → 19 px; Zeilen nicht umbrechen (overflow-x: auto) |
| 9v8 | Qualität | Web-Log: Auto-Refresh 10 → 20 s |
| 9v9 | Qualität | Web-Log: Schriftgröße der Überschriften vergrößert (h2 → 1.6 rem, h3/.sec-title/.snap-title → 1 rem) |
| 9v10 | Bugfix | DFPlayer Start-Sound: readFileCounts() wird vor playFolder() aufgerufen – verhindert Abspielversuch bevor Dateianzahl bekannt ist |
| 9v11 | Qualität | Stack-Vorgaben reduziert: wifiTask/nvrTask/inputTask/displayTask 2560, watchdogTask 1536 – basierend auf gemessenen High-Water Marks |
| 9v12 | Bugfix | Bugfixes aus Code-Review (kritische Issues) |
| 9v13 | Bugfix | Mittlere Issues aus Code-Review behoben |
| 9v14 | Qualität | Wartungsqualität: Kosmetik aus Code-Review (Kommentare, Formatierung, Namensgebung) |
| 9v14 | Qualität | Versionsangaben in allen Dateien auf 9v14 synchronisiert |

## Versionen 9v15 – 10v06

| Version | Kategorie | Änderung |
|---|---|---|
| 9v15 | Qualität | UI: Checkboxen von 7×7 auf 8×8 vergrößert; Checked-Darstellung als Rahmen (drawRect 8×8) plus innere Füllung (fillRect 6×6) |
| 9v16 | Stabilität | DFPlayer-Kaltstart robuster: player.begin() in Retry-Schleife mit DFP_INIT_TIMEOUT_MS / DFP_INIT_RETRY_MS; SETUP_MP3_TIMEOUT_MS 5000 → 10000 ms |
| 9v17 | Qualität | UI: Checkbox-Rahmen von 1 px auf 2 px verdickt (zwei verschachtelte drawRect); alle Checkboxen um 1 px nach oben verschoben |
| 9v18 | Qualität | UI: Checkboxen auf 10×10 vergrößert (2 px Rahmen + 1 px Abstand + 4×4 Füllung); Checkboxen auf Seite Funktion um 2 px nach links verschoben |
| 10v00 | Funktion | Display-Abschaltung nach 10 min ohne Touch (DISPLAY_TIMEOUT_MS); Berührung eines beliebigen Touchpads weckt Display wieder für 10 min, das auslösende Touch-Event wird verworfen; Checkbox-Rahmen vereinfacht (nur äußerer 10×10 drawRect) |
| 10v01 | Qualität | DFPlayer-Init: 9v16-Retry-Logik zurückgenommen (player.begin() wieder einmaliger Aufruf); DFP_INIT_TIMEOUT_MS / DFP_INIT_RETRY_MS entfernt; SETUP_MP3_TIMEOUT_MS 10000 → 5000 ms |
| 10v02 | Qualität | Display-Ein-Zeit DISPLAY_TIMEOUT_MS von 10 min auf 5 min reduziert |
| 10v03 | Funktion | Display wird bei Alarm-Start automatisch eingeschaltet (analog Touch-Wake); Helper wakeDisplay() in alarmTask |
| 10v04 | Qualität | Web-Log: Zeile „[Reset] Anzahl: N" → „[RESET] resetCount: N" (einheitlicher Stil) |
| 10v05 | Stabilität | DFPlayer TX-Pin (GPIO17) vor Serial2.begin() 3 s LOW halten – verhindert Fehlinterpretation der ersten UART-Bytes beim Kaltstart |
| 10v06 | Bugfix | wakeDisplay(): TOCTOU und Race auf lastTouchMs behoben (displayBlanked-Check und lastTouchMs=millis() atomar unter displayMutex); lastTouchMs als volatile deklariert (Cross-Core-Sichtbarkeit) |

## Version 11v00

| Version | Kategorie | Änderung |
|---|---|---|
| 11v00 | Stabilität | NVR-Flash-Wear-Schutz: nvrSemaphore wird erst nach NVR_COMMIT_DELAY_MS (2 s) Ruhezeit ohne weiteres Event freigegeben; verhindert Flash-Writes bei gehaltener Einstelltaste im Touch-REPEAT-Modus |
| 11v00 | Bugfix | wifiTask Double-Buffer Race: snprintf in datum_WiFi_tmp/zeit_WiFi_tmp nur wenn kein altes Paar pending (wifiSyncPending-Guard); schließt Torn-Read-Fenster gegen displayTask |
| 11v00 | Qualität | Log-Regel: Serial.printf mit Web-Log-URL bleibt bewusst nach WiFi-Connect im Serial-Monitor – die URL steht sonst nur im Web-Log selbst und wäre unerreichbar |

## Version 11v01

| Version | Kategorie | Änderung |
|---|---|---|
| 11v01 | Funktion | Web-Log: neue Rubrik „Status – Letzter Start" zeigt die Zeilen WiFi und NTP analog zur Info-Seite (datum_WiFi/zeit_WiFi, datum_sync/zeit_sync); platziert oberhalb der Touch-Baseline-Sektion |

## Version 11v02

| Version | Kategorie | Änderung |
|---|---|---|
| 11v02 | Stabilität | inputTask: S3 wird bei `displayBlanked` zum reinen Wake+Discard-Event (analog T0–T4). Verhindert, dass ein blind gedrückter Taster auf der dunklen Info-Seite den Info-Toggle oder nachfolgende T0/T4-Touches (WLAN-Reset / Werksreset) versehentlich auslöst |
| 11v02 | Funktion | UI_INFO: WiFi-/NTP-Zeilen entfernt, stattdessen explizite Warnhinweise „T0: WLAN RESET SSID PW" und „T4: WERKSRESET" angezeigt – gefährliche Aktionen werden dem Nutzer direkt benannt |
| 11v02 | Funktion | Web-Log: Rubrik „Status – Letzter Start" umbenannt in „Verbindung – letzter WiFi Reconnect / NTP Sync" und unter die Ring-Puffer-Sektion verschoben |
| 11v02 | Qualität | UI_INFO-Zeile T0 von „WLAN RESET SSID PW" auf „RESET SSID PW" gekürzt (besserer Zeilenfit auf 128 px OLED) |

## Version 11v03

| Version | Kategorie | Änderung |
|---|---|---|
| 11v03 | Bugfix | resetCount zeigte nach Werksreset 2 statt 1: `bumpResetCount()` in `setup()` wurde vor `loadWifiCredentials()` aufgerufen – Konfigurator-Boot nach NVS-Erase zählte ebenfalls mit. Aufruf jetzt hinter `loadWifiCredentials()`; `bumpResetCount()` öffnet NVR-Namespace selbst (begin/end). |

## Version 11v04

| Version | Kategorie | Änderung |
|---|---|---|
| 11v04 | Funktion | S3 bei dunklem Display: Display einschalten UND Info-Seite öffnen (vorher seit 11v02 reines Wake+Discard). Implementiert in `inputTask` – Wake-Pfad für EVT_S3 setzt kein `continue`, Event fließt weiter zu `uiDispatch()`. Auto-Return (20 s) garantiert deterministisches Landen auf UI_INFO. Touch T0–T4 bleiben Wake+Discard (Reset-Schutz). |

## Version 11v05

| Version | Kategorie | Änderung |
|---|---|---|
| 11v05 | Funktion | UI_INFO: WLAN-Reset von T0 auf T3 verlegt – einheitliche Bedienung „Taste +" (T3) und „Taste –" (T4) analog zur Kuckuck-Seite. `onInfo()` reagiert jetzt auf EVT_T3 statt EVT_T0; EVT_T4 (Werksreset) unverändert. Der bestehende `s != UI_INFO`-Guard für T0 in `uiDispatch()` bleibt als Out-of-Bounds-Schutz für `cycle[]` (UI_INFO=7 wäre sonst außerhalb des 7-Einträge-Arrays) – T0 auf INFO ist seit 11v05 ohne Funktion. |
| 11v05 | Funktion | UI_INFO-Layout neu: Z1 Firmware-Kennung, Z2 Web-Log-Adresse (vorher Z5), Z3 MP3-/Reset-Zähler (vorher Z4), Z4 „Taste +  WiFi Reset", Z5 „ Taste –  Full Reset". Die früheren Hinweiszeilen „T0: RESET SSID PW" und „T4: WERKSRESET" (seit 11v02) entfallen zugunsten der symmetrischen +/–-Darstellung. |
| 11v05 | Qualität | Wake-Discard-Kommentar (`inputTask` bei `displayBlanked`) auf T3/T4 als gefährliche Aktionen angepasst. State-Machine-Diagramm, `runWifiConfigServer()`-Kommentar und `setup()`-Block-Kommentar zur WiFi-Konfig-Anforderung auf T3 nachgezogen. |

## Version 12v00

| Version | Kategorie | Änderung |
|---|---|---|
| 12v00 | Funktion | Hardware-Erweiterung „Motor + LED-Streifen": E2 (GPIO26, Wasserrad-Motor) wird statt digital jetzt per PWM über LEDC angesteuert – 20 kHz / 8 Bit / 60 % Duty (`MOTOR_PWM_DUTY`=153) treibt den 3-V-Motor an 5 V mit Mittelwert ~3 V ohne hörbares Schaltgeräusch. Ansteuerung in `alarmTask` und am S2-Zugschalter auf `ledcWrite(E2, …)` umgestellt. |
| 12v00 | Funktion | Neue zentrale Konstanten `MOTOR_PWM_FREQ` / `MOTOR_PWM_RES` / `MOTOR_PWM_DUTY` in SysConf (analog zu den `STACK_*`-Konstanten). |
| 12v00 | Refactoring | `pinMode(E2, OUTPUT)` in `setup()` entfällt – `ledcAttach()` übernimmt die Pinkonfiguration. E3 (GPIO27, LED-Streifen) bleibt `digitalWrite(HIGH/LOW)` (ohmsche Last mit 47 Ω Vorwiderstand, kein PWM erforderlich). |

## Version 12v01

| Version | Kategorie | Änderung |
|---|---|---|
| 12v01 | Qualität | Stack-Größen neu vorgegeben (Bytes): touchTask 2880, wifiTask 2000, nvrTask 2304, inputTask 2240, displayTask 2176, alarmTask 2128, watchdogTask 1344, stackMonTask 2912. webLogTask (4096) unverändert. Werte direkt als `STACK_*`-Konstanten in SysConf gesetzt; `setup()` übernimmt sie ohne weitere Codeänderung. |

## Version 12v02

| Version | Kategorie | Änderung |
|---|---|---|
| 12v02 | Funktion | Max. Einschaltzeit Licht/Mühlrad (Zugschalter S2) auf 30 min begrenzt – analog Auto-Rückkehr der Menü-Seiten. Neue Konstante `S2_TIMEOUT_MS` (1800000 ms). `displayTask` schaltet E2 (Motor-PWM) und E3 (Licht) nach Ablauf ab und setzt `S2_SW` zurück; Zeitstempel `t_start_S2` wird im S2-Handler beim Einschalten gesetzt. |
| 12v02 | Qualität | Web-Log „Allgemeines Log": `[xxx]`-Tag wird mit Leerzeichen auf feste Breite `WEBLOG_TAG_WIDTH` (12 Zeichen) aufgefüllt, damit der Text dahinter immer in derselben Spalte beginnt. |

## Version 12v03

| Version | Kategorie | Änderung |
|---|---|---|
| 12v03 | Funktion | Mühlrad-Motor-Pulsweite (Drehzahl) zur Laufzeit über Web-Slider verstellbar: Web-Log-Server erhält `GET /motor?duty=NN` (0–100 %) und einen Slider auf der Seite. `MOTOR_PWM_DUTY` ist nur noch der Default-Sollwert beim ersten Boot; der wirksame Wert liegt in der Laufzeit-Variable `motor_duty` (0–255) und wird in NVS persistiert (Schlüssel `motor_duty`). Live-Übernahme falls der Motor gerade läuft. |
| 12v03 | Funktion | Kickstart: liegt der Sollwert unter `MOTOR_PWM_KICK_THRESHOLD` (~35 % Duty), läuft der 3-V-Motor evtl. nicht aus dem Stand an → kurzer Vollgas-Anlaufimpuls (`MOTOR_PWM_KICK_DUTY` für `MOTOR_PWM_KICK_MS`), dann Sollwert. Neue zentrale Konstanten `MOTOR_PWM_KICK_THRESHOLD` / `_KICK_DUTY` / `_KICK_MS`. |
| 12v03 | Refactoring | Zentrale Helfer `motorStart()` / `motorStop()` ersetzen die verstreuten `ledcWrite(E2, …)`-Aufrufe in `runAlarmMachine`, am S2-Zugschalter und beim S2-Timeout. Persistenz über die bestehende `safeChange`→`nvrSemaphore`→`nvrTask`-Kette (kein Flash-Zugriff im HTTP-Handler). |

## Version 12v04

| Version | Kategorie | Änderung |
|---|---|---|
| 12v04 | Bugfix | Web-Log „Allgemeines Log – letzter Reset" zeigte nach einem Stromausfall kein Datum/keine Uhrzeit mehr (nur „–"), während der Reset-Zähler korrekt um 1 hochzählte. Ursache: Der Zeitstempel `snapNtpTime` wird nur in `setup()` nach erfolgreicher NTP-Synchronisation gesetzt; bootet der ESP32 nach Stromausfall schneller als der Router, scheitert die WLAN-Verbindung beim Start und der gesamte NTP-Block (inkl. Befüllung von `snapNtpTime`) wird übersprungen. `displayTask` trägt den Reset-Zeitstempel nun beim ersten NTP-Sync nach dem Boot nach (über `ntpSyncPending`) und rekonstruiert den tatsächlichen Reset-Zeitpunkt aus aktueller Zeit minus Uptime (`millis()`). Der Reset-Zähler war nie betroffen (NVS, unabhängig von WLAN/NTP). |

## Version 12v05

| Version | Kategorie | Änderung |
|---|---|---|
| 12v05 | Stabilität | DFPlayer Start-Check: Neue Funktion `verifyPlayStarted()` fragt direkt nach `player.playFolder()` (Alarm 1 + Alarm 2 in `runAlarmMachine`) per `readState()`-Doppel-Poll (analog `ALARM_RUNNING`) ab, ob der DFPlayer den Play-Befehl tatsächlich angenommen hat. Bisher wurde weder der ACK-Modus aus `player.begin()` noch der Player-Status nach dem Play-Befehl ausgewertet – ein nicht reagierender DFPlayer (Kabel ab, Modul defekt, SD-Karte fehlt) blieb unbemerkt, und der Alarm (Motor/Licht) lief mangels Zeitbegrenzung in `ALARM_RUNNING` potenziell unbegrenzt weiter. Bei `st<=0` (0=idle, -1=UART-Timeout) jetzt `webLogf()`-Fehlermeldung mit Alarm-Label und Dateinummer. |
| 12v05 | Stabilität | DFPlayer-Absturzerkennung: Bestätigt `verifyPlayStarted()` den Play-Befehl nicht, gilt der DFPlayer als abgestürzt – die neue Funktion `triggerAlarm()` (löst jetzt beide Alarme aus, ersetzt den bisherigen Inline-Code in `runAlarmMachine`) löst dann unmittelbar `ESP.restart()` aus (einzige verlässliche Wiederherstellung für ein hängendes DFPlayer/UART). |
| 12v05 | Stabilität | Verpasster-Alarm-Retry nach Absturz-Neustart: `triggerAlarm()` hinterlegt Alarmnummer, Dateinummer und Minute in `RTC_NOINIT_ATTR`-Variablen (`rtcRetryMagic`/`-Alarm`/`-FileNo`/`-Min`), bevor es `ESP.restart()` auslöst – diese überstehen den Software-Reset. `setup()` prüft `rtcRetryMagic` nach der DFPlayer-Initialisierung und ruft `triggerAlarm()` mit den gemerkten Werten erneut auf, sodass der durch den Absturz verpasste Alarm nach dem Neustart doch noch abgespielt wird. |

## Version 12v06

| Version | Kategorie | Änderung |
|---|---|---|
| 12v06 | Bugfix | DFPlayer Start-Check löste Fehlalarm-Neustarts aus, obwohl der DFPlayer korrekt spielte: `verifyPlayStarted()` fragte `readState()` bisher nur 1 ms nach `player.playFolder()` ab – der DFPlayer braucht nach dem Play-Befehl jedoch Zeit, um die Datei von der SD-Karte zu laden und den Status auf „playing" zu setzen, sodass die Abfrage noch den alten Zustand (`st<=0`) auslas und `ESP.restart()` fälschlich ausgelöst wurde. `verifyPlayStarted()` wartet jetzt vor jeder Abfrage `VERIFY_PLAY_DELAY_MS` (500 ms) und erlaubt bis zu `VERIFY_PLAY_RETRIES` (3) Versuche – bei anhaltendem `st<=0` steht das Ergebnis spätestens nach 1500 ms fest, bevor der Neustart folgt. |

## Version 12v07

| Version | Kategorie | Änderung |
|---|---|---|
| 12v07 | Stabilität | DFPlayer-Absturz-Neustart war unbegrenzt: Reagierte der DFPlayer dauerhaft nicht (z. B. Kabel ab, Modul defekt), löste `triggerAlarm()` bei jedem Fehlversuch erneut `ESP.restart()` aus – der ESP32 startete potenziell endlos neu. Neuer Parameter `failCount` in `triggerAlarm()` sowie `RTC_NOINIT_ATTR`-Zähler `rtcRetryCount` (übersteht `ESP.restart()` wie die bestehenden `rtcRetry*`-Variablen) zählen die Fehlversuche über die Neustarts hinweg mit. |
| 12v07 | Stabilität | Neue Konstante `ALARM_MAX_RESTARTS` (10) in SysConf begrenzt die Anzahl der Versuche: Ab dem 10. erfolglosen Versuch löst `triggerAlarm()` keinen weiteren `ESP.restart()` mehr aus, sondern bricht den Alarm für diesen Tag endgültig ab (Motor/Licht bleiben aus, `rtcRetryMagic` wird gelöscht). Am nächsten Tag wird der Alarm zur regulären Zeit wieder frisch versucht (`failCount` startet dann bei 0). |
| 12v07 | Funktion | Neuer Fehlereintrag im Web-Log beim endgültigen Abbruch: `webLogf()` schreibt eine `[FEHLER]`-Zeile mit Alarm-Label, Dateinummer, Versuchsanzahl und Datum/Uhrzeit (`snapTimeStr()`). Die Log-Seite (`webLogTask()`) färbt Zeilen mit `[FEHLER]`-Tag rot (analog `[WATCHDOG]`/`[PANIC]`). |

## Version 12v08

| Version | Kategorie | Änderung |
|---|---|---|
| 12v08 | Funktion | Web-Log neu organisiert: DFPlayer-Meldungen (alle Zeilen mit „DFPlayer" im Text) erscheinen jetzt in einem eigenen Abschnitt `#dflog` statt im „Allgemeinen Log". Titel lautet „DFPlayer – letzter erfolgreicher Alarm: *&lt;Zeitstempel&gt;*" – neuer Snapshot `snapAlarmTime` wird in `triggerAlarm()` direkt nach erfolgreichem `playFolder()` gesetzt (analog `snapTouchTime`/`snapStackTime`). |
| 12v08 | Funktion | Neue Funktion `checkSerial2Leftover(label)` prüft vor jedem an den DFPlayer gesendeten Kommando `Serial2.available()`. Sind noch Bytes im Empfangspuffer (Hinweis auf verspätete/verlorene Antworten bzw. UART-Desync), schreibt `webLogf()` eine `[DFPlayer]`-Zeile mit Kommando-Label, Byteanzahl, Zeitstempel und einem seit Boot mitlaufenden Zähler `serial2LeftoverCount`. Wird vor allen `player.*()`-Aufrufen aufgerufen, die ein Kommando an den DFPlayer senden. |

## Version 12v09

| Version | Kategorie | Änderung |
|---|---|---|
| 12v09 | Bugfix | DFPlayer Serial2-Puffer-Desync behoben: Logauswertung vom 10.08.2026 zeigte konstant 20 Byte (2 Frames) Rückstand vor `readState()`-Aufrufen im ALARM_RUNNING-Poll. Ursache: `DFRobotDFPlayerMini::available()` verarbeitet pro Aufruf nur einen vollständigen 10-Byte-Frame und kehrt danach sofort zurück, selbst wenn im Puffer bereits weitere vollständige Frames warten (z. B. das interne 0x41-ACK zusätzlich zur eigentlichen Feedback-Antwort im ACK-Modus). `verifyPlayStarted()` las dadurch nach `triggerAlarm()` teils einen veralteten Frame statt der aktuellen Antwort auf den gerade gesendeten `playFolder`-Befehl. |
| 12v09 | Bugfix | Neue Funktion `readStateDrained()` liest bei jedem Aufruf so lange weiter, bis kein vollständiger 10-Byte-Frame mehr im Puffer steht, und wertet nur den zuletzt empfangenen Feedback-Wert als aktuellen Status (ältere Frames werden verworfen). Ersetzt `player.readState()` an allen Aufrufstellen (`verifyPlayStarted()`, ALARM_RUNNING-Poll, S1-Handler). Beseitigt den Rückstand strukturell statt nur punktuell vor dem Alarm. |
| 12v09 | Stabilität | `triggerAlarm()` verwirft unmittelbar vor `playFolder()` alle noch im Serial2-Puffer stehenden Bytes (`while(Serial2.available()) Serial2.read();`) – `verifyPlayStarted()` sieht dadurch garantiert nur die Antwort auf den gerade gesendeten Befehl. Nicht blockierend, daher unkritisch auch unter gehaltenem `playerMutex`. |

## Version 12v10

| Version | Kategorie | Änderung |
|---|---|---|
| 12v10 | Funktion | `ALARM_MAX_RESTARTS` 10 → 3: reagiert der DFPlayer nach einem Alarm-Start dauerhaft nicht (Kabel ab, Modul defekt, SD-Karte fehlt), bricht `triggerAlarm()` jetzt schon nach 3 statt 10 `ESP.restart()`-Versuchen endgültig ab (Motor/Licht bleiben aus, roter `[FEHLER]`-Eintrag im Web-Log). |

## Version 12v11

| Version | Kategorie | Änderung |
|---|---|---|
| 12v11 | Bugfix | Reboot statt Alarm ohne Ersatzalarm behoben: Der in 12v09 eingeführte Puffer-Drain in `triggerAlarm()` (`while(Serial2.available()) Serial2.read();`) hatte keine Obergrenze. Bei getrenntem/defektem DFPlayer kann die floatende RX-Leitung (GPIO16) dauerhaft Rauschen liefern – `Serial2.available()` wird dann nie 0, die Schleife lief endlos und hielt dabei `playerMutex`. `alarmTask` aktualisierte dadurch `wdg_alarmTask` nicht mehr; `watchdogTask` erkannte nach `WDG_TIMEOUT_MS` (30 s) einen Task-Freeze und rief `ESP.restart()` auf – ohne `rtcRetryMagic` zu setzen, da dieser Pfad unabhängig vom regulären DFPlayer-Absturz-Neustart in `triggerAlarm()` ist. Ergebnis: Reboot, aber kein Ersatzalarm nach dem Neustart. |
| 12v11 | Bugfix | Neue Konstante `SERIAL2_DRAIN_MAX_BYTES` (200) begrenzt sowohl den Drain in `triggerAlarm()` als auch die Drain-Schleife in `readStateDrained()` (12v09) auf eine feste Obergrenze – beide Schleifen terminieren jetzt garantiert, auch bei dauerhaftem UART-Rauschen. |

## Version 12v12

| Version | Kategorie | Änderung |
|---|---|---|
| 12v12 | Stabilität | `watchdogTask` als zusätzlicher Fallback für `rtcRetryMagic`: Fror `alarmTask` während eines laufenden `triggerAlarm()`-Versuchs ein (egal aus welchem Grund), fand bisher kein Ersatzalarm-Retry nach dem `watchdogTask`-Neustart statt – dieser Pfad war komplett unabhängig vom regulären DFPlayer-Absturz-Retry in `triggerAlarm()` selbst. Neuer In-Flight-Marker `alarmTriggerInFlight` (+ Snapshot `alarmTriggerNum`/`-FileNo`/`-Min`/`-FailCount`) wird zu Beginn des riskanten Abschnitts in `triggerAlarm()` gesetzt und nach jedem Ausgang (Erfolg, regulärer Retry, endgültiger Abbruch) wieder gelöscht. |
| 12v12 | Stabilität | `watchdogTask` prüft bei einem `alarmTask`-Freeze gezielt diesen Marker (nicht bei input-/displayTask-Freezes, die stehen in keinem Zusammenhang mit einem laufenden Alarm) und setzt vor dem eigenen `ESP.restart()` ebenfalls `rtcRetryMagic`, sodass `setup()` den Alarm nach dem Neustart genauso erneut auslöst wie beim regulären Retry-Pfad. |

## Version 12v13

| Version | Kategorie | Änderung |
|---|---|---|
| 12v13 | Bugfix | Root Cause des 12v12-Vorfalls gefunden (Reboot ohne Ersatzalarm trotz 12v11/12v12-Fixes): Hardware-TWDT-Backtrace zeigte den Hang in `triggerAlarm()` → `player.playFolder()` → `sendStack()` → `waitAvailable()` → `DFRobotDFPlayerMini::available()`. Die innere `while(_serial->available())`-Schleife dieser Bibliotheksfunktion hatte im Original keine Zeitbegrenzung – bei anhaltendem Byte-Zustrom (floatende/gestörte RX-Leitung bei getrenntem/defektem DFPlayer) blockierte sie unbegrenzt, noch bevor `waitAvailable()` seinen eigenen 500-ms-Timeout prüfen konnte. Erklärt auch `CPU 1: IDLE1` im TWDT-Log: echter Systemstillstand, kein reiner `alarmTask`-Hänger. Die 12v09–12v12-Fixes griffen nicht, weil der Hänger bereits innerhalb der Bibliothek passierte. |
| 12v13 | Bugfix | Fix direkt in `DFRobotDFPlayerMini.cpp` (lokale Installation `D:\Arduino\libraries\DFRobotDFPlayerMini\`, außerhalb dieses Repos): `available()` bricht jetzt nach 100 ms auch bei anhaltendem Byte-Zustrom ab, `_receivedIndex` bleibt für den nächsten Aufruf erhalten. Muss nach jeder Neuinstallation der Bibliothek erneut angewendet werden – dokumentiert in `Software/Bibliotheken/README.md`. Kein Code in der Firmware selbst geändert, Version nur für Nachvollziehbarkeit auf dem Gerät hochgezählt. |

## Version 12v14

| Version | Kategorie | Änderung |
|---|---|---|
| 12v14 | Bugfix | 12v13-Diagnose widerlegt und Bibliotheks-Patch zurückgenommen: Hardware wurde mit 12v08 als voll funktionsfähig verifiziert – dort existierte weder Patch noch Bibliotheksänderung, der Hang war also firmwareseitig verursacht, nicht in `DFRobotDFPlayerMini::available()` selbst. `DFRobotDFPlayerMini.cpp` bleibt jetzt unverändert im Originalzustand. |
| 12v14 | Bugfix | Root Cause tatsächlich gefunden: Der in 12v11 eingeführte Puffer-Drain in `triggerAlarm()` vor `player.playFolder()` las rohe Bytes direkt per `Serial2.read()` – vorbei an `DFRobotDFPlayerMini`s eigenem Frame-Parser. Riss dieser Discard mitten in einem noch eintreffenden Frame ab (z.B. verspätete Antwort auf das vorherige Kommando), desynchronisierte er `_receivedIndex`/`_isSending` der Bibliothek und erzeugte dadurch genau das anhaltende Byte-Durcheinander auf der UART, das dann in `available()` zum 15-Sekunden-TWDT-Hänger führte – ein in 12v08 unmögliches Szenario, da dort kein roher Drain existierte. |
| 12v14 | Bugfix | Fix: Drain in `triggerAlarm()` läuft jetzt über `player.available()`/`player.read()` statt über rohe Bytes (gleiches Muster wie `readStateDrained()`, 12v09/12v11) – hält den Puffer sauber, ohne den Parser-Zustand der Bibliothek zu zerstören. |

## Version 12v15

| Version | Kategorie | Änderung |
|---|---|---|
| 12v15 | Bugfix | Laufzeitfehler `E (…) task_wdt: esp_task_wdt_reset(707): task not found` behoben: `esp_task_wdt_reconfigure()` setzt laut ESP-IDF ein bereits initialisiertes TWDT voraus, wurde in `setup()` aber erst **nach** dem Start von `inputTask`/`displayTask`/`alarmTask` aufgerufen. Die Annahme „Core 3.x initialisiert das TWDT bereits beim Boot" traf hier nicht zu (oder war zeitlich nicht garantiert vor dem ersten `esp_task_wdt_add()` der neu erzeugten Tasks) – die Anmeldung lief ins Leere, jeder folgende `esp_task_wdt_reset()` brach ab. Damit hätte ein echter Task-Hang nie einen Hardware-Watchdog-Reset ausgelöst, das TWDT überwachte de facto nichts. |
| 12v15 | Bugfix | Fix: `esp_task_wdt_init()` wird jetzt **vor** dem Start der FreeRTOS-Tasks aufgerufen; ist das TWDT bereits initialisiert (`ESP_ERR_INVALID_STATE`), erfolgt stattdessen `esp_task_wdt_reconfigure()`. `esp_task_wdt_add()` in den Task-Funktionen trifft dadurch garantiert auf ein existierendes TWDT. |

## Version 12v16

| Version | Kategorie | Änderung |
|---|---|---|
| 12v16 | Bugfix | Laufzeitfehler `E (…) task_wdt: esp_task_wdt_init(517): TWDT already initialized` behoben: Der 12v15-Fix rief `esp_task_wdt_init()` blind auf und fing nur den Rückgabewert `ESP_ERR_INVALID_STATE` ab – die Bibliotheksfunktion loggt den Fehler aber unabhängig davon per `ESP_LOGE()` selbst, sobald das TWDT (wie sich auf dieser Hardware zeigte) bereits vom Boot-Vorgang existiert. Damit war die ursprüngliche Annahme „Core 3.x initialisiert das TWDT bereits beim Boot" korrekt – das eigentliche 12v14/12v15-Problem lag ausschließlich in der Reihenfolge relativ zum Task-Start, nicht im Fehlen der Initialisierung. |
| 12v16 | Bugfix | Fix: `esp_task_wdt_status(NULL)` fragt jetzt vorher ab, ob das TWDT existiert (`ESP_ERR_INVALID_STATE` = noch nicht initialisiert) – nur dann `esp_task_wdt_init()`, andernfalls weiterhin nur `esp_task_wdt_reconfigure()`. Kein `ESP_LOGE`-Seiteneffekt mehr bei jedem Boot. |

## Version 12v17

| Version | Kategorie | Änderung |
|---|---|---|
| 12v17 | Qualität | Web-Log-Rauschen reduziert: `checkSerial2Leftover()` meldete bisher bei jeder DFPlayer-Abfrage mit Restbytes eine eigene `[DFPlayer]`-Zeile, auch wenn die Byteanzahl über viele Aufrufe hinweg unverändert blieb (z.B. bei dauerhaftem UART-Rauschen). Neue statische `serial2LeftoverLastLogged` merkt sich den zuletzt gemeldeten Wert; `webLogf()` schreibt jetzt nur noch, wenn sich die Restbyte-Anzahl gegenüber der letzten Meldung ändert. `serial2LeftoverCount` (der „seit Boot"-Wert in der Log-Zeile) zählt weiterhin jede Abfrage mit Restbytes, unabhängig vom Log. |

## Version 12v18

| Version | Kategorie | Änderung |
|---|---|---|
| 12v18 | Bugfix | 12v17-Fix griff während `ALARM_RUNNING` nicht: `checkSerial2Leftover()` setzte `serial2LeftoverLastLogged` bei `avail==0` auf 0 zurück – der Puffer wird aber zwischen den beiden `readState`-Abfragen pro Poll-Zyklus durch `readStateDrained()` leergezogen, sodass derselbe wiederkehrende Restbyte-Wert (Poll → Restbytes → auf 0 gedraint → nächster Poll dieselbe Anzahl) bei jedem Zyklus erneut als „neue" Änderung gewertet und geloggt wurde. |
| 12v18 | Bugfix | Fix: Der zuletzt gemeldete Wert bleibt jetzt über Nullstände hinweg erhalten (Startwert `-1` statt `0`, kein Reset mehr im `avail==0`-Zweig) – nur ein tatsächlich anderer Restbyte-Wert löst noch eine neue Web-Log-Zeile aus. |

## Version 12v19

| Version | Kategorie | Änderung |
|---|---|---|
| 12v19 | Bugfix | Log-Analyse vom 10.08.2026 zeigte trotz 12v09–12v18-Fixes weiterhin wiederkehrende Restbytes von 20–30 (2–3 Frames) sowie einen erneuten `verifyPlayStarted()`-Fehlschlag (Versuch 1/3, st=-1). Ursache: Der Vorab-Drain aus 12v14 lief nur unmittelbar vor dem alarmspezifischen `playFolder()` in `triggerAlarm()`. `volume()`, `stop()` und die Testsound-`playFolder()`-Aufrufe (Sound1/Sound2 an/aus, Lautstärke +/−, Funktionswahl-Stop) sendeten dagegen ungedraint – dort entstehende Restframes (z.B. ACK je Befehl) blieben liegen, bis ein zufälliger späterer `readStateDrained()`-Aufruf sie mit abräumte, im ungünstigen Fall genau während der nächsten Alarm-Verifikation. |
| 12v19 | Bugfix | Fix: Inline-Drain aus `triggerAlarm()` in neue Funktion `drainSerial2Pre()` ausgelagert und zusätzlich vor allen `volume()`-, `stop()`- und Testsound-`playFolder()`-Aufrufen aufgerufen (`onClock()` Lautstärke +/−, `checkboxSound()` Sound1/Sound2 an/aus, Funktionswahl-Stop, S1-Stop). |

## Version 13v00

| Version | Kategorie | Änderung |
|---|---|---|
| 13v00 | Bugfix | Root Cause von `kein Start-Status nach playFolder` (st=-1) gefunden: `DFRobotDFPlayerMini::readState()` gibt bei JEDER Nicht-Feedback-Frame-Art (z.B. unaufgeforderter Play-Finished-Meldung 0x3C/0x3D vom vorherigen Titel) sofort -1 zurück, ohne weiter auf die tatsächliche Antwort zu warten. Der in 12v19 vermutete Zusammenhang mit dem ACK-Modus (0x41-Frame) traf **nicht** zu – `parseStack()` der Bibliothek verschluckt 0x41 bereits intern, unabhängig vom Fund, und setzt dabei nie `_isAvailable`. |
| 13v00 | Bugfix | Fix 1: `readStateDrained()` wartet nach einem `-1` von `readState()` noch bis zu `SERIAL2_FEEDBACK_GRACE_MS` (100 ms) lang aktiv auf einen echten Feedback-Frame (Timer wird bei jedem weiteren Störframe zurückgesetzt), statt sofort aufzugeben. |
| 13v00 | Qualität | Fix 2 (zurückgenommen, siehe unten): ACK-Modus deaktiviert (`player.begin(Serial2, false, true)`) – entfernt die blockierende Wartelogik in `sendStack()` der Bibliothek (wartet bei aktivem ACK vor jedem neuen Befehl auf das ACK des vorherigen). War nicht die Ursache des st=-1-Problems, aber unnötige Latenzquelle; der Erfolg eines Befehls wird ohnehin über die tatsächliche Statusabfrage verifiziert. |
| 13v00 | Refactoring | Nebeneffekt von Fix 2: `player.begin()` prüft ohne ACK nicht mehr auf Card-/USB-Online, liefert unbedingt `true` – das `if(player.begin(...)) {…} else { webLog("Verbindung fehlgeschlagen!"); }` in `setup()` war dadurch unreachable code. `else`-Zweig entfernt, `if` in unbedingten Ablauf aufgelöst; die Verbindungsprüfung übernimmt jetzt allein die bereits vorhandene `readFileCounts()`-Schleife mit `SETUP_MP3_TIMEOUT_MS`-Fallback ("Timeout – mp3Count unbekannt"). |
| 13v00 | Bugfix | Regression durch Fix 2 entdeckt: Startsound blieb nach Boot aus. Ursache: Ohne die ACK-Wartelogik sendet `sendStack()` `volume()`/`EQ()`/`playFolder()` (Startsound) in `setup()` nur noch mit einem pauschalen 10-ms-Delay hintereinander, statt auf die tatsächliche Verarbeitung des jeweils vorherigen Befehls zu warten – direkt nach `reset()` kam der DFPlayer damit nicht mehr mit, `playFolder(2, 1)` ging unterwegs verloren. |
| 13v00 | Bugfix | Fix 2 zurückgenommen: ACK-Modus bleibt aktiv (`player.begin(Serial2, true, true)`), `if/else`-Verbindungscheck in `setup()` wiederhergestellt. Der 0x41-ACK-Frame war ohnehin nie die Ursache des st=-1-Problems (siehe oben) – Fix 1 bleibt unverändert wirksam. |

Firmware 13v00 eingefroren, verknüpft mit Hardware 1v0 (kein BUSY-Signal).
Ab hier neue Basis Hardware 2v0 (DFPlayer-BUSY-Signal, GPIO34) / Firmware 20v00.

## Version 20v00

| Version | Kategorie | Änderung |
|---|---|---|
| 20v00 | Funktion | Basis 13v00, Hardware ab 2v0: `SysConf_20v00.h` – Pin-Konstante `DFPLAYER_BUSY` (GPIO34, DFPlayer BUSY-Pin) ergänzt. |
| 20v00 | Funktion | `pinMode(DFPLAYER_BUSY, INPUT)` in `setup()`; neue Hilfsfunktion `dfPlayerBusy()` (direkter GPIO-Read, LOW=Wiedergabe läuft) – zunächst ungenutzt bereitgestellt. |

## Version 20v01

| Version | Kategorie | Änderung |
|---|---|---|
| 20v01 | Stabilität | `runAlarmMachine()`/`ALARM_RUNNING`: `dfPlayerBusy()` löst den bisherigen "-1=UART-Timeout → Alarm läuft sicherheitshalber weiter"-Fallback ab. Serial2-Timeouts von `readStateDrained()` gelten jetzt nur noch als "MP3 beendet", wenn der BUSY-Pin (direktes Hardware-Signal, kein UART) das bestätigt. |

## Version 20v02

| Version | Kategorie | Änderung |
|---|---|---|
| 20v02 | Stabilität | `verifyPlayStarted()`: Erfolgskriterium von `st > 0` auf `st > 0 \|\| dfPlayerBusy()` erweitert – vermeidet einen unnötigen `ESP.restart()`, wenn der DFPlayer tatsächlich läuft, aber `readStateDrained()` (UART) trotz Gnadenfrist weiter `st<=0` liefert. |
| 20v02 | Stabilität | S1-Handling (`inputTask`): 200-ms-Timeout-Fallback bei anhaltendem `st==-1` fragt jetzt `dfPlayerBusy()` statt blind `st=0` ("idle") zu setzen – verhindert, dass bei einem UART-Timeout fälschlich der Kuckuck statt `stop()` ausgelöst wird, obwohl noch ein Alarm/Sound läuft. |

## Version 20v03

| Version | Kategorie | Änderung |
|---|---|---|
| 20v03 | Stabilität | QA-Review (Code-Review-Agent) identifizierte `dfPlayerBusy()` als ungefilterten Einzel-`digitalRead()` ohne Software-Debounce, anders als Touch-Pads/Taster. Für die einzige unwiderrufliche Entscheidungsstelle (`ALARM_RUNNING`: Motor/Licht aus, State-Reset bei jedem Poll) neue Funktion `dfPlayerIdleDebounced()` – 3 Abtastungen im Abstand von 5 ms müssen übereinstimmend "idle" melden, sonst gilt der Alarm als weiterhin laufend. Ergänzt den bereits vorhandenen Hardware-RC-Filter (100µs Zeitkonstante, siehe `Hardware/Schaltplan/DFPlayer-BUSY.md`) um Software-seitige Absicherung gegen Störimpulse, die den Filter überdauern. `verifyPlayStarted()` und S1-Handling bleiben bei einfachem `dfPlayerBusy()` (geringere Konsequenz eines Fehlreads: Retry-Schleife bzw. einmaliger Tastendruck). |

## Version 20v04

Audit-Reaktionsplan (`Dokumentation/Technisch/Review/AuditReaktionsplan.md`) Schritt 1: A1 + A5 gemeinsam umgesetzt, erledigt dabei A4 und A6 mit.

| Version | Kategorie | Änderung |
|---|---|---|
| 20v04 | Stabilität | Neue Funktion `timeValid()` (A5-Fix): `alarmTask` wertet Alarm- und Kuckuck-State-Machine nur noch bei gültiger Systemzeit (`time(nullptr) > 1700000000UL`) aus – verhindert Fehlalarme auf der ungestellten 1970-Uhr (Stromausfall ohne WLAN-Wiederverbindung). |
| 20v04 | Bugfix | `runAlarmMachine()`: Alarmfälligkeit von `sec==0`-Flanke auf tagesbezogene, pegelbasierte Prüfung (`alarmDue()`) mit Nachholfenster `ALARM_CATCHUP_MIN` (60 min, SysConf) umgestellt (A1). Fängt Zeitsprünge nach Stromausfall (NTP-Hardsync), Reboots im Alarmfenster und die März-Zeitumstellung ab, die zuvor den Alarm des Tages ersatzlos gelöscht haben. `lastA1Min`/`lastA2Min` durch `lastA1Day`/`lastA2Day` (tm_yday) ersetzt; die Sperre wird nach erfolgreichem Alarmstart bewusst bis Tagesende gehalten (auch nach manuellem Stopp über S1) statt wie bisher sofort wieder aufgehoben – vermeidet ein sofortiges Neuauslösen durch die pegelbasierte Prüfung. |
| 20v04 | Bugfix | `runAlarmMachine()`: Fälligkeitsprüfung läuft jetzt bei jedem 500-ms-Tick, nicht mehr nur exklusiv im `case ALARM_IDLE` zur exakten Sekunde – Alarm 2 wird dadurch nicht mehr übersprungen, wenn er während eines laufenden Alarm 1 fällig wird (A4), da die Prüfung beim Rückkehren nach `ALARM_IDLE` automatisch nachzieht. |
| 20v04 | Bugfix | `runCuckooMachine()`: Sperre von reiner Minute (`lastCuckooMin`) auf Tag+Stunde (`lastCuckooDay`/`lastCuckooHour`) umgestellt (A6) – verhindert einen doppelten Kuckuck bei der Oktober-Zeitumstellung, wenn die Ortszeit 02:00–02:59 zweimal durchläuft. Manueller Einmal-Kuckuck über S1 setzt dieselbe Sperre über einen eigenen `localtime_r()`-Schnappschuss. |
| 20v04 | Refactoring | `triggerAlarm()` setzt `lastA1Day`/`lastA2Day` über einen eigenen Zeitstempel statt des `min`-Parameters. Fehlgeschlagener `playerMutex`-Take beim Alarmversuch (A2) heilt sich dadurch im nächsten 500-ms-Tick automatisch aus, solange das Nachholfenster nicht abgelaufen ist – kein Codepfad mehr nötig, der den Fehlschlag gesondert behandelt. |

## Version 20v05

Audit-Reaktionsplan Schritt 2, Restarbeit A3 (C1 bereits seit 20v02 erledigt, siehe dort).

| Version | Kategorie | Änderung |
|---|---|---|
| 20v05 | Stabilität | Neue Konstante `ALARM_MAX_RUN_MS` (15 min, SysConf) und eigener Zeitstempel `alarmRunStart` (A3): harte Obergrenze für `ALARM_RUNNING` als Rückfallebene, falls der DFPlayer-BUSY-Pin selbst dauerhaft LOW hängt (Modul-Fehlfunktion, Leitungsfehler) und `dfPlayerIdleDebounced()` dadurch nie "idle" meldet – ohne diesen Deckel bliebe das Gerät in diesem Fall für immer entwaffnet (Motor/Licht dauerhaft an, kein weiterer Alarm möglich). Anders als `t_start6` (Poll-Timer, wird bei jedem Poll zurückgesetzt) bleibt `alarmRunStart` bis zum Alarmende unverändert. Bei Auslösung durch die Obergrenze (nicht durch reguläres Alarmende) schreibt `runAlarmMachine()` einen `[FEHLER]`-Eintrag mit Laufzeit und letztem `playerStatus` ins Web-Log. |

## Version 20v06

Audit-Reaktionsplan Schritt 3 (B2).

| Version | Kategorie | Änderung |
|---|---|---|
| 20v06 | Stabilität | `triggerAlarm()` schreibt den RTC-Retry-Merker (`rtcRetryMagic` u.a.) jetzt direkt nach dem `playerMutex`-Take, VOR `playFolder()`/`verifyPlayStarted()` – bisher wurde er nur im expliziten Fehlerpfad (bestätigter `ESP.restart()`) gesetzt. Ein Freeze/Reset irgendwo zwischen `playFolder()` und der ersten bestätigten Wiedergabe in `ALARM_RUNNING` (inkl. des `ALARM_POLL_MS`-Fensters vor dem ersten Poll) verlor den Alarm bisher ersatzlos, weil kein RTC-Merker existierte. Sicher erst durch den Tages-Guard aus A1 (20v04): ein später Reboot löst höchstens einen bereits gelaufenen Alarm erneut aus, nie einen verspäteten Zweitalarm (B2). |
| 20v06 | Stabilität | `runAlarmMachine()`/`ALARM_RUNNING` löscht den Merker an zwei Stellen: sobald der erste Poll `playerStatus > 0` bestätigt (frühestmöglich), und zusätzlich beim Alarmende (`mp3Finished`/`runTimeExceeded`) als Sicherheitsnetz für einen sehr kurzen Sound, der schon vor dem ersten Poll beendet war. |
| 20v06 | Refactoring | Der Fehlerpfad in `triggerAlarm()` (`ESP.restart()` nach gescheitertem `verifyPlayStarted()`) aktualisiert nur noch `rtcRetryCount` – die übrigen Felder sind bereits durch den frühen Schreibpunkt gesetzt. |

## Version 20v07

Audit-Reaktionsplan Schritt 4 (C5 + D1).

| Version | Kategorie | Änderung |
|---|---|---|
| 20v07 | Bugfix | `setup()`: Clamp von `sound1_assigned`/`sound2_assigned` läuft nur noch bei bekannter `mp3Count` (C5). Bei `mp3Count==0` (nach fehlgeschlagenem `player.begin()`) war die Clamp-Bedingung bisher immer wahr – `readNVR()` begrenzt die Zuordnung nur nach unten auf 1, nie nach oben – und überschrieb beide Sound-Zuordnungen mit 1. Verstellt der Nutzer danach irgendetwas, persistiert `markSafeChange()` diesen falschen Wert unwiederbringlich in NVS. Bei unbekannter Dateizahl jetzt `[FEHLER]`-Log statt stillem Überschreiben. |
| 20v07 | Bugfix | `data.begin()`-Rückgabewert wird jetzt an allen drei Stellen geprüft (D1): `setup()` (NVR-Laden), `nvrTask()` (periodischer Commit), `bumpResetCount()`. Schlägt das Öffnen fehl, liefen `putBool`/`putInt`-Aufrufe bisher als No-Op ins Leere – eine soeben geänderte Einstellung ging beim nächsten Stromausfall ersatzlos verloren, ohne Hinweis im Log. `nvrTask()` setzt bei Fehlschlag über `markSafeChange()` erneut `safeChange`, wodurch der Commit nach `NVR_COMMIT_DELAY_MS` automatisch wiederholt wird, statt endgültig verworfen zu werden. |
| 20v07 | Bugfix | `setup()`: `readNVR()` läuft jetzt unabhängig vom `state`-Flag (statt nur im `varState==true`-Zweig) – die `getX()`-Fallbacks liefern beim allerersten Boot ohnehin die Compile-Defaults zurück, ein bedingter Aufruf war unnötig und verdeckte zusätzlich den Fall „`data.begin()` schlägt fehl, `state` bleibt beim Default `false`". |
| 20v07 | Refactoring | `webLogMutex`-Initialisierung in `setup()` vor das NVR-Laden gezogen, damit ein `data.begin()`-Fehlschlag dort sofort als `[FEHLER]` ins Web-Log geschrieben werden kann statt lautlos verworfen zu werden. |

## Version 20v08

Audit-Reaktionsplan Schritt 5, B1 sekundär.

| Version | Kategorie | Änderung |
|---|---|---|
| 20v08 | Stabilität | `WDG_TIMEOUT_MS` 30000→10000, `WDG_CHECK_MS` 5000→1000 (SysConf). Bei den bisherigen Werten gewinnt der Hardware-TWDT (15 s) bei jedem Freeze immer zuerst – der Software-Watchdog kam nie zum Zug (Audit-Befund B1). Abweichend vom Audit-Vorschlag (6000/1000) wurde der Wert anhand einer eigenen Worst-Case-Rechnung gewählt: `verifyPlayStarted()` kann bei einem dauerhaft nicht antwortenden DFPlayer bis zu ~5,5–6 s blockieren (3× `VERIFY_PLAY_RETRIES`, je `VERIFY_PLAY_DELAY_MS` + Mutex-Take + `readStateDrained()`-Gnadenfrist bei UART-Rauschen, deckt sich mit der im Audit selbst hergeleiteten Summe). Bei 6000 wäre die Marge dazu praktisch null gewesen – ein nur ungewöhnlich langsamer, aber regulärer Alarmversuch hätte den Watchdog fälschlich als Freeze werten können. Mit 10000/1000 liegt die Erkennung spätestens bei ~11 s: rund 5 s Marge über dem berechneten Worst-Case, weiterhin rund 4 s Marge unter den 15 s des TWDT. Begründung als Kommentar direkt bei den Konstanten in SysConf dokumentiert. |

## Version 20v09

Audit-Reaktionsplan Schritt 6 (C3), zusammen mit A3 verifiziert.

| Version | Kategorie | Änderung |
|---|---|---|
| 20v09 | Bugfix | `verifyPlayStarted()` liefert jetzt `PLAY_OK`/`PLAY_NO_SOUND`/`PLAY_CRASHED` statt `bool` (C3). `st==0` (Modul antwortet, „gestoppt" – typisch für „Datei nicht gefunden") und `st==-1` (keine Antwort) wurden bisher identisch als Absturz behandelt und lösten beide `ESP.restart()` aus – ein Neustart behebt einen Datei-/Kartenfehler aber nicht. Nur wenn nie eine Antwort ankam (`PLAY_CRASHED`), rechtfertigt das noch einen Neustart. Kam mindestens einmal `st==0` an (`PLAY_NO_SOUND`), gilt das Modul als lebendig; `triggerAlarm()` läuft in denselben Erfolgspfad wie `PLAY_OK` (Motor/Licht), statt zwei sinnlose Reboots auszulösen und danach still zu bleiben. |
| 20v09 | Bugfix | Neues Flag `alarmSilentFallback`: hält `ALARM_RUNNING` bei `PLAY_NO_SOUND` am Laufen, obwohl `playerStatus` dauerhaft `0` meldet – ohne dieses Gate hätte `mp3Finished` den Alarm schon beim ersten Poll (5 s) sofort wieder beendet. Einziger Ausstieg dann `ALARM_MAX_RUN_MS` (A3, zusammen mit C3 verifiziert wie von der Review-Notiz gefordert) oder manueller Stopp über S1. |
| 20v09 | Bugfix | S1-Handler (`inputTask`) entscheidet jetzt zusätzlich anhand von `alarmState`, nicht mehr nur anhand des Playerstatus, ob gestoppt oder Kuckuck ausgelöst wird (`if (alarmState == ALARM_RUNNING \|\| st > 0)`). Ohne diese Ergänzung hätte S1 einen `alarmSilentFallback`-Alarm (playerStatus==0, aber Motor/Licht laufen) nicht gestoppt, sondern versehentlich den Kuckuck ausgelöst. |
| 20v09 | Funktion | `readStateDrained()` wertet `DFPlayerError`-Frames vor dem Verwerfen aus und schreibt den Fehlercode ins Web-Log, statt sie wie jeden anderen Nicht-Feedback-Frame kommentarlos zu verwerfen – macht „Datei fehlt" von „Modul abgestürzt" im Log erstmals unterscheidbar. |

## Version 20v10

Audit-Reaktionsplan Schritt 7 (C4).

| Version | Kategorie | Änderung |
|---|---|---|
| 20v10 | Bugfix | `setup()`: `player.readFileCountsInFolder(1)` (0x4E) statt `player.readFileCounts()` (0x48) - `-1`. Bisher wurde die Gesamtdateizahl über alle Ordner abgefragt und `mp3Count = c - 1` gerechnet, in der Annahme, genau eine Datei liege außerhalb von Ordner 01 (der Startsound in Ordner 02) – zusätzliche Dateien in Ordner 02 oder vom Betriebssystem beim Kopieren angelegte Extra-Dateien machten diese Zahl falsch und erlaubten die Auswahl einer nicht existierenden Alarmdatei (Zubringer zu C3s Reboot-Kaskade). Die ordnerbezogene Abfrage liefert die Anzahl direkt für Ordner 01, kein Rechnen/Raten mehr nötig. |
| 20v10 | Bugfix | Bei Timeout der Bereitschaftsprüfung bleibt `mp3Count` jetzt auf 0 statt auf den geratenen Fallback 99 gesetzt zu werden – C5 (20v07) sperrt die Sound-Auswahl dann korrekt, statt eine falsche, nicht verifizierte Dateizahl vorzugaukeln. `[FEHLER]`-Log statt der bisherigen informativen `[DFPlayer]`-Meldung. |

## Version 20v11

Audit-Reaktionsplan Schritt 8 (C2) – zuletzt und ausdrücklich isoliert (dieser Bereich hat in
12v09–12v14 dreimal Regressionen erzeugt). Rollback-Punkt vor dieser Änderung als Git-Tag
`vor-C2-20v10` festgehalten.

| Version | Kategorie | Änderung |
|---|---|---|
| 20v11 | Bugfix | `drainSerial2Pre()`/`readStateDrained()` auf gemeinsame fortschrittsbasierte Drain-Schleife (`drainSerial2Progress()`) umgestellt. Bisher brach `drainSerial2Pre()` am Rückgabewert von `player.available()` ab – der auch nach einem vollständig konsumierten 0x41-ACK-Frame `false` liefert (`parseStack()` der Bibliothek behandelt den ACK intern, ohne `_isAvailable` zu setzen). Bei Pufferinhalt `[ACK][Feedback]` brach der Drain dadurch nach dem ACK ab und ließ den Feedback-Frame stehen; ein späterer `readStateDrained()`-Aufruf konnte diesen Altframe als Antwort auf eine ganz andere, neue Abfrage werten (Motor/Licht liefen, obwohl kein Ton spielte, ohne Fehlerlog). Die neue Schleife macht Fortschritt am Rohpuffer selbst fest (`Serial2.available()` vor/nach dem Read vergleichen) statt am Parser-Rückgabewert. |
| 20v11 | Bugfix | `readStateDrained()` ruft `drainSerial2Progress()` jetzt zusätzlich VOR der eigenen `player.readState()`-Abfrage auf – verhindert, dass ein bereits vor diesem Aufruf im Puffer liegender Altframe als Antwort auf die gerade gesendete Abfrage gewertet wird. |

## Version 20v12

Audit-Reaktionsplan Schritt 10 (E1, C6, C7, D2). E2 und E4 auf Nutzerwunsch bewusst zurückgestellt
(Boot-Taster des DevKit gewollt genutzt bzw. Bestätigungsabfrage bewusst nicht gewünscht).

| Version | Kategorie | Änderung |
|---|---|---|
| 20v12 | Bugfix | `touchTask`: erzwungener Reset auf `TS_IDLE` inkl. Baseline-Neuerfassung, wenn ein Pad länger als `TOUCH_MAX_HOLD_MS` (30 s) ununterbrochen "gedrückt" bleibt (E1). Bisher hatten `TS_PRESSED`/`TS_REPEAT` keinen Ausstieg außer dem Loslassen selbst – ein klemmendes Pad (Feuchtigkeit, Kabeldefekt) sendete unbegrenzt alle `TOUCH_REPEAT_MS` ein Event, z.B. zählte T4 die Lautstärke bis 0 herunter. `[WARNUNG]`-Log bei Auslösung. |
| 20v12 | Bugfix | `triggerAlarm()` sendet vor jedem Alarm `player.volume()` mit Untergrenze `ALARM_MIN_VOL` (10), unabhängig vom zuletzt gesendeten Wert (E1). Schützt gegen einen durch ein klemmendes Touch-Pad auf 0 heruntergezählten `vol`, ohne die persistierte Einstellung selbst zu verändern. |
| 20v12 | Bugfix | Neues Flag `alarmCancelRequested` (C6): S1, Sound-Vorschau-Stopp und das Funktionswahl-Menü setzen es über `requestAlarmCancelIfActive()`, wenn ihr `player.stop()` einen laufenden oder gerade startenden Alarm treffen könnte. `verifyPlayStarted()` liefert dann `PLAY_CANCELLED` statt `PLAY_CRASHED` – `triggerAlarm()` bricht sauber ab (Tages-Sperre trotzdem gesetzt) statt neu zu starten oder `alarmSilentFallback` zu aktivieren (Motor/Licht wären sonst kurz nach dem Stopp wieder angegangen). |
| 20v12 | Refactoring | Die Tages-Sperren-Zuweisung in `triggerAlarm()` in die neue Funktion `lockAlarmDayGuard()` ausgelagert – wird jetzt sowohl vom Erfolgspfad als auch vom neuen `PLAY_CANCELLED`-Abbruchpfad genutzt. |
| 20v12 | Bugfix | `onClock()` (T3/T4, Lautstärke) und `checkboxSound()` (Sound-Vorschau) ändern `vol`/`sound*_assigned`, Anzeige und `markSafeChange()` jetzt erst nach erfolgreichem `playerMutex`-Take (C7). Bisher liefen Zustandsänderung und Anzeige unbedingt, auch wenn der Take fehlschlug (z.B. während `alarmTask` den Mutex im Poll hält) – Anzeige/NVS und tatsächliche Player-Lautstärke liefen dann auseinander. Fehlschlag jetzt als `[FEHLER]` geloggt. |
| 20v12 | Stabilität | `html.reserve()` in der Web-Log-Startseite von 8192 auf 12288 Byte angehoben – der bisherige Wert deckte den Worst Case (festes Markup + 40 Ringpufferzeilen + Snapshots, real bis ~9,8 kB) nicht (D2). `/log`-Handler reserviert jetzt ebenfalls (`out.reserve(6144)`), vorher gar nicht. |

## Version 20v13

Audit-Reaktionsplan Schritt 11 (zwei Zweizeiler) – letzter offener Punkt der Umsetzungsreihenfolge.

| Version | Kategorie | Änderung |
|---|---|---|
| 20v13 | Bugfix | `esp_task_wdt_add(NULL)` in `inputTask`/`displayTask`/`alarmTask` sowie `esp_task_wdt_init()`/`esp_task_wdt_reconfigure()` in `setup()` werten jetzt den Rückgabewert aus. Schlägt die Anmeldung fehl, wird `[FEHLER]` geloggt statt wie bisher unbedingt "[TWDT] Hardware Watchdog aktiv" zu behaupten – genau der 12v15-Fehler (TWDT nie wirklich initialisiert, `esp_task_wdt_reset()` läuft ins Leere) wäre bisher symptomfrei geblieben. |
| 20v13 | Bugfix | `webLog("[NTP] Synchronisation OK")` und `snapTimeStr(snapNtpTime, …)` laufen jetzt nur noch bei tatsächlichem NTP-Erfolg, nicht mehr unbedingt nach der Warteschleife (auch nach einem Timeout-`break`). Vorher hätte das Log nach einem ausgefallenen Alarm einen Uhrzeitfehler fälschlich ausgeschlossen – diagnostisch teuer im Zusammenspiel mit A1/A5. |

Damit ist die im Audit-Reaktionsplan vorgesehene Umsetzungsreihenfolge (Schritte 1–11) vollständig
abgearbeitet. Offen bleiben nur noch die im Audit selbst nie gegengeprüften Punkte (siehe
`AuditReaktionsplan.md`, Abschnitt „Offene Prüfpunkte").

## Version 20v14

| Version | Kategorie | Änderung |
|---|---|---|
| 20v14 | Bugfix | Compile-Fehler `'PlayVerifyResult' does not name a type` behoben: Die Arduino-IDE fügt automatisch generierte Funktionsprototypen an den Dateianfang ein, noch vor der bisherigen `enum PlayVerifyResult`-Definition bei `verifyPlayStarted()` weiter unten in der Datei. Enum-Definition direkt nach die Includes verschoben, damit sie vor dem generierten Prototyp sichtbar ist. |

## Version 20v15

| Version | Kategorie | Änderung |
|---|---|---|
| 20v15 | Bugfix | `requestAlarmCancelIfActive()` bekommt Parameter `includeStartup`: Sound-Vorschau-Stopp (aus) und der Einstieg ins Funktionswahl-Menü lösen den Alarmabbruch jetzt nur noch aus, wenn der Alarm bereits bestätigt hörbar läuft (`ALARM_RUNNING`), nicht mehr schon während der reinen ~1,5s-Anlaufverifikation (`alarmTriggerInFlight`). Bisher konnte reine Menü-Navigation ohne jeden Bezug zum Alarm einen zeitgleich gerade erst startenden Alarm lautlos abbrechen, weil deren `player.stop()` über `requestAlarmCancelIfActive()` denselben Ausschlag lieferte wie ein bewusster Stopp – beobachtet 19.08.2026: Alarm 2 blieb während Sound-Vorschau-Navigation komplett aus (kein Ton, kein Motor, kein Licht), im Log nur "Wiedergabe waehrend Verifikation manuell gestoppt". S1 (dedizierter Stopp-Taster) behält das bisherige Verhalten (`includeStartup=true`) und darf weiterhin auch während der Anlaufverifikation abbrechen. |
| 20v15 | Bugfix | `triggerAlarm()` setzt `alarmCancelRequested` jetzt defensiv auf `false`, bevor der neue Versuch `playFolder()` sendet. Ein S1-Stopp eines bereits `ALARM_RUNNING`-Alarms setzte das Flag über `requestAlarmCancelIfActive()`, gab es danach aber nie wieder frei – einziger Konsument war `verifyPlayStarted()`. Der stehen gebliebene Altwert hätte den nächsten, damit völlig unbeteiligten Alarmversuch beim allerersten Verifikations-Poll fälschlich als `PLAY_CANCELLED` beendet. |

## Version 20v16

| Version | Kategorie | Änderung |
|---|---|---|
| 20v16 | Bugfix | Tages-Sperre `lastA1Day`/`lastA2Day` zusätzlich im RTC-Speicher (`rtcLastA1Day`/`rtcLastA2Day`, Gültigkeits-Flag `rtcDayGuardMagic`) gespiegelt, nach demselben Muster wie `rtcRetryMagic`. Bisher lag die Sperre nur im normalen RAM und wurde bei JEDEM Neustart auf 0xFFFF zurückgesetzt – auch bei einem harmlosen Reset-Tasterdruck oder Neuflashen kurz nach einem bereits erfolgreich gespielten Alarm. Lag dieser Neustart innerhalb des Nachholfensters (`ALARM_CATCHUP_MIN`, 60 Minuten), hielt `alarmDue()` den Alarm für verpasst und löste ihn erneut aus – beobachtet: beide Alarme unmittelbar nacheinander nach einem Reset, obwohl die aktuelle Uhrzeit keiner der beiden Alarmzeiten entsprach, sondern nur bis zu 60 Minuten danach lag. RTC_NOINIT-Speicher übersteht Reset/Neuflashen, wird aber bei echtem Power-On zufällig befüllt – das Magic-Flag unterscheidet beide Fälle: bei Power-On bleibt das Nachholfenster (verpasster Alarm nach Stromausfall) wie bisher aktiv. |

## Version 20v17

| Version | Kategorie | Änderung |
|---|---|---|
| 20v17 | Bugfix | 20v16-Fix wirkungslos: `RTC_NOINIT_ATTR` übersteht keinen EN-Pin-Reset (Reset-Taster, aber auch der harte Reset, den esptool/Arduino-IDE beim Neuflashen per DTR/RTS auslöst) – der EN-Pin schaltet den internen Spannungsregler des ESP32 kurz komplett ab, das entspricht elektrisch einem echten Power-On und löscht damit auch RTC_NOINIT-Speicher. Nur `ESP.restart()` (reiner Software-Reset, siehe `rtcRetryMagic`) lässt die RTC-Domäne durchgehend mit Strom versorgt. Nutzer meldete 19.08.2026, dass der Alarm nach Neuflashen weiterhin erneut auslöste. Tages-Sperre `lastA1Day`/`lastA2Day` jetzt stattdessen im Flash-NVR persistiert (`writeNVR()`/`readNVR()`, Debounce über `markSafeChange()`/`nvrTask` wie bei allen anderen Einstellungen) – das übersteht zuverlässig jeden Neustart-Typ inklusive echtem Stromausfall. Der bisherige RTC_NOINIT-Ansatz (`rtcDayGuardMagic`, `rtcLastA1Day`, `rtcLastA2Day`) wurde vollständig entfernt. |
| 20v17 | Bugfix | Compile-Fix: `lastA1Day`/`lastA2Day` wurden in `writeNVR()`/`readNVR()` (Zeile ~840) verwendet, aber erst weiter unten im Code (Zeile 1370) deklariert – C++ verlangt die Deklaration vor der ersten Verwendung. Deklaration vor `writeNVR()` gezogen. |
| 20v17 | Bugfix | Tages-Sperre blockte nach dem Ändern der Alarmzeit im Menü (`onAlarm1()`/`onAlarm2()`, T3/T4) den Alarm für den Rest des Tages: `alarmDue()` prüft nur `yday == lastDay`, unabhängig von der eingestellten Uhrzeit. Hatte der Alarm an diesem Tag schon einmal ausgelöst (z.B. als Nachhol-Alarm direkt nach Boot), löste er unter der neuen Zeit gar nicht mehr aus – ohne Web-Log-Eintrag, da `triggerAlarm()` nie aufgerufen wurde. Fix: T3/T4 in `onAlarm1()`/`onAlarm2()` setzen `lastA1Day`/`lastA2Day` bei jeder Stunden-/Minutenänderung auf `0xFFFF` zurück. |

## Version 20v18

| Version | Kategorie | Änderung |
|---|---|---|
| 20v18 | Bugfix | Web-Log: Vor der Überschrift „Verbindung – letzter WiFi Reconnect / NTP Sync" fehlte die Leerzeile zum darüberliegenden Log-Block. Ursache: `#log,#dflog` in der CSS-Regel für Padding/Umbruch, aber nur `#dflog{margin-bottom:16px}` – `#log` hatte keinen Abstand nach unten. Fix: `margin-bottom:16px` auch auf `#log` angewendet. |

## Version 20v19

| Version | Kategorie | Änderung |
|---|---|---|
| 20v19 | Qualität | `TOUCH_REPEAT_RATE_MS` aus SysConf entfernt: ungenutztes Duplikat von `TOUCH_REPEAT_MS` (identischer Wert 250 ms, identischer Zweck), nirgends im Code referenziert. |

## Version 20v20

| Version | Kategorie | Änderung |
|---|---|---|
| 20v20 | Funktion | Hardware-Änderung Motor-Treiber: LDO `MCP1700T-3302E/TO` regelt die Rail vor dem MOSFET jetzt fest auf 3,3V statt den Motor direkt an 5V zu betreiben. PWM schaltet damit die geregelte Spannung – Duty 255 bedeutet nur noch ~3,3V statt vormals 5V. Löst die bei 20v19 offene Prüffrage zur Kickstart-Überspannung (`MOTOR_PWM_KICK_DUTY`=255 lag bisher ungebremst auf 5V, ~1,67× Motor-Nennspannung 3V): voller PWM-Regelumfang 0..255 ist jetzt ohne Begrenzung und ohne Überspannungsrisiko nutzbar. Freilaufdiode korrigiert auf `1N4448` (realer Bauteilwert statt bisher dokumentiertem `1N4148`). |

## Version 20v21

| Version | Kategorie | Änderung |
|---|---|---|
| 20v21 | Funktion | Alarm-Fälligkeit an Zeitumstellungstagen korrigiert (Auftrag 21.08.2026): Der Wecker soll einen festen zeitlichen Abstand zu einem nachfolgenden Termin einhalten – dieser Abstand blieb bei einer Weckzeit zwischen 02:00:00–02:59:59 bisher nicht gewahrt. Frühjahr (letzter Sonntag März, Uhr springt 01:59:59→03:00:00 CEST, die Stunde existiert nicht): Weckzeit wird jetzt um 1h vorgezogen statt wie bisher bis zu 59 Min. zu spät (erst beim Erreichen von 03:00) auszulösen. Herbst (letzter Sonntag Oktober, Uhr springt 02:59:59 CEST→02:00:00 CET, die Stunde kommt zweimal vor): Alarm löst jetzt erst beim zweiten (Normalzeit-)Durchlauf aus statt wie bisher beim ersten (Sommerzeit-)Durchlauf, wodurch die Ruhezeit bis zu 60 Min. zu kurz war. Neue Funktion `updateDstDayFlags()` erkennt beide Umstellungstage TZ-generisch über `mktime()`/`tm_isdst`; `alarmDue()` erhält zusätzlich `isdstNow` zur Unterscheidung der beiden Herbst-Durchläufe. |

## Version 20v22

| Version | Kategorie | Änderung |
|---|---|---|
| 20v22 | Bugfix | Weckzeit-Verstellung löste Alarm sofort aus (gemeldet 25.08.2026): `onAlarm1()`/`onAlarm2()` hoben die Tages-Sperre (`lastA1Day`/`lastA2Day`) bisher bei JEDEM Stunde+/Minute+-Tastendruck auf, nicht erst beim Bestätigen der neuen Zeit. Beim Durchscrollen einer neuen Weckzeit (z.B. 10:00 → 14:30, bereits ausgelöster Alarm 1) lief der angezeigte Wert dabei durch Zwischenstände, von denen manche im Aufholfenster der aktuellen Uhrzeit lagen – der 500-ms-Haupt-Loop erkannte diese Zwischenwerte fälschlich als fällig und löste den Alarm mitten im Verstellen aus. Die Tages-Sperre wird jetzt erst in `uiTransition()` beim tatsächlichen Verlassen der Alarm-Seite aufgehoben – die neue Weckzeit wird dadurch erst bei ihrem tatsächlichen Eintreffen ausgelöst, nicht mehr rückwirkend während der Eingabe. |

## Version 20v23

| Version | Kategorie | Änderung |
|---|---|---|
| 20v23 | Bugfix | Sound-2-Vorschau spielte beim Betreten der Seite "Sound 2 wählen" sofort ab (gemeldet 25.08.2026): `menu()` setzt beim Betreten von "Sound 1 wählen" (Case 3) `sound1_on`/`sound2_on` explizit auf `false`, bevor `checkboxSound()` das Vorschau-Häkchen zeichnet – beim Betreten von "Sound 2 wählen" (Case 4) fehlte dieses Zurücksetzen für `sound2_on`. War die Vorschau von einem früheren Seitenbesuch noch aktiv (Nutzer hatte sie nicht per T2 ausgeschaltet, bevor er die Seite verließ), stand `sound2_on` beim erneuten Öffnen der Seite noch auf `true`, und `checkboxSound()` startete beim Neuzeichnen sofort wieder `player.playFolder()`. Fix: `sound2_on = false;` in Case 4 vor `checkboxSound()` ergänzt, analog zu Case 3. |

## Version 20v24

| Version | Kategorie | Änderung |
|---|---|---|
| 20v24 | Stabilität | Stack-Größen erhöht (Sicherheitsmarge auf Basis Stack High-Water Marks aus stackMonTask): `STACK_INPUT` 2240→2704, `STACK_ALARM` 2128→2524, `STACK_DISPLAY` 2176→2276. |

## Version 20v25

| Version | Kategorie | Änderung |
|---|---|---|
| 20v25 | Bugfix | Sound-1-Vorschau spielte nach Verlassen und Wiederbetreten der Seite "Sound 1 wählen" weiter (gemeldet 25.08.2026, Log-Beleg: `[FEHLER] Sound1-Vorschau-Stopp fehlgeschlagen (Mutex belegt)`): `checkboxSound()` setzt beim Ausschalten der Vorschau `sound1_on`/`sound2_on` zwar korrekt auf `false` (Checkbox zeigt "aus"), der zugehörige `player.stop()` steht aber unter einem 50-ms-`playerMutex`-Timeout. War der Mutex belegt (z.B. `alarmTask` pollt gerade einen laufenden Alarm, hält den Mutex bis zu 200–500 ms), schlug der Stop-Befehl komplett und folgenlos fehl – der DFPlayer spielte die vorherige Vorschau unbemerkt weiter, obwohl die Anzeige bereits "aus" zeigte. Da `checkboxSound()` unter gehaltenem `displayMutex` läuft, ist ein Warten/Retry an dieser Stelle laut Projektregel (kein `vTaskDelay()` unter gehaltenem Mutex) nicht möglich. Fix: neues Flag `pendingPlayerStopRetry`, gesetzt bei fehlgeschlagenem Take; `inputTask` holt den Stop direkt nach Freigabe von `displayMutex` mit größerem Timeout (300 ms) nach – betrifft Sound 1 und Sound 2 gleichermaßen. |

## Version 20v26

| Version | Kategorie | Änderung |
|---|---|---|
| 20v26 | Bugfix | Beide Sound-Vorschauen spielten sofort beim allerersten Betreten der Seite "Sound wählen" ab, ohne jeden Tastendruck (gemeldet 25.08.2026, reproduzierbar trotz 20v23-/20v25-Fix): `checkboxSound()` sendet in ihren "aus"-Zweigen (Case 3/4) unbedingt ein `player.stop()`, sobald `sound1_on`/`sound2_on` bereits `false` sind – auch dann, wenn der DFPlayer laut BUSY-Pin (`dfPlayerBusy()`, Hardware 2v0) längst idle ist. Ein `stop()`-Kommando an ein bereits leerlaufendes Modul löste bei diesem DFPlayer-Exemplar offenbar selbst eine ungewollte Wiedergabe aus, statt wirkungslos zu bleiben. Fix: `checkboxSound()` prüft in beiden "aus"-Zweigen zusätzlich `dfPlayerBusy()` und sendet `player.stop()` nur noch, wenn der Player laut Hardware-Signal tatsächlich beschäftigt ist – dieselbe Prüfung ergänzt im `pendingPlayerStopRetry`-Nachhol-Pfad aus 20v25. |

## Version 20v27

| Version | Kategorie | Änderung |
|---|---|---|
| 20v27 | Bugfix | Eigentliche Ursache der zuvor unter 20v26 vermuteten Sound-Wiedergabe beim Seitenaufruf gefunden (gemeldet 25.08.2026 mit exakten Reproduktionsschritten): Es spielte gar keine Vorschau, sondern der ECHTE Alarm 1/2 löste erneut aus. `uiTransition()` hob die Tages-Sperre (`lastA1Day`/`lastA2Day`) seit 20v22 beim Verlassen von "Alarm 1/2 einstellen" bedingungslos auf – auch wenn die Seite nur angeschaut und die Weckzeit gar nicht verändert wurde. Lag die gesetzte Weckzeit bereits in der Vergangenheit innerhalb des Nachholfensters (`ALARM_CATCHUP_MIN`), stufte `alarmDue()` den Alarm nach dem bloßen Seitenbesuch als erneut fällig ein – reproduzierbar sowohl über den 20s-Auto-Rücksprung auf die Uhrzeit-Seite als auch beim direkten Weiterblättern zur Sound-Seite. Fix: neue Flags `alarm1TimeEdited`/`alarm2TimeEdited`, gesetzt nur in `onAlarm1()`/`onAlarm2()` bei tatsächlichem T3-/T4-Tastendruck (Stunde/Minute ändern); `uiTransition()` hebt die Tages-Sperre beim Seitenverlassen jetzt nur noch auf, wenn eines dieser Flags gesetzt ist. |

## Version 20v28

| Version | Kategorie | Änderung |
|---|---|---|
| 20v28 | Hardware/Firmware | Taster S1/S2 auf der Platine vertauscht (Schaltplan-Update Hardware 2v0): S1 (Alarm aus / Kuckuck einmalig) liegt jetzt auf GPIO33, S2 (Zugschalter Licht + Mühlrad) auf GPIO32. In der Firmware ist nur die Pin-Zuordnung in `SysConf_20v28.h` (`S1`/`S2`-Konstanten) angepasst – die Event-/State-Logik (`isrS1()`/`isrS2()`, `EVT_S1`/`EVT_S2`, inputTask) arbeitet ausschließlich mit den symbolischen Konstanten und ist unverändert. |

## Version 20v29

| Version | Kategorie | Änderung |
|---|---|---|
| 20v29 | Hardware/Firmware | Ausgangs-GPIOs E1/E2/E3 auf der Platine umbelegt (Schaltplan-Update Hardware 2v0): Kuckuck (E1) GPIO25→**GPIO27**, DC-Motor/Mühlrad (E2) GPIO26→**GPIO25**, LED-Streifen/Licht (E3) GPIO27→**GPIO26**. In der Firmware ist nur der Zahlenwert der `E1`/`E2`/`E3`-Konstanten in `SysConf_20v29.h` geändert – die gesamte Ansteuerlogik (`digitalWrite(E1/E3, …)`, `ledcAttach(E2, …)`/`ledcWrite(E2, …)`, `motorStart()`/`motorStop()`, `runCuckooMachine()`, S2-Zugschalter, `/motor`-Handler) arbeitet ausschließlich mit den symbolischen Konstanten und ist unverändert. Motor-PWM-Kanal wandert damit von GPIO26 auf GPIO25 (LEDC-fähig, unkritisch). |

## Version 20v30

| Version | Kategorie | Änderung |
|---|---|---|
| 20v30 | Funktion | Ursache des letzten Resets (`esp_reset_reason()`) wird beim Boot ausgegeben – als `Serial.printf()` in `bTn_info()` und zusätzlich als `webLogf()`-Zeile direkt nach Anlegen von `webLogMutex` in `setup()`, damit sie auch remote im Web-Log sichtbar ist (z.B. zur Unterscheidung Brownout/Watchdog/Panic von normalem Power-on/Software-Reset). |
| 20v30 | Qualität | DFPlayer-Log entrauscht: `checkSerial2Leftover()` schreibt erst ab `SERIAL2_LEFTOVER_LOG_THRESHOLD` (20 Restbytes) eine Zeile statt bei jeder Wertänderung; die Retry-Meldung in `verifyPlayStarted()` ("kein Start-Status nach playFolder") erscheint erst ab dem 2. Versuch (`attempt > 1`), da ein einzelner Fehlversuch im Normalbetrieb üblich ist. |

## Version 20v31

| Version | Kategorie | Änderung |
|---|---|---|
| 20v31 | Qualität | Reihenfolge der Abschnitte auf der Log-Seite (`/`) festgelegt: Allgemeines Log, Verbindung, Touch Baseline, Stack High-Water Marks, DFPlayer, Mühlrad-Motor. Die Ring-Puffer-Auswertung sammelt DFPlayer- und allgemeine Meldungen jetzt in separaten Strings statt direkt in die HTML-Ausgabe zu schreiben, damit die Anzeigereihenfolge unabhängig von der Code-Reihenfolge ist. |
| 20v31 | Qualität | Reset-Ursache-Zeile in `[RESET] Ursache: …`-Tagformat umbenannt (bisher `Letzter Reset: …`, ohne Tag) und im Allgemeinen Log immer als letzte Zeile angezeigt statt chronologisch an ihrer Boot-Position. |

## Version 20v32

| Version | Kategorie | Änderung |
|---|---|---|
| 20v32 | Qualität | Reset-Ursache-Zeile (`[RESET] Ursache: …`) steht im Allgemeinen Log jetzt direkt nach `[RESET] resetCount: …` statt als letzte Zeile ganz am Ende – danach folgen die Meldungen der aktuellen Laufzeit. |

## Version 21v01

| Version | Kategorie | Änderung |
|---|---|---|
| 21v01 | Funktion | DFPlayer-BUSY-Pin von GPIO34 auf GPIO35 verlegt (`DFPLAYER_BUSY` in `SysConf_21v01.h`): GPIO35 liegt im Header-Bereich des Anschlusses, GPIO34 hätte ein zusätzliches Kabel benötigt. Beide Pins sind input-only (ADC1), die Logik ist unverändert. Hardware bleibt 2v0 (Entwicklungsstatus), Doku und Schaltplan-Notizen angepasst. |

## Version 21v02

| Version | Kategorie | Änderung |
|---|---|---|
| 21v02 | Funktion | OLED-SCL von GPIO22 auf GPIO19 verlegt: neue Konstanten `OLED_SDA` (21) und `OLED_SCL` (19) in `SysConf_21v02.h` statt der Board-Makros `SDA`/`SCL`; der Konstruktor `SSD1306Wire display(...)` verwendet sie. SDA bleibt GPIO21. Hardware bleibt 2v0 (Entwicklungsstatus), Schaltplan/Layout in KiCad separat nachzuziehen. |

bTn Wecker  ·  Änderungshistorie  ·  Stand 21v02

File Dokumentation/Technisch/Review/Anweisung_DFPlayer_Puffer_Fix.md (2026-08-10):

# Anweisung für Claude Code: DFPlayer Mini Puffer-Desync beheben

**Projekt:** bTn_Wecker_Projekt (Version 10v05)
**Betroffene Hardware:** DFPlayer Mini an Serial2 (RX=16, TX=17)

## Kontext / Diagnosebefund

Logauswertung vom 10.08.2026 zeigt: Vor `readState()`-Aufrufen im ALARM_RUNNING-Poll liegt konstant ein Rückstand von 20 Byte (= 2 vollständige 10-Byte-Frames) im Serial2-Puffer, gelegentlich 30 Byte. `readState()` liest offenbar pro Aufruf nur einen Frame, während pro Poll-Zyklus mindestens ein neuer Frame nachkommt — der Rückstand wird nie abgebaut. Dadurch liest `verifyPlayStarted()` nach `triggerAlarm()` einen veralteten Frame statt der aktuellen Antwort auf den gerade gesendeten `playFolder`-Befehl, was zu Fehlschlägen führt ("kein Start-Status", Versuch 1/3 und 2/3). Die bestehende Retry-Logik (3 Versuche) hat dies bisher überdeckt, ist aber kein verlässlicher Fix — bei einem Rückstand von 3+ Frames würde auch der letzte Versuch fehlschlagen.

## Umzusetzende Schritte

Bitte in der angegebenen Reihenfolge umsetzen, nach jedem Schritt kurz anhalten zur Rückmeldung.

### Schritt 1: Puffer-Drain vor zeitkritischen Befehlen
In `triggerAlarm()` unmittelbar vor dem Aufruf von `playFolder()`: alle noch im Serial2-Puffer stehenden Bytes verwerfen (`while(Serial2.available()) Serial2.read();`). Ziel: `verifyPlayStarted()` sieht garantiert nur die Antwort auf den gerade gesendeten Befehl.

### Schritt 2: `readState()` vollständig drainieren lassen
`readState()` so anpassen, dass bei jedem Aufruf **alle** verfügbaren vollständigen 10-Byte-Frames aus dem Puffer gelesen werden, nicht nur einer. Von den gelesenen Frames nur den zuletzt empfangenen (neuesten) als aktuellen Status werten, ältere verwerfen. Ziel: struktureller Rückstand wird an der Wurzel beseitigt, nicht nur punktuell vor dem Alarm.

### Schritt 3: Ursache der Frame-Häufung prüfen
Prüfen, ob der DFPlayer bei aktivem ACK-Modus zusätzlich zur angeforderten Statusantwort automatisch einen Bestätigungs-Frame pro Befehl sendet, und ob dies zusammen mit dem regulären Poll-Request zum Überschuss von einem Frame pro Zyklus führt. Falls ja: entweder ACK-Modus deaktivieren oder Poll-Routine so anpassen, dass beide Antworten pro Zyklus konsequent abgeholt werden.

### Schritt 4: Verifikationslogging
Bestehendes `webLogf()`-Logging der Serial2-Restbytes vor `readState()` beibehalten. Nach Umsetzung der Schritte 1–3 soll der Wert dauerhaft bei 0–10 Byte (0–1 Frame) liegen, nicht mehr stabil bei 20.

## Randbedingungen

- Kein `vTaskDelay()` unter Mutex (Projektregel). Das reine Verwerfen von Bytes via `Serial2.read()` ist nicht blockierend und daher unkritisch, auch innerhalb eines gehaltenen Mutex.
- Retry-Logik in `triggerAlarm()`/`verifyPlayStarted()` als Sicherheitsnetz belassen — soll nach dem Fix im Normalfall nicht mehr greifen.
- Alle Änderungen über `webLogf()` protokollieren, kein `Serial.print()`.
- Stackgrößen unverändert lassen, sofern nicht explizit erforderlich (nur über `STACK_*`-Konstanten in SysConf, falls doch nötig).

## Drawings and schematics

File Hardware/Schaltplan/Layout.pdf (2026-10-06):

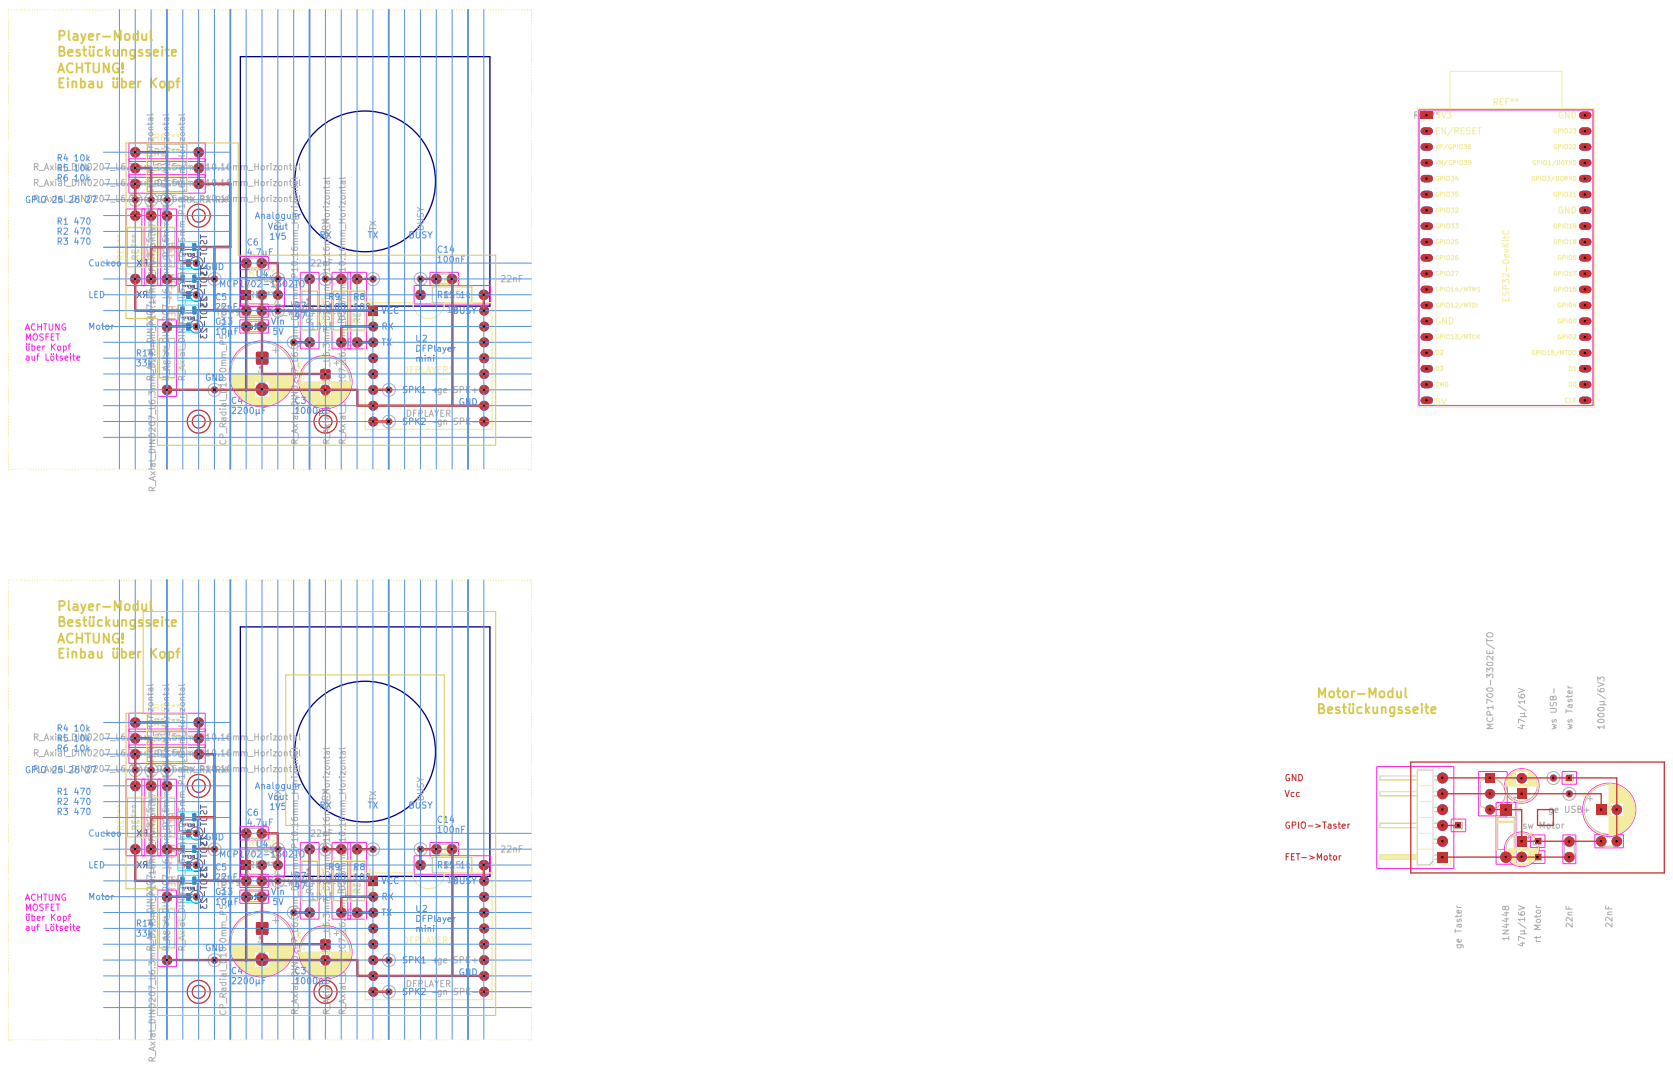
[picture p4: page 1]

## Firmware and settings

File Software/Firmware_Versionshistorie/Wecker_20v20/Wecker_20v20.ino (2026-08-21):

// bTn Wecker mit OLED-Anzeige und MP3-Player
// Basis: bTn_Wecker_9v18 – FreeRTOS + State Machine + WiFi-Konfigurator
// Boardverwalter: esp32 3.3.11 von Espressif Systems
//
// ─── State Machines ──────────────────────────────────────────
//
//  UI-State-Machine  (inputTask / displayTask)
//  ┌──────────┐  T0   ┌──────────┐  T0   ┌──────────┐
//  │ UI_CLOCK │──────▶│UI_ALARM1 │──────▶│UI_ALARM2 │
//  └────▲─────┘       └──────────┘       └──────────┘
//    T0 │ S3(off)          T0 ▼               T0 ▼
//  ┌────┴─────┐       ┌──────────┐       ┌──────────┐
//  │ UI_FUNCS │◀──────│UI_SOUND2 │◀──────│UI_SOUND1 │
//  └──────────┘  T0   └──────────┘  T0   └──────────┘
//  T0 (von UI_FUNCS) ──────────────────────▶ UI_CUCKOO_TIME
//  T0 (von UI_CUCKOO_TIME) ──────────────▶ UI_CLOCK
//  S3 (beliebig) ─────────────────────────▶ UI_INFO
//  S3 (von INFO) ──────────────────────────▶ UI_CLOCK
//  T3 (von INFO) ──────────────────────────▶ WiFi-Konfigurator  (11v05)
//  T4 (von INFO) ──────────────────────────▶ Werksreset
//
//  Alarm-State-Machine  (alarmTask)
//  ALARM_IDLE ──── Alarmzeit erreicht ──▶ ALARM_RUNNING
//  ALARM_RUNNING ── MP3 beendet (ALARM_POLL_MS) ─▶ ALARM_IDLE
//
//  Kuckuck-State-Machine  (alarmTask)
//  CUCKOO_IDLE ──── t_min==0, cuckoo_on ──▶ CUCKOO_RUNNING
//  CUCKOO_RUNNING ── CUCKOO_DURATION_MS abgelaufen ────▶ CUCKOO_IDLE
//
// ─── Task-Architektur ────────────────────────────────────────
//  touchTask   Core 0  Pri 2  ESP-IDF touch_pad_* → inputQueue
//                             State Machine: TS_IDLE → TS_PRESSED → TS_REPEAT
//                             Exklusiv: nur ein Pad aktiv, andere gesperrt
//  alarmTask   Core 0  Pri 2  Alarm- + Kuckuck-State-Machine
//                             Core 0: physisch getrennt von inputTask → kein CPU-Scheduling-Konflikt
//  wifiTask    Core 0  Pri 1  WiFi-Reconnect
//  nvrTask     Core 0  Pri 1  Flash-Sicherung bei Änderung
//  stackMonTask Core 0 Pri 1  Stack-HWM + Heap-Snapshot für Web-Log
//  watchdogTask Core 0 Pri 1  Anwendungs-Watchdog: inputTask / displayTask / alarmTask
//  webLogTask   Core 0 Pri 1  HTTP-Server Port WEBLOG_PORT → Ring-Puffer als Web-Seite
//
//  Hardware-TWDT (ESP32): inputTask, displayTask, alarmTask abonniert.
//  Timeout WDT_HARDWARE_MS – hardware-basiert, unabhängig vom FreeRTOS-Scheduler.
//  Verhindert CPU-Lock durch hängenden Task auf Hardware-Ebene.
//  inputTask   Core 1  Pri 2  Dispatch → UI-State-Machine
//  displayTask Core 1  Pri 1  Zeitanzeige, Auto-Rückkehr
// ─────────────────────────────────────────────────────────────

// ── Bibliotheken ─────────────────────────────────────────────
#include <WiFi.h>
#include <WebServer.h>
#include <time.h>
#include <esp_sntp.h>
#include <SSD1306Wire.h>
#include <DFRobotDFPlayerMini.h>
#include <Preferences.h>
#include <nvs_flash.h>
#include <driver/touch_pad.h>
#include <freertos/semphr.h>          // FreeRTOS Semaphore / Mutex API
#include <esp_task_wdt.h>             // ESP32 Hardware Task Watchdog Timer (TWDT)

// ── Konfiguration ────────────────────────────────────────────
#include "SysConf_20v20.h"                                                               // Pin-Belegung, Timing-Konstanten, Touch-Schwellwerte
#include "WEB.h"

// 20v14 (Compile-Fix): verifyPlayStarted()-Ergebnis muss vor der ersten Verwendung stehen, da die
// Arduino-IDE Funktionsprototypen automatisch an den Dateianfang einfügt (vor der eigentlichen
// Definition weiter unten) – ohne diese frühe Deklaration schlägt der Prototyp mit
// "does not name a type" fehl.
// PLAY_NO_SOUND: DFPlayer-Modul lebt nachweislich, aber ohne hörbaren Start → Alarm dennoch als
// laufend behandeln (Motor/Licht), statt neu zu starten.
// PLAY_CANCELLED (C6-Fix, Audit 2026-08-13): Nutzer hat während der Verifikation bewusst gestoppt
// (S1, Sound-Vorschau, Funktionswahl-Menü, siehe requestAlarmCancelIfActive()). Kein Absturz,
// kein Neustart nötig; triggerAlarm() bricht sauber ab.
enum PlayVerifyResult : uint8_t { PLAY_OK, PLAY_NO_SOUND, PLAY_CRASHED, PLAY_CANCELLED };

const char PGMInfo[] = "bTn_Wecker_" FW_VERSION;                                          // PROGMEM-fähig; kein String-Heap-Fragment

// ── WiFi-Laufzeit-Zugangsdaten (aus NVR, ab 4v0) ─────────────
// Werden in loadWifiCredentials() gefüllt und danach in
// WiFi.begin() sowie wifiTask verwendet.
static char sta_ssid[33] = "";                                                           // max. 32 Zeichen + '\0'
static char sta_psk [64] = "";                                                           // max. 63 Zeichen + '\0'
// ── Touch-Task ───────────────────────────────────────────────

static const touch_pad_t TOUCH_PADS[4] = {
  TOUCH_PAD_NUM0,   // T0 – GPIO4
  TOUCH_PAD_NUM2,   // T2 – GPIO2
  TOUCH_PAD_NUM3,   // T3 – GPIO15
  TOUCH_PAD_NUM4    // T4 – GPIO13
};

// ── State-Machine-Typen ──────────────────────────────────────
// Enum-Werte 0–7 entsprechen direkt den menu()-Seitennummern.
enum UiState : uint8_t {
  UI_CLOCK       = 0,   // Seite 0: Zeitanzeige
  UI_ALARM1      = 1,   // Seite 1: Alarm 1 einstellen
  UI_ALARM2      = 2,   // Seite 2: Alarm 2 einstellen
  UI_SOUND1      = 3,   // Seite 3: Sound 1 wählen
  UI_SOUND2      = 4,   // Seite 4: Sound 2 wählen
  UI_FUNCS       = 5,   // Seite 5: Funktionen wählen
  UI_CUCKOO_TIME = 6,   // Seite 6: Kuckuck-Aktivzeit einstellen
  UI_INFO        = 7    // Seite 7: Info (nur via S3 erreichbar)
};

enum AlarmState  : uint8_t { ALARM_IDLE,  ALARM_RUNNING  };
enum CuckooState : uint8_t { CUCKOO_IDLE, CUCKOO_RUNNING };

// Touch-Task State Machine
// TS_IDLE    – kein Touch aktiv
// TS_PRESSED – Touch erkannt, wartet auf HOLD-Schwelle (750 ms)
// TS_REPEAT  – HOLD erreicht, sendet EVT alle TOUCH_REPEAT_MS (250 ms)
enum TouchState  : uint8_t { TS_IDLE, TS_PRESSED, TS_REPEAT };

volatile UiState     uiState     = UI_CLOCK;
volatile AlarmState  alarmState  = ALARM_IDLE;
volatile CuckooState cuckooState = CUCKOO_IDLE;
// 20v09 (C3-Fix): true, solange ALARM_RUNNING ohne bestätigten Ton läuft
// (verifyPlayStarted() lieferte PLAY_NO_SOUND – Modul lebt, Datei startet
// aber nicht). In diesem Fall darf playerStatus==0 in runAlarmMachine() den
// Alarm NICHT beenden (das wäre sofort beim ersten Poll der Fall) – einziger
// Ausstieg ist dann ALARM_MAX_RUN_MS (A3) oder S1. Cross-core wie alarmState.
volatile bool alarmSilentFallback = false;
// 20v12 (C6-Fix, Audit 2026-08-13): von S1/Sound-Vorschau/Funktionswahl
// gesetzt, wenn player.stop() einen laufenden Alarmversuch trifft (siehe
// requestAlarmCancelIfActive()). verifyPlayStarted() wertet es als
// regulären Nutzerabbruch statt als Absturz – ohne dieses Signal sah
// triggerAlarm() den absichtlich gestoppten Player als Fehlschlag und
// startete entweder neu (ESP.restart(), löste denselben Alarm nach dem
// Reboot erneut aus) oder aktivierte alarmSilentFallback (Motor/Licht
// wieder an, obwohl der Nutzer gerade gestoppt hat).
volatile bool alarmCancelRequested = false;

// ── FreeRTOS Objekte ─────────────────────────────────────────
static QueueHandle_t     inputQueue   = nullptr;
static SemaphoreHandle_t displayMutex = nullptr;                                         // Mutex: exklusiver Display-Zugriff
static SemaphoreHandle_t playerMutex  = nullptr;                                         // Mutex: exklusiver DFPlayer-Zugriff (thread-safe Serial2)
static SemaphoreHandle_t nvrSemaphore = nullptr;

// Task-Handles – werden in setup() befüllt, von stackMonTask gelesen
static TaskHandle_t hTouchTask   = nullptr;
static TaskHandle_t hWifiTask    = nullptr;
static TaskHandle_t hNvrTask     = nullptr;
static TaskHandle_t hInputTask   = nullptr;
static TaskHandle_t hDisplayTask = nullptr;
static TaskHandle_t hAlarmTask      = nullptr; // Handle für stackMonTask-Abfrage
static TaskHandle_t hWatchdogTask   = nullptr; // Handle für watchdogTask
static TaskHandle_t hStackMonTask   = nullptr; // 9v14: HWM-Abfrage von außerhalb
static TaskHandle_t hWebLogTask     = nullptr; // 9v14: HWM-Abfrage von außerhalb

// ── Hardware ─────────────────────────────────────────────────
SSD1306Wire         display(0x3C, SDA, SCL, GEOMETRY_128_64);
DFRobotDFPlayerMini player;
Preferences         data;

// ── Zeit / Datum ─────────────────────────────────────────────
time_t  now;
tm      timeinfo;
char    datum[11];
char    zeit[9];
char    datum_sync[9];
char    zeit_sync[9];
char    datum_WiFi[9];
char    zeit_WiFi[9];

// NTP-Callback schreibt in tmp-Puffer + setzt Flag.
// displayTask überträgt unter displayMutex in datum_sync/zeit_sync.
// Verhindert Race Condition zwischen SNTP-Task und menu(7).
static char          datum_sync_tmp[9];
static char          zeit_sync_tmp[9];
static volatile bool ntpSyncPending  = false; // true: NTP-Callback hat neue Daten, displayTask überträgt
static char          datum_WiFi_tmp[9];        // Double-Buffer: wifiTask schreibt nur bei !wifiSyncPending (Core 0)
static char          zeit_WiFi_tmp[9];         // displayTask überträgt unter displayMutex nach datum_WiFi/zeit_WiFi
static volatile bool wifiSyncPending = false;  // 11v00: dient zugleich als Schreibsperre für wifiTask (verhindert Torn-Read)
volatile uint8_t t_hour;
volatile uint8_t t_min;
volatile uint8_t t_sec;
// 9v14: t_sec_alt wanderte in displayTask als static – nur dieser Task
// liest/schreibt; file-scope suggerierte fälschlich Mehr-Task-Zugriff.

// ── Alarm ────────────────────────────────────────────────────
bool    a1_on   = true;
uint8_t a1_hour = 6;
uint8_t a1_min  = 0;
char    str_a1[6];
bool    a2_on   = true;
uint8_t a2_hour = 6;
uint8_t a2_min  = 0;
char    str_a2[6];

volatile uint32_t t_start4 = 0;
volatile uint32_t lastTouchMs = 0;                                                       // Zeitstempel letzter Touch-/Taster-Event (EVT_T0–T4, EVT_S3)
static volatile bool displayBlanked = false;                                             // 10v00: true wenn OLED nach DISPLAY_TIMEOUT_MS abgeschaltet wurde
volatile uint32_t t_start6 = 0;
volatile uint32_t alarmRunStart = 0;                                                     // 20v05 (A3-Restarbeit): Startzeitpunkt von ALARM_RUNNING – im Gegensatz zu t_start6 (Poll-Timer, wird bei jedem Poll zurückgesetzt) unverändert bis zum Alarmende, Basis für ALARM_MAX_RUN_MS
         uint32_t t_start7 = 0;
volatile uint32_t t_start_S2 = 0;                                                        // 12v02: Einschaltzeitpunkt Licht/Mühlrad via Zugschalter S2

// ── Sound ────────────────────────────────────────────────────
bool    sound1_on   = false;
uint8_t sound1_selected      = 1;
char    str_s1[4];
uint8_t sound1_assigned = 1;
char    str_s1_play[4];
bool    sound2_on   = false;
uint8_t sound2_selected      = 1;
char    str_s2[4];
uint8_t sound2_assigned = 1;
char    str_s2_play[4];
uint8_t vol         = 9;
uint8_t MAX_VOL     = 25;
char    str_vol[3];
int16_t playerStatus = 0;      // nur Core 0: alarmTask schreibt, alarmTask liest – kein volatile nötig
int16_t mp3Count    = 0;
char    str_mp3[4];
uint32_t resetCount = 0;
char     str_reset[5];                                                                   // "nnnn" + null (max 9999 Resets sichtbar)

volatile bool safeChange = false;
// 11v00: Zeitstempel des letzten Events, das safeChange gesetzt hat.
// inputTask gibt nvrSemaphore erst frei, wenn seit diesem Zeitpunkt
// mind. NVR_COMMIT_DELAY_MS ohne weiteres Event vergangen sind.
// Schützt Flash vor Writes bei gehaltener Einstelltaste (Touch-REPEAT).
static volatile uint32_t safeChangeMs = 0;

// 11v00: Markiert eine persistierbare Änderung – Timestamp wird bei jedem
// neuen Event aktualisiert, sodass der Debounce-Zeitraum neu beginnt.
static inline void markSafeChange() {
  safeChangeMs = millis();
  safeChange   = true;
}

// ── Taster Toggle-Status ─────────────────────────────────────
volatile bool S2_SW = false;                                                             // Toggle-Status Zugschalter

// ── Funktion-Vorwahl ─────────────────────────────────────────
bool    cuckoo_on      = false;
uint8_t cuckoo_onTime  = 6;             // erste Stunde (von hh), Default 06:00
uint8_t cuckoo_offTime = 22;            // letzte Stunde (bis hh), Default 22:00
char    str_cot[3];                     // "hh" von-Zeit
char    str_coff[3];                    // "hh" bis-Zeit
bool    light_on   = true;
bool    wheel_on   = false;

// 12v03: Mühlrad-Motor-Pulsweite zur Laufzeit verstellbar (Web-Slider /motor),
// NVS-persistiert. motor_duty = wirksamer LEDC-Sollwert (0..255), Default aus
// SysConf. motorRunning = läuft der Motor gerade? → Live-Übernahme einer
// Slider-Änderung ohne Neustart. Beide volatile: webLogTask (Core 0) schreibt,
// alarmTask/inputTask lesen – 8-/32-bit-Zugriff auf Xtensa atomar.
volatile uint8_t motor_duty   = MOTOR_PWM_DUTY;
volatile bool    motorRunning = false;

// pageselect: spiegelt (uint8_t)uiState – wird von checkboxAlarm/Sound genutzt
volatile uint8_t pageselect = 0;

// ── Taster-Debounce ──────────────────────────────────────────
// Zwei-Stufen-Debouncing:
//   isrBtnMs[]  – ISR-Ebene:      filtert Hardware-Prellen (BTN_DEBOUNCE_MS =  30 ms)
//   lastBtnMs[] – Task-Ebene:     Aktionssperre            (BTN_LOCKOUT_MS   = 1000 ms)
static volatile uint32_t isrBtnMs[3] = {};  // IRAM-zugänglich: von ISR gelesen/geschrieben
static uint32_t          lastBtnMs[3] = {}; // von inputTask gelesen/geschrieben

// ── Anwendungs-Watchdog Alive-Timestamps ─────────────────────
// Jeder überwachte Task setzt seinen Wert in jedem Zyklus.
// watchdogTask prüft alle WDG_CHECK_MS ob der Wert jünger als WDG_TIMEOUT_MS ist.
static volatile uint32_t wdg_inputTask   = 0; // gesetzt von inputTask   (alle ~50 ms)
static volatile uint32_t wdg_displayTask = 0; // gesetzt von displayTask (alle DISPLAY_UPDATE_MS)
static volatile uint32_t wdg_alarmTask   = 0; // gesetzt von alarmTask   (alle 500 ms)




// =============================================================
//  Web-Logger  (ab 9v1)
//
//  webLog(msg) ersetzt Serial.*-Ausgaben nach WiFi-Connect.
//  Schreibt in einen Ring-Puffer (WEBLOG_LINES Einträge).
//  webLogTask startet einen HTTP-Server auf Port WEBLOG_PORT.
//  Browser ruft / auf → HTML-Seite mit Auto-Refresh alle 20 s.
//  /log liefert den aktuellen Pufferinhalt als plain text.
//  webLogReady-Flag: webLog() puffert erst wenn Task gestartet.
// =============================================================

static SemaphoreHandle_t webLogMutex  = nullptr;          // schützt den Ring-Puffer

// Ring-Puffer
static char   webLogBuf[WEBLOG_LINES][WEBLOG_LINE_LEN];   // Zeilen-Array
static uint16_t webLogHead = 0;                            // nächste Schreibposition
static uint16_t webLogCount = 0;                           // bisher eingetragene Zeilen

// ── Snapshots: jeweils letzter Wert mit Timestamp ─────────────
// Werden unter webLogMutex geschrieben und in der Web-Seite
// als dedizierte Sektionen angezeigt (nicht im Ring-Puffer).
#define SNAP_BUF_LEN  480
static char snapTouchBuf[SNAP_BUF_LEN] = "(noch keine Daten)";
static char snapTouchTime[20]          = "";
static char snapStackBuf[SNAP_BUF_LEN] = "(noch keine Daten)";
static char snapStackTime[20]          = "";
static char snapNtpTime[20]            = "";
static char snapAlarmTime[20]          = "";              // letzter erfolgreich gestarteter Alarm (siehe triggerAlarm)

// Schreibt eine Nachricht in den Ring-Puffer (thread-safe).
// Bleibt still wenn Mutex noch nicht initialisiert.
void webLog(const char* msg) {
  if (!webLogMutex) return;
  if (xSemaphoreTake(webLogMutex, pdMS_TO_TICKS(50)) == pdTRUE) {
    snprintf(webLogBuf[webLogHead], WEBLOG_LINE_LEN, "%s", msg);
    webLogHead  = (webLogHead + 1) % WEBLOG_LINES;        // Überlauf: älteste Zeile überschreiben
    if (webLogCount < WEBLOG_LINES) webLogCount++;
    xSemaphoreGive(webLogMutex);
  }
}

// Printf-Variante für komfortablen Aufruf
void webLogf(const char* fmt, ...) {
  char buf[WEBLOG_LINE_LEN];
  va_list args;
  va_start(args, fmt);
  vsnprintf(buf, sizeof(buf), fmt, args);
  va_end(args);
  webLog(buf);
}

// Schreibt den aktuellen Zeitstempel in buf (NTP-Uhrzeit oder Uptime)
static void snapTimeStr(char* buf, size_t len) {
  time_t t = time(nullptr);
  if (t > 1700000000UL) {
    struct tm tm_val;
    localtime_r(&t, &tm_val);
    strftime(buf, len, "%d.%m.%Y %H:%M:%S", &tm_val);
  } else {
    snprintf(buf, len, "+%lus", millis() / 1000UL);
  }
}

// 20v04 (A5-Fix, Audit 2026-08-13): Ohne gültige Systemzeit (kein NTP-Sync,
// Systemzeit auf Epoch 0 seit Boot) darf weder Alarm noch Kuckuck auslösen –
// die pegelbasierte Fälligkeitsprüfung (siehe alarmDue()) würde auf der
// 1970-Uhr sonst innerhalb weniger Stunden nach Boot feuern. Gate steht daher
// vor jeder Alarm-/Kuckuck-Auswertung in alarmTask, nicht nur als Zusatz.
static inline bool timeValid() { return time(nullptr) > 1700000000UL; }

// Zählt seit Boot, wie oft beim Start eines DFPlayer-Befehls noch
// unerwartete Bytes im Serial2-Empfangspuffer standen (Hinweis auf
// verspätete/verlorene Antworten bzw. UART-Desync). Vor jedem player.*-
// Aufruf zu rufen, der ein Kommando an den DFPlayer sendet.
// serial2LeftoverCount zählt JEDE Abfrage mit Restbytes (unabhängig vom Log);
// serial2LeftoverLastLogged hält den zuletzt GEMELDETEN Wert, damit
// webLogf() nur bei einer Änderung der Restbyte-Anzahl schreibt. Bleibt
// dabei über Nullstände hinweg erhalten (kein Reset bei avail==0): sonst
// würde z.B. während ALARM_RUNNING derselbe wiederkehrende Restbyte-Wert
// (Poll → Restbytes → gedraint auf 0 → nächster Poll dieselbe Anzahl) bei
// jedem Zyklus erneut als "neue" Änderung gemeldet, nur weil der Puffer
// dazwischen kurz leer war.
static uint32_t serial2LeftoverCount      = 0;
static int      serial2LeftoverLastLogged = -1;                                          // -1 = noch nichts gemeldet

static void checkSerial2Leftover(const char* label) {
  int avail = Serial2.available();
  if (avail > 0) {
    serial2LeftoverCount++;
    if (avail != serial2LeftoverLastLogged) {
      serial2LeftoverLastLogged = avail;
      char ts[20];
      snapTimeStr(ts, sizeof(ts));
      webLogf("[DFPlayer] Serial2 Restbytes vor %s: %d (seit Boot: %lu, %s)",
              label, avail, (unsigned long)serial2LeftoverCount, ts);
    }
  }
}

// 20v00: Direkter GPIO-Status des DFPlayer BUSY-Pins (ab Hardware 2v0), ohne
// Serial2/playerMutex – LOW = Wiedergabe läuft, HIGH = Pause/Idle. Kein Ersatz
// für readStateDrained() (liefert keinen Grund/Quelle wie Play-Finished), aber
// als schnelle, blockierungsfreie Zusatzabfrage nutzbar (z.B. Anzeige/Polling).
static bool dfPlayerBusy() {
  return digitalRead(DFPLAYER_BUSY) == LOW;
}

// 20v03: Mehrfach-Sampling für sicherheitskritische Stellen (ALARM_RUNNING
// beendet den Alarm bei einer einzigen Fehlmessung unwiderruflich – Motor/
// Licht aus, State-Reset). Trotz RC-Filter (100µs Zeitkonstante, siehe
// Hardware/Schaltplan/DFPlayer-BUSY.md) bleibt ein Rest-Risiko für Störimpulse,
// die die Filter-Zeitkonstante überdauern. Erst wenn 3 Abtastungen im Abstand
// von je 5 ms übereinstimmend "idle" (HIGH) melden, gilt der Player als
// wirklich nicht mehr beschäftigt – ein einzelner durchschlagender Störimpuls
// kann so keinen vorzeitigen Alarm-Abbruch mehr auslösen.
static bool dfPlayerIdleDebounced() {
  for (uint8_t i = 0; i < 3; i++) {
    if (dfPlayerBusy()) { return false; }
    vTaskDelay(pdMS_TO_TICKS(5));                                                        // außerhalb Mutex – Projektregel eingehalten
  }
  return true;
}

// 20v11 (C2-Fix, Audit 2026-08-13): gemeinsame fortschrittsbasierte Drain-
// Schleife für drainSerial2Pre() und readStateDrained() (s.u.). Bricht ab,
// sobald ein player.read() den Rohpuffer NICHT verkleinert hat (Bytes noch
// unvollständig, mitten im Empfang eines Frames) – anders als der bisherige
// Abbruch am Rückgabewert von player.available(), der auch nach einem
// VOLLSTÄNDIG konsumierten 0x41-ACK-Frame false liefert (parseStack() der
// Bibliothek behandelt den ACK intern, ohne _isAvailable zu setzen). Bei
// Pufferinhalt [ACK][Feedback] brach die alte Version dadurch nach dem ACK
// ab und ließ den Feedback-Frame stehen – genau der Fall, der in
// readStateDrained() (unten) ein Altframe als Antwort auf eine neue Abfrage
// vortäuschen konnte (Motor/Licht liefen, obwohl kein Ton spielte).
// Endlosschleife ausgeschlossen (Review-Notiz 2026-08-14): der äußere
// Schleifenkopf verlangt bereits Serial2.available() >= DFPLAYER_RECEIVED_
// LENGTH, ein unvollständiger Frame kann die Schleife also gar nicht erst
// betreten; SERIAL2_DRAIN_MAX_BYTES bleibt zusätzlich als harte Grenze.
static void drainSerial2Progress() {
  uint16_t drained = 0;
  while (Serial2.available() >= DFPLAYER_RECEIVED_LENGTH && drained < SERIAL2_DRAIN_MAX_BYTES) {
    int before = Serial2.available();
    player.available();
    player.read();
    if (Serial2.available() >= before) { break; }                                        // kein Fortschritt: unvollstaendiger Frame, stehen lassen
    drained += DFPLAYER_RECEIVED_LENGTH;
  }
}
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
void loop() {
  vTaskDelete(nullptr);
}

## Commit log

2026-04-07 Initial commit – Firmware 9v4, vollständige Projektstruktur
    Enthält: Firmware_aktuell (9v4), Firmware_Versionshistorie (1v1–9v0),
    Dokumentation, Hardware-Platzhalter, CLAUDE.md.
    Bugfix 9v4: playerStatus == 0 statt < 1 verhindert fälschlichen
    Alarm-Abbruch bei UART-Timeout während WebLog-Zugriff.
2026-04-07 9v4: Bugfixes aus Code-Review
    - KRITISCH: vTaskDelay() unter playerMutex in inputTask/EVT_S1 behoben
    (Projektregel: Mutex sofort freigeben, vTaskDelay außerhalb)
    - webLogMutex früh in setup() initialisieren: setup()-Meldungen
    (WiFi, NTP) werden jetzt gepuffert statt lautlos verworfen
    - webLogReady-Flag entfernt (toter Code, Mutex war alleiniges Gate)
    - Veraltete Versionsstrings korrigiert:
    WEB.h Footer: 4v0→9v4, Web-Log-Titel: 9v3→9v4, TWDT-Kommentar: 9v3→9v4
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2026-04-09 9v6: Bugfixes – Web-Log Versionsstring, mp3Count-Clamp, Kommentare korrigiert
    - Web-Log HTML: "9v5" → "9v6"
    - sound1/2_assigned auf mp3Count begrenzt nach DFPlayer-Init
    - Kommentare: alarmTask Core 1→0, playerStatus Core 1→0, BTN_LOCKOUT→DEBOUNCE
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2026-04-09 9v7: Bugfix – EVT_S3 aktualisiert lastTouchMs für korrekte Auto-Rückkehr von UI_INFO
    S3 hat EVT-ID 6, EVT_T4=3. Die Bedingung (evt <= EVT_T4) schloss EVT_S3 aus,
    sodass lastTouchMs beim Öffnen der Info-Seite nicht gesetzt wurde und
    Auto-Return sofort auslöste statt nach 20 s.
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2026-04-12 9v14: 7 veraltete/fehlerhafte Kommentare korrigiert
    - menu(6) → menu(7): datum_sync wird auf UI_INFO angezeigt
    - lastTouchMs: EVT_S3 in Kommentar ergaenzt
    - str_reset: max 999 → max 9999 (Format %04lu, Buffer [5])
    - NVR-Abschnitt: "unveraendert" entfernt (bumpResetCount seit 9v14)
    - alarmTask: "verdraengt" → parallele Ausfuehrung (versch. Cores)
    - stackMonTask: "per Serial (4-Byte-Words)" → Web-Snapshot (Bytes)
    - webLogTask: Auto-Refresh "3 s" → "20 s"
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2026-04-15 9v16: DFPlayer-Kaltstart-Hang behoben via Retry-Schleife
    player.begin() wurde bisher nur einmal aufgerufen. Beim Kaltstart (Power-On)
    ist der DFPlayer noch in eigener Init-Phase und antwortet nicht – begin()
    scheiterte und der DFPlayer blieb stumm. Nach Reset-Taste (VCC bleibt an)
    war der DFPlayer bereits indiziert, daher klappte es dort sofort.
    - player.begin() in Schleife mit DFP_INIT_TIMEOUT_MS (10 s) und
    DFP_INIT_RETRY_MS (500 ms)
    - SETUP_MP3_TIMEOUT_MS 5000 -> 10000 ms (SD-Indizierung nach Power-On
    dauert spuerbar laenger als nach Reset)
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2026-04-16 10v06: wakeDisplay() TOCTOU + Race Condition behoben, lastTouchMs volatile
    - BUG 1+3: displayBlanked-Check und lastTouchMs=millis() atomar unter displayMutex
    - BUG 2: lastTouchMs als volatile deklariert (Cross-Core-Sichtbarkeit Core0→Core1)
2026-04-17 11v00: Review-Fixes (NVR-Debounce, wifiTask-Guard, Log-Regel)
    Drei Findings aus dem 10v06-Review behoben:
    (1) Flash-Wear: nvrSemaphore erst nach NVR_COMMIT_DELAY_MS (2 s) Ruhezeit
    freigeben; markSafeChange() kapselt safeChange + safeChangeMs-Timestamp.
    (2) wifiTask double-buffer: snprintf nur wenn !wifiSyncPending – schließt
    Torn-Read-Fenster gegen displayTask-memcpy.
    (3) Serial.printf nach WiFi-Connect in setup() durch webLogf ersetzt;
    Log-URL in IP-Zeile konsolidiert.
2026-04-17 11v00: Serial.printf mit Log-URL nach WiFi-Connect wiederhergestellt
    Review-Fix (3) aus 11v00 zurückgenommen: die Web-Log-Adresse muss im
    Serial-Monitor sichtbar sein, sonst ist das Web-Log praktisch
    unerreichbar – die URL steht ja erst im Web-Log selbst. Kein Verstoß
    gegen die Projektregel, sondern betrieblich notwendige Ausnahme.
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2026-04-17 Doku: StateMachines.pptx auf 11v00 (playerStatus == 0)
    Slide 0 (Alarm-FSM): Übergang RUNNING→IDLE aktualisiert –
    'playerStatus < 1' → 'playerStatus == 0' (9v4-Fix).
    Formatierung/Runs erhalten.
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2026-05-31 Firmware 12v04: Reset-Zeitstempel im Web-Log nach Stromausfall nachtragen
    Bugfix: "Allgemeines Log - letzter Reset" zeigte nach Stromausfall nur
    "-" (kein Datum/Uhrzeit), wenn der ESP32 schneller bootet als der Router
    und die WLAN/NTP-Synchronisation in setup() scheitert. displayTask traegt
    snapNtpTime jetzt beim ersten NTP-Sync nach (ueber ntpSyncPending) und
    rekonstruiert den Reset-Zeitpunkt aus aktueller Zeit minus Uptime.
    Reset-Zaehler war nie betroffen (NVS, unabhaengig von WLAN/NTP).
    Doku/Historie auf 12v04 resynct, 12v03-Snapshot STACK_WIFI nachgezogen,
    11v05-Snapshot entfernt (Max-5-Regel), Stueckliste um Motor-Treiber ergaenzt.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
    [Wecker_12v04.ino]
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2026-08-08 Firmware 12v06: DFPlayer Start-Check mit Wartezeit statt Fehlalarm-Reset
    verifyPlayStarted() fragte readState() bisher nur 1 ms nach playFolder()
    ab und loeste bei st<=0 sofort ESP.restart() aus. Der DFPlayer braucht
    nach dem Play-Befehl jedoch Zeit, um die Datei von der SD-Karte zu laden
    und den Status auf "playing" zu setzen - die Abfrage erwischte ihn dabei
    noch im alten Zustand und loeste einen Neustart aus, obwohl der Player
    korrekt spielte.
    verifyPlayStarted() wartet jetzt vor jeder Abfrage VERIFY_PLAY_DELAY_MS
    (500 ms) und erlaubt bis zu VERIFY_PLAY_RETRIES (3) Versuche - bei
    anhaltendem st<=0 steht das Ergebnis spaetestens nach 1500 ms fest,
    bevor der Neustart folgt.
    Doku/Historie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
    [Wecker_12v06.ino]
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2026-08-08 Firmware 12v07: DFPlayer-Absturz-Neustart auf 10 Versuche begrenzt
    Reagierte der DFPlayer nach einem Absturz-Neustart weiterhin nicht,
    loeste triggerAlarm() bei jedem weiteren Fehlversuch erneut ESP.restart()
    aus - ein dauerhaft defekter oder nicht angeschlossener DFPlayer fuehrte
    so zu einer unbegrenzten Neustart-Schleife.
    triggerAlarm() erhaelt einen failCount-Parameter, der ueber den neuen
    RTC_NOINIT_ATTR-Zaehler rtcRetryCount (uebersteht ESP.restart() wie die
    bestehenden rtcRetry*-Variablen) ueber die Neustarts hinweg mitgezaehlt
    wird. Ab ALARM_MAX_RESTARTS (10) Fehlversuchen bricht die Funktion den
    Alarm fuer den Tag endgueltig ab statt erneut neu zu starten (Motor/Licht
    bleiben aus) u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
    [Wecker_12v07.ino]
2026-08-10 Firmware 12v08: DFPlayer-Sektion im Web-Log, Serial2-Restbytes-Logging
    Web-Log neu organisiert: DFPlayer-Meldungen (alle Zeilen mit "DFPlayer"
    im Text) erscheinen jetzt in einem eigenen Abschnitt statt im
    "Allgemeinen Log". Titel zeigt Zeitstempel des letzten erfolgreichen
    Alarms (neuer Snapshot snapAlarmTime, gesetzt in triggerAlarm() nach
    erfolgreichem playFolder()).
    Neue Funktion checkSerial2Leftover(label) prueft vor jedem an den
    DFPlayer gesendeten Kommando Serial2.available(). Stehen noch Bytes im
    Empfangspuffer (Hinweis auf verspaetete/verlorene Antworten bzw.
    UART-Desync), schreibt webLogf() eine [DFPlayer]-Zeile mit Kommando-
    Label, Byteanzahl, Zeitstempel und einem seit Boot mitla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
    [Wecker_12v08.ino]
2026-08-10 Firmware 12v09-12v12: DFPlayer-Puffer-Desync und Ersatzalarm-Fallback
    - 12v09: DFPlayer Serial2-Puffer-Desync behoben (readStateDrained() liest
    alle wartenden Frames statt nur einen; Puffer-Drain vor playFolder in
    triggerAlarm())
    - 12v10: ALARM_MAX_RESTARTS 10 -> 3
    - 12v11: unbegrenzte Drain-Schleife aus 12v09 konnte bei getrenntem/
    defektem DFPlayer (floatende RX-Leitung) alarmTask einfrieren und einen
    watchdogTask-Reboot ohne Ersatzalarm auslösen - SERIAL2_DRAIN_MAX_BYTES
    begrenzt beide Drain-Schleifen
    - 12v12: watchdogTask setzt rtcRetryMagic jetzt auch selbst, wenn
    alarmTask waehrend eines laufenden triggerAlarm()-Versuchs einfriert
    (alarmTriggerInFlight-Marker), damit auc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
    [Wecker_12v09.ino, Wecker_12v10.ino, Wecker_12v11.ino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]
2026-08-10 Firmware 12v13: Root Cause DFPlayer-Hang gefunden - Fix in Bibliothek
    Backtrace des Hardware-TWDT-Resets vom 12v12-Vorfall dekodiert: der Hang
    sass in DFRobotDFPlayerMini::available() (Bibliothek, nicht Firmware) -
    die innere while(_serial->available())-Schleife hatte keine
    Zeitbegrenzung und blockierte bei anhaltendem Byte-Zustrom unbegrenzt,
    noch bevor waitAvailable() seinen eigenen Timeout pruefen konnte. Erklaert
    auch "CPU 1: IDLE1" im TWDT-Log (echter Systemstillstand). Die
    12v09-12v12-Fixes in der Firmware griffen deshalb nicht.
    Fix direkt in D:\Arduino\libraries\DFRobotDFPlayerMini\
    DFRobotDFPlayerMini.cpp angewendet (ausserhalb dieses Repos, daher hier
    nur dokumentiert in Software/B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
    [Wecker_12v13.ino]
2026-08-10 Firmware 12v14-12v19: DFPlayer-Puffer-Drain vollstaendig auf alle Befehle ausgeweitet
    Diverse Root-Cause-Fixes (TWDT-Haenger, Bibliotheks-Patch zurueckgenommen,
    Watchdog-Init-Reihenfolge, Log-Rauschen) sowie 12v19: Vorab-Drain vor
    DFPlayer-Kommandos war nur vor dem alarmspezifischen playFolder() aktiv;
    volume()/stop()/Testsound-playFolder() liefen ungedraint und konnten
    Restframes bis in die naechste Alarm-Verifikation hinein stehen lassen.
    Neue drainSerial2Pre() jetzt vor allen player.*-Aufrufen aktiv.
    [Wecker_12v14.ino, Wecker_12v15.ino, Wecker_12v16.ino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]
2026-08-10 Firmware 13v00: DFPlayer readState-Timing-Bug behoben, ACK-Modus deaktiviert
    Root Cause von "kein Start-Status nach playFolder" (st=-1) gefunden:
    DFRobotDFPlayerMini::readState() gibt bei jeder Nicht-Feedback-Frame-Art
    (z.B. unaufgeforderter Play-Finished-Meldung) sofort -1 zurueck, ohne auf
    die tatsaechliche Antwort zu warten. readStateDrained() wartet jetzt bis
    zu SERIAL2_FEEDBACK_GRACE_MS aktiv nach, statt sofort aufzugeben.
    ACK-Modus zusaetzlich deaktiviert (entfernt blockierende Wartelogik in
    sendStack() der Bibliothek). Dadurch wurde der if/else um player.begin()
    in setup() unreachable (begin() liefert ohne ACK unbedingt true) und
    wurde entfernt - Verbindungspruefung laeuft jetzt alle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
    [Wecker_12v19.ino, Wecker_13v00.ino]
2026-08-10 Firmware 13v00: ACK-Modus-Deaktivierung zurueckgenommen (Regression: Startsound fehlte)
    Ohne ACK sendet sendStack() der DFPlayer-Bibliothek volume()/EQ()/
    playFolder() in setup() nur noch mit pauschalem 10-ms-Delay statt auf die
    tatsaechliche Verarbeitung des vorherigen Befehls zu warten - direkt nach
    reset() kam der DFPlayer nicht mehr mit, der Startsound blieb aus.
    ACK bleibt daher aktiv (player.begin(Serial2, true, true)), if/else-
    Verbindungscheck in setup() wiederhergestellt. Der eigentliche Root-Cause-
    Fix (readStateDrained()-Gnadenfrist bei Nicht-Feedback-Frames) ist davon
    unabhaengig und bleibt unveraendert wirksam.
    [Wecker_13v00.ino]
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2026-08-18 DFPlayer-BUSY: Debounce fuer ALARM_RUNNING (dfPlayerIdleDebounced)
    Trotz RC-Filter (100us Zeitkonstante) bleibt ein Rest-Risiko fuer
    Stoerimpulse. Fuer die einzige unwiderrufliche Entscheidungsstelle
    (ALARM_RUNNING: Motor/Licht aus, State-Reset) neue Funktion
    dfPlayerIdleDebounced() - 3x Sampling im Abstand von 5ms, muss
    durchgehend "idle" melden. verifyPlayStarted()/S1-Handling bleiben bei
    einfachem dfPlayerBusy() (geringere Konsequenz eines Fehlreads).
    Firmware 20v02 archiviert, aktuell ist 20v03.
    [Wecker_20v02.ino, Wecker_20v03.ino]
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2026-08-18 Firmware 20v04: Audit-Reaktionsplan Schritt 1 (A1+A5) umgesetzt
    timeValid()-Gate verhindert Alarm-/Kuckuck-Auswertung auf ungueltiger
    (1970-)Uhr (A5). Alarmfaelligkeit von sec==0-Flanke auf tagesbezogene,
    pegelbasierte Pruefung (alarmDue()) mit Nachholfenster ALARM_CATCHUP_MIN
    (60 min) umgestellt - faengt Zeitspruenge, Reboots im Alarmfenster und
    die Maerz-Zeitumstellung ab, die zuvor den Alarm ersatzlos geloescht
    haben (A1). Faelligkeitspruefung zieht Alarm 2 automatisch nach, wenn
    er waehrend eines laufenden Alarm 1 faellig wird (A4). Kuckuck-Sperre
    von lastCuckooMin auf lastCuckooDay/lastCuckooHour umgestellt, verhindert
    doppelten Kuckuck bei der Oktober-Zeitumstellung (A6). triggerAlarm(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
    [Wecker_20v03.ino, Wecker_20v04.ino]
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2026-08-18 Firmware 20v06: Audit-Reaktionsplan Schritt 3 (B2) umgesetzt
    triggerAlarm() schreibt den RTC-Retry-Merker (rtcRetryMagic u.a.) jetzt
    direkt nach dem playerMutex-Take, vor playFolder()/verifyPlayStarted() -
    bisher wurde er nur im expliziten Fehlerpfad (bestaetigter ESP.restart())
    gesetzt. Ein Freeze/Reset irgendwo zwischen playFolder() und der ersten
    bestaetigten Wiedergabe in ALARM_RUNNING (inkl. des ALARM_POLL_MS-Fensters
    vor dem ersten Poll) verlor den Alarm bisher ersatzlos, weil kein
    RTC-Merker existierte.
    runAlarmMachine()/ALARM_RUNNING loescht den Merker an zwei Stellen: sobald
    der erste Poll playerStatus > 0 bestaetigt (fruehestmoeglich), zusaetzlich
    beim Alarmende (mp3Finished/runTi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
    [Wecker_20v05.ino, Wecker_20v06.ino]
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2026-08-18 Firmware 20v09: Audit-Reaktionsplan Schritt 6 (C3) umgesetzt
    verifyPlayStarted() liefert jetzt PLAY_OK/PLAY_NO_SOUND/PLAY_CRASHED statt
    bool. st==0 (Modul antwortet, "gestoppt" - typisch fuer "Datei nicht
    gefunden") und st==-1 (keine Antwort) wurden bisher identisch als Absturz
    behandelt und loesten beide ESP.restart() aus - ein Neustart behebt einen
    Datei-/Kartenfehler aber nicht. Nur wenn nie eine Antwort ankam
    (PLAY_CRASHED), rechtfertigt das noch einen Neustart. Kam mindestens
    einmal st==0 an (PLAY_NO_SOUND), laeuft der Alarm in denselben Erfolgspfad
    wie PLAY_OK (Motor/Licht), statt zwei sinnlose Reboots auszuloesen und
    danach still zu bleiben.
    Zusammen mit A3 verifiziert wie von der Re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
    [Wecker_20v08.ino, Wecker_20v09.ino]
2026-08-18 Firmware 20v10: Audit-Reaktionsplan Schritt 7 (C4) umgesetzt
    player.readFileCountsInFolder(1) (0x4E) statt player.readFileCounts()
    (0x48) - 1 in setup(). Bisher wurde die Gesamtdateizahl ueber alle Ordner
    abgefragt und mp3Count = c - 1 gerechnet, in der Annahme, genau eine
    Datei liege ausserhalb von Ordner 01 (der Startsound in Ordner 02) -
    zusaetzliche Dateien in Ordner 02 oder vom Betriebssystem beim Kopieren
    angelegte Extra-Dateien machten diese Zahl falsch und erlaubten die
    Auswahl einer nicht existierenden Alarmdatei (Zubringer zu C3s
    Reboot-Kaskade). Die ordnerbezogene Abfrage liefert die Anzahl direkt
    fuer Ordner 01, kein Rechnen/Raten mehr noetig.
    Bei Timeout der Bereitschaftspruefu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
    [Wecker_20v09.ino, Wecker_20v10.ino]
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2026-08-18 Firmware 20v12: Audit-Reaktionsplan Schritt 10 (E1, C6, C7, D2) umgesetzt
    E1: touchTask erzwingt Reset auf TS_IDLE inkl. Baseline-Neuerfassung, wenn
    ein Pad laenger als TOUCH_MAX_HOLD_MS (30 s) klemmt (Feuchtigkeit/Kabel-
    defekt) - bisher liefen TS_PRESSED/TS_REPEAT unbegrenzt weiter, z.B.
    zaehlte T4 die Lautstaerke bis 0 herunter. triggerAlarm() sendet
    zusaetzlich vor jedem Alarm player.volume() mit Untergrenze ALARM_MIN_VOL
    (10), unabhaengig vom zuletzt gesendeten Wert, ohne die persistierte
    Einstellung selbst zu veraendern.
    C6: Neues Flag alarmCancelRequested (S1, Sound-Vorschau-Stopp, Funktions-
    wahl-Menue setzen es ueber requestAlarmCancelIfActive() vor ihrem
    player.stop()). verifyPlay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
    [Wecker_20v11.ino, Wecker_20v12.ino]
2026-08-18 Firmware 20v13: Audit-Reaktionsplan Schritt 11 (zwei Zweizeiler) umgesetzt
    esp_task_wdt_add(NULL) in inputTask/displayTask/alarmTask sowie
    esp_task_wdt_init()/esp_task_wdt_reconfigure() in setup() werten jetzt
    den Rueckgabewert aus. Schlaegt die Anmeldung fehl, wird [FEHLER]
    geloggt statt wie bisher unbedingt "[TWDT] Hardware Watchdog aktiv" zu
    behaupten - genau der 12v15-Fehler (TWDT nie wirklich initialisiert,
    esp_task_wdt_reset() laeuft ins Leere) waere bisher symptomfrei
    geblieben.
    webLog("[NTP] Synchronisation OK") und snapTimeStr(snapNtpTime, ...)
    laufen jetzt nur noch bei tatsaechlichem NTP-Erfolg, nicht mehr
    unbedingt nach der Warteschleife (auch nach einem Timeout-break).
    Vorher ha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
    [Wecker_20v12.ino, Wecker_20v13.ino]
2026-08-19 Firmware 20v14: Compile-Fix PlayVerifyResult
    enum PlayVerifyResult vor die erste Verwendung (Dateianfang, nach den
    Includes) verschoben. Die Arduino-IDE fuegt automatisch generierte
    Funktionsprototypen ganz oben in die Datei ein, noch vor der bisherigen
    Definition bei verifyPlayStarted() weiter unten -- der generierte
    Prototyp kannte den Typ deshalb nicht ("does not name a type").
    [Wecker_20v14.ino]
2026-08-19 Firmware 20v15: Alarm-Abbruch durch Menue-Navigation und stale alarmCancelRequested behoben
    requestAlarmCancelIfActive() unterscheidet jetzt per includeStartup zwischen S1
    (Stopp-Taster, gilt auch waehrend der Anlaufverifikation) und reiner Menue-
    Navigation (Sound-Vorschau aus, Funktionswahl-Einstieg), die einen Alarm nur
    noch abbricht, wenn er bereits hoerbar laeuft. Zuvor konnte ein zeitgleich
    anlaufender Alarm durch voellig unbeteiligte Menue-Navigation lautlos
    abgebrochen werden (beobachtet 19.08.2026, Alarm 2 blieb komplett aus).
    triggerAlarm() setzt alarmCancelRequested zusaetzlich defensiv zurueck, bevor
    ein neuer Versuch startet - ein S1-Stopp eines laufenden Alarms hatte das Flag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
    [Wecker_20v15.ino]
2026-08-19 Firmware 20v16: Alarm-Tages-Sperre uebersteht Reset/Neuflashen (RTC-Speicher)
    Reset oder Neuflashen innerhalb des 60-Minuten-Nachholfensters
    (ALARM_CATCHUP_MIN) nach einer bereits erfolgreich gespielten Alarmzeit
    loeste beide Alarme sofort erneut aus, weil lastA1Day/lastA2Day bisher nur
    im RAM lagen und bei jedem Neustart zurueckgesetzt wurden. Tages-Sperre
    jetzt zusaetzlich im RTC_NOINIT-Speicher gespiegelt (rtcDayGuardMagic),
    nach demselben Muster wie rtcRetryMagic - unterscheidet echten Power-On
    (Nachholfenster bleibt aktiv) von Reset/Neuflashen (Sperre bleibt erhalten).
    20v15 nach Firmware_Versionshistorie archiviert.
    [Wecker_20v15.ino, Wecker_20v16.ino]
2026-08-19 Firmware 20v17: Alarm-Tages-Sperre im Flash-NVR, Compile-Fix, Sperre-Reset bei Zeitaenderung
    RTC_NOINIT_ATTR aus 20v16 uebersteht keinen EN-Pin-Reset (Reset-Taster,
    Neuflashen) und war damit wirkungslos gegen den Re-Trigger-Bug. Tages-Sperre
    lastA1Day/lastA2Day wird jetzt stattdessen im Flash-NVR persistiert.
    Zusaetzlich zwei waehrend des Tests gefundene Bugs behoben: Deklaration von
    lastA1Day/lastA2Day stand nach ihrer ersten Verwendung in writeNVR()/
    readNVR() (Compile-Fehler), und die Sperre blockte nach einer im Menue
    geaenderten Alarmzeit den Alarm faelschlich fuer den Rest des Tages.
    [Wecker_20v16.ino, Wecker_20v17.ino]
2026-08-19 Firmware 20v18: Web-Log-Fix fehlende Leerzeile vor Verbindungs-Ueberschrift
    #log fehlte anders als #dflog das margin-bottom:16px im Web-Log-CSS,
    dadurch kein Abstand zur folgenden Ueberschrift "Verbindung - letzter
    WiFi Reconnect / NTP Sync". 20v17 nach Firmware_Versionshistorie
    archiviert.
    [Wecker_20v17.ino, Wecker_20v18.ino]
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2026-08-21 Hardware 2v0: KiCad-Projekt/Schaltplan-PDF hinzugefügt, Motor-Regler MCP1700T-3302E/TO (Firmware 20v20)
    Motor-Rail (E2/GPIO26) wird jetzt über LDO MCP1700T-3302E/TO auf 3,3V
    geregelt statt direkt an 5V zu liegen; Freilaufdiode korrigiert auf 1N4448.
    Löst die bei 20v19 offene Prüffrage zur Kickstart-Überspannung – voller
    PWM-Regelumfang 0..255 ist ohne Begrenzung nutzbar. 20v19-Stand nach
    Firmware_Versionshistorie archiviert. Neues KiCad-Projekt Wecker_2v0 und
    Schaltplan-PDF ergänzt.
    [Wecker_2v0.kicad_pcb, Wecker_2v0.kicad_sch]
2026-08-21 Firmware 20v21: Alarm-Fälligkeit an Zeitumstellungstagen korrigiert
    Weckzeit zwischen 02:00:00-02:59:59 wahrt jetzt den geplanten
    zeitlichen Abstand zum nachfolgenden Termin. Frühjahr: um 1h
    vorgezogen (Stunde existiert nicht als Wanduhrzeit, vorher bis zu
    59 Min. zu spät). Herbst: löst erst beim zweiten Durchlauf durch
    die doppelte Stunde aus statt beim ersten (vorher Ruhezeit bis zu
    60 Min. zu kurz). Neue updateDstDayFlags() erkennt beide Tage
    TZ-generisch über mktime()/tm_isdst.
    [Wecker_20v20.ino]
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2026-08-25 Firmware 20v22: Bugfix Weckzeit-Verstellung löst Alarm nicht mehr vorzeitig aus
    Tages-Sperre (lastA1Day/lastA2Day) wurde bisher bei jedem Stunde+/Minute+-
    Tastendruck aufgehoben statt erst beim Verlassen der Alarm-Seite. Beim
    Durchscrollen einer neuen Weckzeit lief der Wert dadurch durch Zwischenstände,
    von denen manche sofort als fällig erkannt wurden und den Alarm mitten in der
    Eingabe auslösten. Aufhebung jetzt erst in uiTransition() beim tatsächlichen
    Seitenwechsel.
    Zusätzlich (ohne Versionsänderung): Sound-Auswahl (Seite 3/4) startet jetzt
    bei der aktuell zugewiesenen mp3 statt immer bei 1.
    [Wecker_20v22.ino]
2026-08-25 Firmware 20v23: Bugfix Sound-2-Vorschau spielt beim Seitenaufruf sofort ab
    Beim Betreten der Seite "Sound 2 wählen" (menu()/Case 4) fehlte das
    Zurücksetzen von sound2_on, das Case 3 für sound1_on/sound2_on bereits
    macht. War die Vorschau von einem früheren Seitenbesuch noch aktiv,
    startete checkboxSound() beim Neuzeichnen sofort wieder player.playFolder().
    [Wecker_20v23.ino]
2026-08-25 Firmware 20v25: Bugfix Sound-Vorschau-Stopp bei belegtem Mutex nachgeholt
    player.stop() in checkboxSound() (Sound 1/2 Vorschau ausschalten) schlug
    bei belegtem playerMutex (>50 ms, z.B. waehrend laufendem Alarm-Poll)
    folgenlos fehl - Checkbox zeigte "aus", DFPlayer spielte unbemerkt weiter
    und "blutete" beim Weiterschalten bis zur naechsten Sound-Seite durch
    (gemeldet 25.08.2026). Neues Flag pendingPlayerStopRetry: inputTask holt
    den Stop danach ausserhalb von displayMutex mit groesserem Timeout (300 ms)
    nach.
    [Wecker_20v25.ino]
2026-08-25 Firmware 20v26: Bugfix beide Sound-Vorschauen spielen sofort bei Seitenaufruf
    player.stop() in checkboxSound() nur noch senden, wenn dfPlayerBusy()
    tatsaechlich beschaeftigt meldet - ein stop()-Kommando an den leerlaufenden
    DFPlayer loeste offenbar selbst eine ungewollte Wiedergabe aus.
    [Wecker_20v26.ino]
2026-08-25 Firmware 20v27: Bugfix Tages-Sperre hob sich bereits bei reinem Seitenbesuch auf
    uiTransition() hob lastA1Day/lastA2Day beim Verlassen von "Alarm 1/2
    einstellen" bisher immer auf, auch ohne T3/T4-Aenderung. Lag die Weckzeit
    im Nachholfenster (ALARM_CATCHUP_MIN) in der Vergangenheit, loeste der
    echte Alarm dadurch beim naechsten Poll erneut aus - reproduzierbar ueber
    den 20s-Auto-Ruecksprung sowie beim Weiterblaettern zur Sound-Seite.
    Neue Flags alarm1TimeEdited/alarm2TimeEdited beschraenken das Aufheben
    der Sperre auf tatsaechliche Zeitaenderungen.
    [Wecker_20v27.ino]
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2026-09-16 Firmware 20v30: Reset-Ursache loggen, DFPlayer-Log entrauscht
    Boot loggt jetzt die Ursache des letzten Resets (esp_reset_reason())
    via Serial und Web-Log. checkSerial2Leftover() meldet Serial2-
    Restbytes erst ab SERIAL2_LEFTOVER_LOG_THRESHOLD (20), die Retry-
    Meldung in verifyPlayStarted() erscheint erst ab dem 2. Versuch -
    beides bisher zu geschwätzig im Normalbetrieb.
    [Wecker_20v30.ino]
2026-09-16 Firmware 20v31: Log-Seite neu sortiert, Reset-Ursache ans Ende verschoben
    Abschnitte auf der Log-Seite (/) folgen jetzt fester Reihenfolge: Allgemeines
    Log, Verbindung, Touch Baseline, Stack High-Water Marks, DFPlayer,
    Muehlrad-Motor. Die Reset-Ursache wird als "[RESET] Ursache: ..." (statt
    "Letzter Reset: ...") geloggt und im Allgemeinen Log immer als letzte Zeile
    angezeigt, unabhaengig vom chronologischen Boot-Zeitpunkt.
    [Wecker_20v31.ino]
2026-09-27 Firmware 20v32: Reset-Ursache im Web-Log direkt nach resetCount einordnen
    Vorher stand [RESET] Ursache: ... als letzte Zeile im Allgemeinen Log,
    jetzt direkt hinter [RESET] resetCount: ..., gefolgt von den Meldungen
    der aktuellen Laufzeit.
    [Wecker_20v32.ino]
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
